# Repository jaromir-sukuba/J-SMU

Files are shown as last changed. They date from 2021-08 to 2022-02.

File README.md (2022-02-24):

## What is SMU?
In case you don't know what is SMU, take a look [here](https://en.wikipedia.org/wiki/Source_measure_unit)
Basically, it's glorified power supply, able to both source voltage (and measure current, with current limit) or source current (and measure voltage, with voltage limit), usually in wide range of voltages and currents. It usually works in four quadrants, meaning it's able to both sink and source power. When set to zero output voltage, SMU acts as ammeter and when set to zero current, acts as voltmeter.
It's very useful as general purpose PSU with precise setpoint adjustment, as a tool for measuring high resistances, for testing semiconductors in wide range of voltages or currents. You can do all this things using classic lab tools (PSU, ammeter, voltmeter, switches), SMU offers this all in single package and is designed to be interconnected with computer to automate the tasks.

## What is in this repository?
+ BOM - Bill Of Material. Contains list of components and materials used in this device. Separated by PCBs.
+ firmware - firmware for two microcontrollers running in JSMU
+ mechanical - mechanical parts I designed for this SMU
+ media - minimal amount of pictures
+ pcb
    + pcb_gerber - gerber data in zip files, ready to be manufactured
    + pcb_ibom - interactive BOM files, helping when populating the boards, also helpful to get familiar with the project
    + pcb_kicad - PCB source files, made in Kicad 5.1.10
    + schematics_pdf - all schematics in PDF format, for easy viewing or printing

## What is JSMU?
JSMU is open source implementation of SMU, inspired by Keithley 236 and Dave Erickson's [DIY SMU](http://www.djerickson.com/diy_smu/index.html)

## How to use it?
User and calibration guide is in the process and will be released soon(TM).

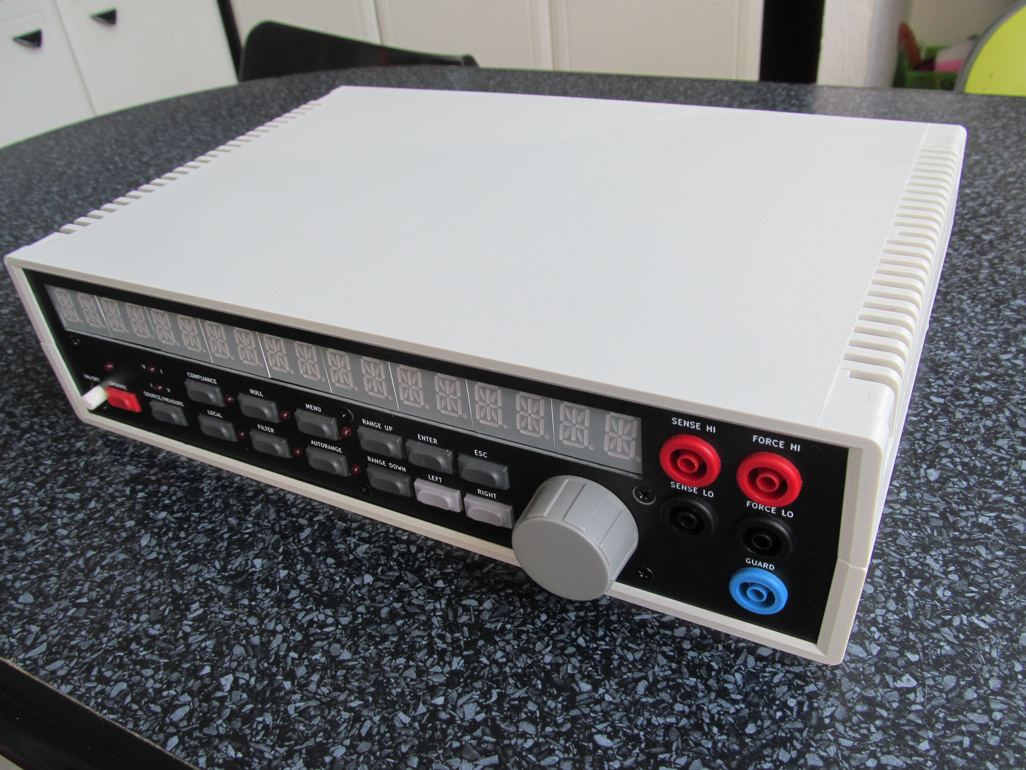
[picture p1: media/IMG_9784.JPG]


Parameters:
+ Voltage ranges 12V and 120V (bipolar)
+ Current ranges 1uA, 10uA, 100uA, 1mA, 10mA, 100mA (bipolar)
+ Minimal set voltage step - 1mV
+ Minimal set current step - 100pA
+ Voltage resolution - 100uV
+ Current resolution - 1pA

JSMU is designed to work as standalone device, but can be connected to computer via USB, and controlled via simple commands in SCPI form, similar to Keithley 2xxx series SMUs.

More pictures can be found in [imgur gallery](https://imgur.com/a/rR8cIFG)

## FAQ
Q: I noticed you used AT90S4434, made in 1999 as controller for your analog board.
- A: Yes, that is correct observation. Two reasons led me to this decision; first of all, I like to do weird design choices from a time to time. Let's call it design dissonances. Secondly, when this design was born (winter 2020/2021-summer 2021) component crisis was (and still is, in the time of writing this) quite strong and I was limited by what components were available. I tried to choose as much components as were available in my junkbox as possible. AT90S4434 can be replaced by AtMega8535 after minor source touchup and recompiling.

Q: dsPIC33FJ128GP306 is also weird choice here
- A: Yes, again, I was fishing in my junkbox. A lot of open-source project go with STM32, but at the time of designing, majority of component suppliers had more-less zero stock of more common STM32's. Once the situation changes, I can think of respinning the D1 board for STM32 and port the code. I already did porting from MC9S08BG60 to dsPIC; perhaps I'll manage another port too.

Q: What is the point of using 14-segment alphanumeric display in 2021, when many test instruments are using graphic LCDs with touchscreens?
- A: Apart from the fact I don't like touch screens on test instruments, I intentionally tried to keep the design in kind-of similar feel than Keithley 236. It's a thing of personal taste.

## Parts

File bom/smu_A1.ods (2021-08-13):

Item | Qty | Reference(s) | Value | Footprint | supplier | link | comment
1 | 16 | C1, C4, C24, C26, C27, C34, C35, C36, C38, C40, C43, C48, C50, C51, C52, C56 | 100n | Capacitor_SMD:C_0805_2012Metric_Pad1.18x1.45mm_HandSolder | GEN | Generic 0805 capacitor
2 | 10 | C2, C3, C5, C6, C9, C10, C11, C12, C13, C14 | 100n | Capacitor_SMD:C_0603_1608Metric_Pad1.08x0.95mm_HandSolder | GEN | Generic 0603 capacitor
3 | 3 | C7, C8, C15 | 22u | Capacitor_Tantalum_SMD:CP_EIA-6032-28_Kemet-C_Pad2.25x2.35mm_HandSolder | TME | https://www.tme.eu/sk/details/293d226x9025c2te3/tantalove-kondenzatory-smd/vishay/
4 | 2 | C16, C17 | 270p | Capacitor_SMD:C_1206_3216Metric_Pad1.33x1.80mm_HandSolder | MOUS | https://www.mouser.sk/ProductDetail/AVX/08055A271JAT2A/?qs=o2Ryk6%252BtLJtmWp8Z%252BRBEFA%3D%3D
5 | 3 | C18, C19, C20 | 15p | Capacitor_SMD:C_0805_2012Metric_Pad1.18x1.45mm_HandSolder | MOUS | https://www.mouser.sk/ProductDetail/TDK/CGA5C4C0G2J271J060AA/?qs=FxQuwy19cyCFaP39URlg4w%3D%3D
6 | 1 | C21 | 10n | Capacitor_SMD:C_0805_2012Metric_Pad1.18x1.45mm_HandSolder | GEN | Generic 0805 capacitor
7 | 2 | C22, C25 | 150p | Capacitor_SMD:C_0805_2012Metric_Pad1.18x1.45mm_HandSolder | MOUS | https://www.mouser.sk/ProductDetail/Yageo/CC0805JRNPOYBN151/?qs=WS5Jv%252B%252Bx1qViSs68xPRhng%3D%3D
8 | 1 | C23 | 22p | Capacitor_SMD:C_1206_3216Metric_Pad1.33x1.80mm_HandSolder | MOUS | https://www.mouser.sk/ProductDetail/TDK/C3216C0G2J221J060AA/?qs=NRhsANhppD%252B8bxP3OkeJTg%3D%3D
9 | 1 | C28 | 270p | Capacitor_SMD:C_0805_2012Metric_Pad1.18x1.45mm_HandSolder | GEN | Generic 0805 capacitor
10 | 3 | C29, C30, C31 | 680p | Capacitor_SMD:C_0805_2012Metric_Pad1.18x1.45mm_HandSolder | GEN | Generic 0805 capacitor
11 | 3 | C32, C33, C37 | 22p | Capacitor_SMD:C_0805_2012Metric_Pad1.18x1.45mm_HandSolder | GEN | Generic 0805 capacitor
12 | 3 | C39, C49, C57 | 1u | Capacitor_SMD:C_0805_2012Metric_Pad1.18x1.45mm_HandSolder | GEN | Generic 0805 capacitor
13 | 1 | C41 | 1u | Capacitor_THT:C_Rect_L7.0mm_W3.5mm_P5.00mm | TME | https://www.tme.eu/sk/details/mks2-1u_50/kondenzatory-tht-polyesterove/wima/mks2b041001c00kssd/
14 | 1 | C42 | 4u7 | Capacitor_Tantalum_SMD:CP_EIA-3216-18_Kemet-A_Pad1.58x1.35mm_HandSolder | TME | https://www.tme.eu/sk/details/t491a475k020at/tantalove-kondenzatory-smd/kemet/
15 | 7 | C44, C45, C46, C47, C53, C54, C55 | 1n | Capacitor_SMD:C_0805_2012Metric_Pad1.18x1.45mm_HandSolder | GEN | Generic 0805 capacitor
16 | 1 | D1 | BAV70 | Package_TO_SOT_SMD:SOT-23 | TME | https://www.tme.eu/sk/details/bav70lt1g/univerzalne-diody-smd/on-semiconductor/
17 | 2 | D2, D3 | BAV99 | Package_TO_SOT_SMD:SOT-23 | TME | https://www.tme.eu/sk/details/bav99lt1g/univerzalne-diody-smd/on-semiconductor/
18 | 4 | D4, D5, D6, D7 | BAV199 | Package_TO_SOT_SMD:SOT-23 | TME | https://www.tme.eu/sk/details/bav199.215/univerzalne-diody-smd/nexperia/
19 | 2 | D8, D9 | LED | LED_SMD:LED_0805_2012Metric_Pad1.15x1.40mm_HandSolder | GEN | Any color you like
20 | 4 | FB1, FB2, FB3, FB4 | Ferrite_Bead_Small | Inductor_SMD:L_0805_2012Metric_Pad1.15x1.40mm_HandSolder | TME | https://www.tme.eu/sk/details/blm31af700sn1l/koraliky-s-feritom/murata/
21 | 4 | H1, H2, H3, H4 | MountingHole | MountingHole:MountingHole_3.2mm_M3_ISO7380_Pad | DNP | DNP
22 | 1 | J1 | Conn_01x03_Male | Connector_Molex:Molex_KK-254_AE-6410-03A_1x03_P2.54mm_Vertical | TME | https://www.tme.eu/sk/details/ns25-w3p/signalove-konektory-raster-2-54mm/ninigi/
23 | 1 | J2 | Conn_01x03_Male | Connector_Molex:Molex_KK-396_A-41791-0003_1x03_P3.96mm_Vertical | TME | https://www.tme.eu/sk/details/a3960wv-03p/signalove-konektory-raster-3-96mm/joint-tech/
24 | 1 | J3 | Conn_01x05_Male | Connector_Molex:Molex_KK-254_AE-6410-05A_1x05_P2.54mm_Vertical | TME | https://www.tme.eu/sk/details/ns25-w5p/signalove-konektory-raster-2-54mm/ninigi/
25 | 1 | J4 | Conn_01x06_Male | Connector_Molex:Molex_KK-396_A-41791-0006_1x06_P3.96mm_Vertical | TME | https://www.tme.eu/sk/details/a3960wv-06p/signalove-konektory-raster-3-96mm/joint-tech/
26 | 1 | J5 | Conn_01x05_Male | Connector_Molex:Molex_KK-396_A-41791-0005_1x05_P3.96mm_Vertical | TME | https://www.tme.eu/sk/details/a3960wv-05p/signalove-konektory-raster-3-96mm/joint-tech/
27 | 1 | J6 | Conn_02x03_Odd_Even | Connector_IDC:IDC-Header_2x03_P2.54mm_Vertical | TME | https://www.tme.eu/sk/details/75869-331lf/konektory-idc/amphenol-icc/
28 | 1 | J7 | Conn_01x06_Male | Connector_PinHeader_2.00mm:PinHeader_1x06_P2.00mm_Vertical | DNP | DNP
29 | 2 | K1, K2 | EC2-5NU | Relay_THT:Relay_DPDT_Kemet_EC2 | MOUS | https://www.mouser.sk/ProductDetail/KEMET/EC2-12NU?qs=BenOyfdfArqRFl%252BOm5Bdvw==
30 | 2 | Q1, Q2 | BC847 | Package_TO_SOT_SMD:SOT-23 | TME | https://www.tme.eu/sk/details/bc847.215/tranzistory-npn-smd/nexperia/ | may use BC817 instead
31 | 9 | R1, R2, R3, R6, R20, R32, R36, R37, R79 | 2k2 | Resistor_SMD:R_0805_2012Metric_Pad1.20x1.40mm_HandSolder | GEN | Generic 0805 resistor
32 | 2 | R4, R5 | 33R | Resistor_SMD:R_0805_2012Metric_Pad1.20x1.40mm_HandSolder | GEN | Generic 0805 resistor
33 | 23 | R7, R8, R9, R10, R11, R12, R28, R31, R33, R34, R35, R63, R64, R66, R68, R70, R71, R73, R74, R75, R76, R77, R78 | 10k00 | Resistor_SMD:R_0805_2012Metric_Pad1.20x1.40mm_HandSolder | TME | https://www.tme.eu/sk/details/era6aeb103v/presne-rezistory-smd-0805/panasonic/
34 | 3 | R13, R14, R16 | 20k | Resistor_SMD:R_0805_2012Metric_Pad1.20x1.40mm_HandSolder | GEN | Generic 0805 resistor
35 | 2 | R15, R26 | 4k7 | Resistor_SMD:R_0805_2012Metric_Pad1.20x1.40mm_HandSolder | GEN | Generic 0805 resistor
36 | 7 | R17, R19, R21, R27, R51, R55, R60 | 10k1 | Resistor_SMD:R_0805_2012Metric_Pad1.20x1.40mm_HandSolder | GEN | Generic 0805 resistor
37 | 1 | R18 | 30k | Resistor_SMD:R_0805_2012Metric_Pad1.20x1.40mm_HandSolder | GEN | Generic 0805 resistor
38 | 1 | R22 | 200k | Resistor_SMD:R_1206_3216Metric_Pad1.30x1.75mm_HandSolder | MOUS | https://www.mouser.sk/ProductDetail/Bourns/CR1206-JW-204ELF/
39 | 3 | R23, R56, R58 | 1k | Resistor_SMD:R_0805_2012Metric_Pad1.20x1.40mm_HandSolder | GEN | Generic 0805 resistor
40 | 1 | R24 | 4k7 | Resistor_SMD:R_1206_3216Metric_Pad1.30x1.75mm_HandSolder | MOUS | https://www.mouser.sk/ProductDetail/Vishay-Dale/CRCW12064K70JNEAC/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
41 | 1 | R25 | 10k1 | Resistor_SMD:R_1206_3216Metric_Pad1.30x1.75mm_HandSolder | MOUS | https://www.mouser.sk/ProductDetail/Vishay-Dale/CRCW120610K0FKEAC/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
42 | 1 | R29 | 300k00 | Resistor_SMD:R_1206_3216Metric_Pad1.30x1.75mm_HandSolder | TME | https://www.tme.eu/sk/details/ar1206-300k-0.1%25/presne-rezistory-smd-1206/viking/ar06btcv3003/
43 | 1 | R30 | 22k10 | Resistor_SMD:R_0805_2012Metric_Pad1.20x1.40mm_HandSolder | TME | https://www.tme.eu/sk/details/arg0805-22k-0.5%25/presne-rezistory-smd-0805/viking/arg05dtc2202/
44 | 1 | R38 | 2M00 | Resistor_SMD:R_1206_3216Metric_Pad1.30x1.75mm_HandSolder | MOUS | https://www.mouser.sk/ProductDetail/TE-Connectivity-Holsworthy/CPF0805B2M0E?qs=CXI0wBT1M2hICTuUd%2FIMfQ%3D%3D
45 | 1 | R39 | 200k00 | Resistor_SMD:R_0805_2012Metric_Pad1.20x1.40mm_HandSolder | MOUS | https://www.mouser.sk/ProductDetail/TE-Connectivity-Holsworthy/RQ73C2A200KBTDF
46 | 1 | R40 | 20k5 | Resistor_SMD:R_0805_2012Metric_Pad1.20x1.40mm_HandSolder | MOUS | https://www.mouser.sk/ProductDetail/Yageo/RT0805BRD0720K5L/?qs=Q0GlgB%252BOca%252BxfnVdr3eu0w%3D%3D
47 | 2 | R41, R83 | 2k00 | Resistor_SMD:R_0805_2012Metric_Pad1.20x1.40mm_HandSolder | TME | https://www.tme.eu/sk/details/ar0805-2k-0.1%25/presne-rezistory-smd-0805/viking/ar05btcw2001/
48 | 1 | R42 | 200R00 | Resistor_SMD:R_MiniMELF_MMA-0204 | MOUS | https://www.mouser.sk/ProductDetail/Vishay-Beyschlag/MMA02040E2000BB300?qs=YmMt7wOBEV7xAuhhDxeBhQ==
49 | 4 | R43, R44, R45, R46 | 78R | Resistor_SMD:R_1206_3216Metric_Pad1.30x1.75mm_HandSolder | MOUS | https://www.mouser.sk/ProductDetail/TE-Connectivity-Holsworthy/RP73D2B78R7BTG
50 | 4 | R47, R48, R49, R50 | 4R70 | Resistor_SMD:R_2512_6332Metric | DNP | DNP
51 | 2 | R52, R54 | 100k00 | Resistor_SMD:R_0805_2012Metric_Pad1.20x1.40mm_HandSolder | MOUS | https://www.mouser.sk/ProductDetail/TE-Connectivity-Holsworthy/RQ73C2A100KBTD?qs=gZXFycFWdAMRVPmJtg9N9A%3D%3D
52 | 2 | R53, R57 | 250k00 | Resistor_SMD:R_0805_2012Metric_Pad1.20x1.40mm_HandSolder | MOUS | https://www.mouser.sk/ProductDetail/TE-Connectivity-Holsworthy/RQ73C2A249KBTDF
53 | 1 | R59 | 1k | Resistor_THT:R_Axial_DIN0309_L9.0mm_D3.2mm_P12.70mm_Horizontal | TME | https://www.tme.eu/sk/details/pr01-1k/metalizovane-rezistory-tht-1w/vishay/pr01000101001ja100/
54 | 2 | R61, R62 | 680R | Resistor_SMD:R_0805_2012Metric_Pad1.20x1.40mm_HandSolder | GEN | Generic 0805 resistor
55 | 1 | R65 | 2R2 | Resistor_SMD:R_0805_2012Metric_Pad1.20x1.40mm_HandSolder | GEN | Generic 0805 resistor
56 | 4 | R67, R69, R81, R82 | 21k50 | Resistor_SMD:R_0805_2012Metric_Pad1.20x1.40mm_HandSolder | MOUS | https://www.mouser.sk/ProductDetail/Yageo/RT0805BRD0721K5L/?qs=4CyHz7GXqSgMQiImMmG4dg%3D%3D
57 | 1 | R72 | 1M6 | Resistor_SMD:R_0805_2012Metric_Pad1.20x1.40mm_HandSolder | DNP | DNP
58 | 1 | R80 | 20k50 | Resistor_SMD:R_0805_2012Metric_Pad1.20x1.40mm_HandSolder | MOUS | https://www.mouser.sk/ProductDetail/Yageo/RT0805BRD0720K5L/?qs=Q0GlgB%252BOca%252BxfnVdr3eu0w%3D%3D
59 | 1 | U1 | uA7805 | Package_TO_SOT_SMD:TO-263-3_TabPin2 | TME | https://www.tme.eu/sk/details/l7805abd2t/stabilizatory-napatia-neregulovane/stmicroelectronics/l7805abd2t-tr/
60 | 1 | U2 | DG411xY | Package_SO:SOIC-16_3.9x9.9mm_P1.27mm | TME | https://www.tme.eu/sk/details/dg444dy/multiplexory-a-analogove-prepinace/vishay/
61 | 2 | U3, U28 | OPA202 | Package_SO:SOIC-8_3.9x4.9mm_P1.27mm | MOUS | https://www.mouser.sk/ProductDetail/Texas-Instruments/OPA202IDR
62 | 11 | U4, U5, U6, U8, U9, U10, U11, U13, U14, U19, U20 | OPA140 | Package_SO:SOIC-8_3.9x4.9mm_P1.27mm | MOUS | https://www.mouser.sk/ProductDetail/Texas-Instruments/OPA140AIDR/?qs=nHis3Socmoq8P2a2dEtOew%3D%3D
63 | 1 | U7 | LM393 | Package_SO:SOIC-8_3.9x4.9mm_P1.27mm | TME | https://www.tme.eu/sk/details/lm393dt/komparatory-smd/stmicroelectronics/
64 | 1 | U12 | TLP170D | Package_SO:SO-4_4.4x3.9mm_P2.54mm | MOUS | https://www.mouser.sk/ProductDetail/Toshiba/TLP170DF/?qs=sRdS99IVWC82vTD8bl8sFg%3D%3D
65 | 2 | U15, U16 | DG444 | Package_SO:SOIC-16_3.9x9.9mm_P1.27mm | TME | https://www.tme.eu/sk/details/dg444dy/multiplexory-a-analogove-prepinace/vishay/
66 | 1 | U17 | AQY221R | Package_SO:SO-4_4.4x3.9mm_P2.54mm | MOUS | https://www.mouser.sk/ProductDetail/Panasonic-Industrial-Devices/AQY221R2SX/?qs=Wn4D5qJAqBI5HElhh1lUZQ%3D%3D
67 | 1 | U18 | DNP | Package_SO:SO-4_4.4x3.9mm_P2.54mm | DNP | DNP
68 | 1 | U21 | TL071 | Package_SO:SOIC-8_3.9x4.9mm_P1.27mm | TME | https://www.tme.eu/sk/details/tl071acd/operacne-zosilnovace-smd/texas-instruments/
69 | 1 | U22 | ISO7341C | Package_SO:SOIC-16W_7.5x10.3mm_P1.27mm | MOUS | https://www.mouser.sk/ProductDetail/Texas-Instruments/ISO7341CDW?qs=asCBFxFfL1QXhBq0uR%2FJmA%3D%3D
70 | 1 | U23 | ATmega8535-16JU | Package_LCC:PLCC-44 | MOUS | https://www.mouser.sk/ProductDetail/Microchip-Technology-Atmel/ATMEGA8535L-8JUR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
71 | 1 | U24 | MAX6225 | Package_DIP:DIP-8_W7.62mm_Socket | MOUS | https://www.mouser.sk/ProductDetail/Maxim-Integrated/MAX6225ACPA%2b?qs=GxOUx7aO6nyrNG4h06TzmA%3D%3D | Other alernatives are possible, I used this because I had it in my junkbox
72 | 1 | U25 | OPA2333 | Package_SO:SOIC-8_3.9x4.9mm_P1.27mm | MOUS | https://www.mouser.sk/ProductDetail/Texas-Instruments/OPA2333AID?qs=7nS3%252BbEUL6s6Q5%2FuexU7%252Bg%3D%3D
73 | 1 | U26 | LTC2057 | Package_SO:SOIC-8_3.9x4.9mm_P1.27mm | MOUS | https://www.mouser.sk/ProductDetail/Analog-Devices/LTC2057IS8PBF?qs=hVkxg5c3xu96mZ%252BCpnMNfA%3D%3D
74 | 1 | U27 | AD5686 | Package_SO:TSSOP-16_4.4x5mm_P0.65mm | MOUS | https://www.mouser.sk/ProductDetail/Analog-Devices/AD5686ARUZ?qs=NmRFExCfTkE223vD8YE3tA%3D%3D
75 | 2 | U29, U30 | OP07 | Package_SO:SOIC-8_3.9x4.9mm_P1.27mm | TME | https://www.tme.eu/sk/details/op07cdr/operacne-zosilnovace-smd/texas-instruments/
76 | 1 | U31 | CPC1018N | Package_SO:SO-4_4.4x3.9mm_P2.54mm | MOUS | https://www.mouser.sk/ProductDetail/IXYS-Integrated-Circuits/CPC1018N/?qs=mzRxyRlhVdtKZF03PS27Mg%3D%3D
77 | 1 | U32 | ad7177 | Package_SO:TSSOP-24_4.4x7.8mm_P0.65mm | MOUS | https://www.mouser.sk/ProductDetail/Analog-Devices/AD7177-2BRUZ?qs=251aVPftrjH6MVeTWiYQww%3D%3D
78 | 1 | Y1 | Crystal | Crystal:Crystal_HC49-4H_Vertical | TME | https://www.tme.eu/sk/details/7.3728m-49s-sr/krystalove-rezonatory-tht/sr-passives/

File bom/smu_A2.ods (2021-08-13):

Item | Qty | Reference(s) | Value | Footprint | supplier | link | comment
1 | 4 | C1, C2, C5, C6 | 1n | Capacitor_SMD:C_1206_3216Metric_Pad1.33x1.80mm_HandSolder | TME | https://www.tme.eu/sk/details/c1206c102jcgactu/kondenzatory-mlcc-smd-1206/kemet/
2 | 2 | C3, C4 | 2n2 | Capacitor_SMD:C_1206_3216Metric_Pad1.33x1.80mm_HandSolder | TME | https://www.tme.eu/sk/details/c1206c222jbgactu/kondenzatory-mlcc-smd-1206/kemet/
3 | 1 | C7 | 2n2 | Capacitor_THT:C_Axial_L19.0mm_D7.5mm_P25.00mm_Horizontal | TBD
4 | 2 | D1, D2 | BAV99 | Package_TO_SOT_SMD:SOT-23 | TME | https://www.tme.eu/sk/details/bav99lt1g/univerzalne-diody-smd/on-semiconductor/
5 | 4 | D3, D4, D5, D6 | BAV199 | Package_TO_SOT_SMD:SOT-23 | TME | https://www.tme.eu/sk/details/bav199.215/univerzalne-diody-smd/nexperia/
6 | 2 | D7, D8 | 1N4007 | Diode_THT:D_DO-41_SOD81_P10.16mm_Horizontal | TME | https://www.tme.eu/sk/details/1n4007/univerzalne-diody-tht/
7 | 4 | H1, H2, H3, H4 | MountingHole | MountingHole:MountingHole_3.2mm_M3_ISO14580_Pad | DNP | DNP
8 | 1 | J1 | Conn_01x06_Male | Connector_Molex:Molex_KK-396_A-41791-0006_1x06_P3.96mm_Vertical | TME | https://www.tme.eu/sk/details/a3960wv-06p/signalove-konektory-raster-3-96mm/joint-tech/
9 | 1 | J2 | Conn_01x03_Male | Connector_Molex:Molex_KK-396_A-41791-0003_1x03_P3.96mm_Vertical | TME | https://www.tme.eu/sk/details/a3960wv-03p/signalove-konektory-raster-3-96mm/joint-tech/
10 | 4 | Q1, Q2, Q9, Q10 | 2N7002 | Package_TO_SOT_SMD:SOT-23 | TME | https://www.tme.eu/sk/details/2n7002/tranzistory-s-kanalom-n-smd/on-semiconductor/
11 | 3 | Q3, Q4, Q8 | BC807 | Package_TO_SOT_SMD:SOT-23 | TME | https://www.tme.eu/sk/details/bc807-16-7-f/tranzistory-pnp-smd/diodes-incorporated/bc807-16/
12 | 1 | Q5 | BC160 | Package_TO_SOT_THT:TO-39-3 | TME | https://www.tme.eu/sk/details/bc160-10-cdi/tranzistory-pnp-tht/cdil/bc160-10/
13 | 1 | Q6 | BC140 | Package_TO_SOT_THT:TO-39-3 | TME | https://www.tme.eu/sk/details/bc140-10-cdi/tranzistory-npn-tht/cdil/bc140-10/
14 | 1 | Q7 | BC817 | Package_TO_SOT_SMD:SOT-23 | TME | https://www.tme.eu/sk/details/bc817-16-7-f/tranzistory-npn-smd/diodes-incorporated/bc817-16/
15 | 2 | Q11, Q12 | IRF620 | Package_TO_SOT_THT:TO-220-3_Vertical | TME | https://www.tme.eu/sk/details/irf620pbf/tranzistory-s-kanalom-n-tht/vishay/
16 | 2 | Q13, Q14 | IRF9620 | Package_TO_SOT_THT:TO-220-3_Vertical | TME | https://www.tme.eu/sk/details/irf9620pbf/tranzistory-s-kanalom-p-tht/vishay/
17 | 1 | Q15 | TIP41 | Package_TO_SOT_THT:TO-220-3_Vertical | MOUS | https://www.mouser.sk/ProductDetail/STMicroelectronics/TIP41C/?qs=ljbEvF4DwOPALsfJVTZHww%3D%3D
18 | 1 | Q16 | TIP42 | Package_TO_SOT_THT:TO-220-3_Vertical | MOUS | https://www.mouser.sk/ProductDetail/STMicroelectronics/TIP42C/?qs=ljbEvF4DwONRQQLu%2Fjht%252Bw%3D%3D
19 | 2 | Q17, Q18 | IRF7403 | Package_SO:SOIC-8_3.9x4.9mm_P1.27mm | MOUS | https://www.tme.eu/sk/details/irf7403trpbf/tranzistory-s-kanalom-n-smd/infineon-technologies/
20 | 4 | R1, R2, R29, R30 | 1k | Capacitor_SMD:C_0805_2012Metric_Pad1.18x1.45mm_HandSolder | GEN | Generic 0805 resistor
21 | 6 | R3, R4, R5, R6, R7, R8 | 47k | Capacitor_SMD:C_0805_2012Metric_Pad1.18x1.45mm_HandSolder | GEN | Generic 0805 resistor
22 | 2 | R9, R10 | 22k | Capacitor_SMD:C_0805_2012Metric_Pad1.18x1.45mm_HandSolder | GEN | Generic 0805 resistor
23 | 1 | R11 | 1k | Resistor_SMD:R_0805_2012Metric_Pad1.20x1.40mm_HandSolder | GEN | Generic 0805 resistor
24 | 4 | R12, R13, R31, R32 | 2k2 | Resistor_THT:R_Axial_DIN0309_L9.0mm_D3.2mm_P15.24mm_Horizontal | TME | https://www.tme.eu/sk/details/pr02-2k2/metalizovane-rezistory-tht-2w/vishay/pr02000202201ja100/
25 | 1 | R14 | 220R | Resistor_SMD:R_0805_2012Metric_Pad1.20x1.40mm_HandSolder | GEN | Generic 0805 resistor
26 | 2 | R15, R16 | DNP | Capacitor_SMD:C_0805_2012Metric_Pad1.18x1.45mm_HandSolder | DNP | DNP
27 | 4 | R17, R18, R21, R22 | 2M2 | Resistor_SMD:R_1206_3216Metric_Pad1.30x1.75mm_HandSolder | MOUS | https://www.mouser.sk/ProductDetail/Vishay-Dale/CRCW12062M20FKEA/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
28 | 2 | R19, R20 | 1M | Resistor_SMD:R_1206_3216Metric_Pad1.30x1.75mm_HandSolder | MOUS | https://www.mouser.sk/ProductDetail/Vishay-Dale/CRCW12061M00FKEA/
29 | 4 | R23, R24, R25, R26 | 47R | Capacitor_SMD:C_0805_2012Metric_Pad1.18x1.45mm_HandSolder | GEN | Generic 0805 resistor
30 | 2 | R27, R28 | 220R | Capacitor_SMD:C_0805_2012Metric_Pad1.18x1.45mm_HandSolder | GEN | Generic 0805 resistor
31 | 2 | R33, R34 | 22R | Resistor_THT:R_Axial_DIN0309_L9.0mm_D3.2mm_P15.24mm_Horizontal | TME | https://www.tme.eu/sk/details/pr02-22r/metalizovane-rezistory-tht-2w/vishay/pr02000202209ja100/

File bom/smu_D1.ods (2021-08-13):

Item | Qty | Reference(s) | Value | Footprint | supplier | link | comment
1 | 2 | C1, C11 | 10u | Capacitor_SMD:C_0805_2012Metric_Pad1.18x1.45mm_HandSolder | GEN | Generic 0805 capacitor
2 | 1 | C2 | CP | Capacitor_THT:C_Radial_D8.0mm_H11.5mm_P3.50mm | TBD |  | 1mF/35V
3 | 6 | C3, C4, C5, C10, C14, C15 | 100n | Capacitor_SMD:C_0805_2012Metric_Pad1.18x1.45mm_HandSolder | GEN | Generic 0805 capacitor
4 | 2 | C6, C8 | 47u | Capacitor_Tantalum_SMD:CP_EIA-6032-28_Kemet-C_Pad2.25x2.35mm_HandSolder | TME | https://www.tme.eu/sk/details/293d226x9020c2te3/tantalove-kondenzatory-smd/vishay/ | Used 22uF
5 | 2 | C7, C9 | 10n | Capacitor_SMD:C_0805_2012Metric_Pad1.18x1.45mm_HandSolder | GEN | Generic 0805 capacitor
6 | 2 | C12, C13 | 22p | Capacitor_SMD:C_0805_2012Metric_Pad1.18x1.45mm_HandSolder | GEN | Generic 0805 capacitor
7 | 5 | D1, D2, D3, D4, D6 | SM4007 | Diode_SMD:D_MELF | TME | https://www.tme.eu/sk/details/sm4007/univerzalne-diody-smd/dc-components/
8 | 2 | D5, D8 | D_Zener | Diode_SMD:D_MiniMELF | TME | https://www.tme.eu/sk/details/tzmb4v3-gs08/zenerove-diody-smd/vishay/
9 | 1 | D7 | B340 | Diode_SMD:D_SMB_Handsoldering | MOUS | https://www.mouser.sk/ProductDetail/Vishay-General-Semiconductor/B340LB-E3-52T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
10 | 3 | D9, D10, D11 | LED | LED_SMD:LED_0805_2012Metric_Pad1.15x1.40mm_HandSolder | GEN | Any color you like
11 | 4 | H1, H2, H3, H4 | MountingHole | MountingHole:MountingHole_3.2mm_M3_Pad | DNP | DNP
12 | 2 | J1, J5 | Conn_01x05_Male | Connector_Molex:Molex_KK-254_AE-6410-05A_1x05_P2.54mm_Vertical | GEN | 01x05 horizontal pinheader
13 | 1 | J2 | Conn_01x04_Male | Connector_PinHeader_2.54mm:PinHeader_1x04_P2.54mm_Vertical | GEN | vertical pinheader
14 | 1 | J3 | Conn_01x02_Male | Connector_Molex:Molex_KK-396_A-41791-0002_1x02_P3.96mm_Vertical | TME | https://www.tme.eu/sk/details/a3960wr-02p/signalove-konektory-raster-3-96mm/joint-tech/
15 | 1 | J4 | Conn_02x08_Odd_Even | Connector_PinHeader_2.54mm:PinHeader_2x08_P2.54mm_Vertical | GEN | vertical pinheader
16 | 2 | J6, J7 | Conn_01x02_Male | Connector_PinHeader_2.54mm:PinHeader_1x02_P2.54mm_Horizontal | GEN | 01x02 horizontal pinheader
17 | 1 | J8 | Conn_01x05_Male | Connector_PinHeader_2.54mm:PinHeader_1x05_P2.54mm_Horizontal | GEN | 01x05 horizontal pinheader
18 | 1 | L1 | L | Inductor_SMD:L_Bourns_SRP7028A_7.3x6.6mm | MOUS | https://www.mouser.sk/ProductDetail/Bourns/SRP7028A-330M/
19 | 2 | Q1, Q2 | BC817 | Package_TO_SOT_SMD:SOT-23 | TME | https://www.tme.eu/sk/details/bc817-16-7-f/tranzistory-npn-smd/diodes-incorporated/bc817-16/
20 | 4 | R1, R2, R5, R6 | 2k2 | Resistor_SMD:R_0805_2012Metric_Pad1.20x1.40mm_HandSolder | GEN | Generic 0805 resistor
21 | 3 | R3, R7, R10 | 10k | Resistor_SMD:R_0805_2012Metric_Pad1.20x1.40mm_HandSolder | GEN | Generic 0805 resistor
22 | 1 | R4 | 5k6 | Resistor_SMD:R_0805_2012Metric_Pad1.20x1.40mm_HandSolder | GEN | Generic 0805 resistor
23 | 1 | R8 | 1M | Resistor_SMD:R_0805_2012Metric_Pad1.20x1.40mm_HandSolder | GEN | Generic 0805 resistor
24 | 1 | R9 | 1k | Resistor_SMD:R_0805_2012Metric_Pad1.20x1.40mm_HandSolder | GEN | Generic 0805 resistor
25 | 3 | R11, R12, R13 | 510R | Resistor_SMD:R_0805_2012Metric_Pad1.20x1.40mm_HandSolder | GEN | Generic 0805 resistor
26 | 1 | U1 | L7808 | Package_TO_SOT_SMD:TO-263-3_TabPin2 | TME | https://www.tme.eu/sk/details/l7808abd2t/stabilizatory-napatia-neregulovane/stmicroelectronics/l7808abd2t-tr/
27 | 1 | U2 | TPS5420D | Package_SO:SOIC-8_3.9x4.9mm_P1.27mm | MOUS | https://www.mouser.sk/ProductDetail/Texas-Instruments/TPS5420DR/?qs=quKhnJqH4Fh76xi%252BV1pdZQ%3D%3D
28 | 1 | U3 | PIC24FJxxGA006 | Package_QFP:LQFP-64_10x10mm_P0.5mm | MOUS | https://www.mouser.sk/ProductDetail/Microchip-Technology/dsPIC33FJ128GP306A-I-PT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
29 | 1 | U4 | 25LCxxx | Package_SO:SOIC-8_3.9x4.9mm_P1.27mm | MOUS | https://www.mouser.sk/ProductDetail/Microchip-Technology/25AA256-E-SN?qs=WOIyg0mTyodJJGdwUA%2Fodg%3D%3D
30 | 1 | U5 | MC9S08GB60A | Package_QFP:LQFP-64_10x10mm_P0.5mm | DNP | DNP
31 | 1 | Y1 | Crystal | Crystal:Crystal_HC49-4H_Vertical | TME | https://www.tme.eu/sk/details/5m-49s-sr/krystalove-rezonatory-tht/sr-passives/

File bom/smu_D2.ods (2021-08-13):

Item | Qty | Reference(s) | Value | Footprint | supplier | link | comment
1 | 1 | C1 | 10u | Capacitor_SMD:C_0805_2012Metric_Pad1.18x1.45mm_HandSolder | GEN |  | Generic 0805 capacitor
2 | 2 | C2, C3 | 1n | Capacitor_SMD:C_0805_2012Metric_Pad1.18x1.45mm_HandSolder | GEN |  | Generic 0805 capacitor
3 | 1 | C4 | 10n | Capacitor_SMD:C_0805_2012Metric_Pad1.18x1.45mm_HandSolder | GEN |  | Generic 0805 capacitor
4 | 1 | C5 | 47u | Capacitor_Tantalum_SMD:CP_EIA-6032-28_Kemet-C_Pad2.25x2.35mm_HandSolder | TME | https://www.tme.eu/sk/details/293d226x9020c2te3/tantalove-kondenzatory-smd/vishay/ | Used 22uF
5 | 4 | C6, C7, C8, C11 | 100n | Capacitor_SMD:C_0805_2012Metric_Pad1.18x1.45mm_HandSolder | GEN |  | Generic 0805 capacitor
6 | 2 | C9, C10 | 100n | Capacitor_SMD:C_0805_2012Metric_Pad1.18x1.45mm_HandSolder | GEN |  | Generic 0805 capacitor
7 | 2 | C12, C13 | 470u | Capacitor_THT:CP_Radial_D6.3mm_P2.50mm | TME | https://www.tme.eu/sk/details/uvz1a471med/elektrolyticke-kondenzatory-tht-105degc/nichicon/
8 | 1 | D1 | B340 | Diode_SMD:D_SMB_Handsoldering | MOUS | https://www.mouser.sk/ProductDetail/Vishay-General-Semiconductor/B340LB-E3-52T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
9 | 9 | D2, D3, D4, D5, D6, D7, D8, D9, D10 | LED | LED_THT:LED_D3.0mm | GEN |  | Any color you like
10 | 3 | D11, D12, D13 | LL4148 | Diode_SMD:D_MiniMELF | GEN |  | Any color you like
11 | 6 | H1, H2, H3, H4, H5, H6 | MountingHole | MountingHole:MountingHole_3.2mm_M3_Pad | DNP | DNP
12 | 1 | J2 | Conn_02x08_Odd_Even | Connector_PinHeader_2.54mm:PinHeader_2x08_P2.54mm_Vertical | GEN |  | receptacle
13 | 1 | J3 | Conn_01x04_Male | Connector_PinHeader_2.54mm:PinHeader_1x04_P2.54mm_Vertical | GEN |  | receptacle
14 | 1 | L1 | L | Inductor_SMD:L_Bourns_SRP7028A_7.3x6.6mm | MOUS | https://www.mouser.sk/ProductDetail/Bourns/SRP7028A-330M/
15 | 9 | LED1, LED2, LED3, LED4, LED5, LED6, LED7, LED8, LED9 | DISP_LTP3786 | j_lib:DISP_LED_18 | TME | https://www.tme.eu/sk/details/ltp-3786e/dvojmiestne-led-displeje/liteon/
16 | 6 | Q1, Q2, Q3, Q4, Q5, Q6 | IRLML6402 | Package_TO_SOT_SMD:SOT-23 | TME | https://www.tme.eu/sk/details/irlml5203trpbf/tranzistory-s-kanalom-p-smd/infineon-technologies/
17 | 5 | R1, R2, R3, R4, R5 | 10k | Resistor_SMD:R_0805_2012Metric_Pad1.20x1.40mm_HandSolder | GEN |  | Generic 0805 resistor
18 | 1 | R6 | 6K8 | Resistor_SMD:R_0805_2012Metric_Pad1.20x1.40mm_HandSolder | GEN |  | Generic 0805 resistor
19 | 9 | R7, R8, R9, R10, R11, R12, R13, R14, R15 | 510 | Resistor_SMD:R_0805_2012Metric_Pad1.20x1.40mm_HandSolder | GEN |  | Generic 0805 resistor
20 | 3 | R16, R17, R18 | 1k5 | Resistor_SMD:R_0805_2012Metric_Pad1.20x1.40mm_HandSolder | GEN |  | Generic 0805 resistor
21 | 1 | SW1 | Rotary_Encoder | Rotary_Encoder:RotaryEncoder_Alps_EC12E_Vertical_H20mm_CircularMountingHoles | MOUS | https://www.mouser.sk/ProductDetail/Bourns/PEC12R-4220F-N0024/?qs=Zq5ylnUbLm5A%252BWQs5Q2ZbQ%3D%3D
22 | 14 | SW2, SW3, SW4, SW5, SW6, SW7, SW8, SW9, SW10, SW11, SW12, SW13, SW14, SW15 | SW_Push | j_lib:MQ_6450 | MOUS | https://www.mouser.sk/Search/Refine?Keyword=marquardt+6450
23 | 1 | U3 | TPS5420D | Package_SO:SOIC-8_3.9x4.9mm_P1.27mm | MOUS | https://www.mouser.sk/ProductDetail/Texas-Instruments/TPS5420DR/?qs=quKhnJqH4Fh76xi%252BV1pdZQ%3D%3D
24 | 1 | U4 | 74HC14 | Package_SO:SOIC-14_3.9x8.7mm_P1.27mm | TME | https://www.tme.eu/sk/details/mc74hc14adg/cleny-invertory/on-semiconductor/
25 | 1 | U5 | MCP23S17_SO | Package_SO:SOIC-28W_7.5x17.9mm_P1.27mm | TME | https://www.tme.eu/sk/details/mcp23s17-e_so/multiplexory-a-analogove-prepinace/microchip-technology/
26 | 3 | U6, U7, U8 | STP16CP05 | Package_SO:SSOP-24_3.9x8.7mm_P0.635mm | MOUS | https://www.mouser.sk/ProductDetail/STMicroelectronics/STP16CP05TTR?qs=%252BFmDY%2FmH7IYvcBEvWgB%2FVQ%3D%3D | Alternative – https://www.tme.eu/sk/details/sct2024cssg/drivery-led/starchips-technology/
27 | 1 | U9 | 74LS138 | Package_SO:SO-16_3.9x9.9mm_P1.27mm | TME | https://www.tme.eu/sk/details/74hc138d.652/dekodery-multiplexory-spinace/nexperia/

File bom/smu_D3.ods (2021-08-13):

Item | Qty | Reference(s) | Value | Footprint | supplier | link | comment
1 | 3 | C1, C4, C6 | 100n | Capacitor_SMD:C_0805_2012Metric_Pad1.18x1.45mm_HandSolder | GEN |  | Generic 0805 capacitor
2 | 2 | C2, C3 | 47p | Capacitor_SMD:C_0805_2012Metric_Pad1.18x1.45mm_HandSolder | GEN |  | Generic 0805 capacitor
3 | 1 | C5 | 1u | Capacitor_SMD:C_0805_2012Metric_Pad1.18x1.45mm_HandSolder | GEN |  | Generic 0805 capacitor
4 | 1 | FB1 | Ferrite_Bead_Small | Inductor_SMD:L_0805_2012Metric_Pad1.05x1.20mm_HandSolder | TME | https://www.tme.eu/sk/details/blm31af700sn1l/koraliky-s-feritom/murata/
5 | 2 | H1, H2 | MountingHole | MountingHole:MountingHole_3.2mm_M3_ISO7380_Pad | DNP | DNP
6 | 1 | J1 | USB_B | Connector_USB:USB_B_TE_5787834_Vertical | MOUS | https://eu.mouser.com/ProductDetail/Wurth-Elektronik/61400413321?qs=rS3zZhy2AQPX0EcryzeSDw%3D%3D
7 | 2 | J2, J3 | Conn_01x05_Male | Connector_Molex:Molex_KK-254_AE-6410-05A_1x05_P2.54mm_Vertical | MOUS | https://www.tme.eu/sk/details/ns25-w5p/signalove-konektory-raster-2-54mm/ninigi/
8 | 2 | R1, R2 | 27R | Resistor_SMD:R_0805_2012Metric_Pad1.20x1.40mm_HandSolder | GEN |  | Generic 0805 resistor
9 | 2 | R3, R6 | 100R | Resistor_SMD:R_0805_2012Metric_Pad1.20x1.40mm_HandSolder | GEN |  | Generic 0805 resistor
10 | 1 | R4 | 10k | Resistor_SMD:R_0805_2012Metric_Pad1.20x1.40mm_HandSolder | GEN |  | Generic 0805 resistor
11 | 2 | R5, R7 | 22k | Resistor_SMD:R_0805_2012Metric_Pad1.20x1.40mm_HandSolder | GEN |  | Generic 0805 resistor
12 | 1 | U1 | FT230XS | Package_SO:SSOP-16_3.9x4.9mm_P0.635mm | MOUS | https://www.tme.eu/sk/details/ft230xs-r/integrovane-obvody-interface-usb/ftdi/

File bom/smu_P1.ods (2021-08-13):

Item | Qty | Reference(s) | Value | Footprint | supplier | link | comment
1 | 2 | C1, C2 | 1u | Capacitor_THT:C_Rect_L16.5mm_W7.0mm_P15.00mm_MKT | TME | https://www.tme.eu/sk/details/mpem-1ur20_250/kondenzatory-tht-polyesterove/sr-passives/
2 | 2 | C3, C4 | 390u | Capacitor_THT:CP_Radial_D18.0mm_P7.50mm | TME | https://www.tme.eu/sk/details/ucy2d391mhd/elektrolyticke-kondenzatory-tht-105degc/nichicon/
3 | 4 | C5, C6, C7, C8 | 470u | Capacitor_THT:CP_Radial_D13.0mm_P5.00mm | TME | https://www.tme.eu/sk/details/uvy1v102mhd/elektrolyticke-kondenzatory-tht-105degc/nichicon/
4 | 2 | C9, C10 | 22u | Capacitor_THT:CP_Radial_D6.3mm_P2.50mm | TME | https://www.tme.eu/sk/details/uld1j220med1td/elektrolyticke-kondenzatory-tht-105degc/nichicon/
5 | 12 | D1, D2, D3, D4, D5, D6, D7, D8, D9, D10, D11, D12 | 1N4007 | Diode_THT:D_DO-41_SOD81_P10.16mm_Horizontal | TME | https://www.tme.eu/sk/details/1n4007/univerzalne-diody-tht/
6 | 2 | D13, D14 | 15V | Diode_THT:D_DO-41_SOD81_P10.16mm_Horizontal | TME | https://www.tme.eu/sk/details/zpy15-tap/zenerove-diody-tht/vishay/
7 | 4 | H1, H2, H3, H4 | MountingHole | MountingHole:MountingHole_3.2mm_M3_ISO7380_Pad | DNP | DNP
8 | 1 | J1 | Conn_01x05_Male | Connector_Molex:Molex_KK-396_A-41791-0005_1x05_P3.96mm_Vertical | TME | https://www.tme.eu/sk/details/a3960wv-05p/signalove-konektory-raster-3-96mm/joint-tech/
9 | 3 | J2, J3, J5 | Conn_01x03_Male | Connector_Molex:Molex_KK-396_A-41791-0003_1x03_P3.96mm_Vertical | TME | https://www.tme.eu/sk/details/a3960wv-03p/signalove-konektory-raster-3-96mm/joint-tech/
10 | 1 | J4 | Conn_01x03_Male | Connector_Molex:Molex_KK-254_AE-6410-03A_1x03_P2.54mm_Vertical | TME | https://www.tme.eu/sk/details/ns25-w3p/signalove-konektory-raster-2-54mm/ninigi/
11 | 1 | K1 | Fujitsu_FTR-F1C | Relay_THT:Relay_DPDT_Fujitsu_FTR-F1C | TME | https://www.tme.eu/sk/details/ftr-f1ca024v/elektromagneticke-rele-miniaturne/fujitsu/
12 | 2 | R1, R2 | 33R | Resistor_THT:R_Axial_DIN0309_L9.0mm_D3.2mm_P15.24mm_Horizontal | TME | https://www.tme.eu/sk/details/1w-33r/metalizovane-rezistory-tht-1w/royal-ohm/mor01sj0330a10/
13 | 2 | R3, R5 | 22k | Resistor_THT:R_Axial_DIN0411_L9.9mm_D3.6mm_P15.24mm_Horizontal | TME | https://www.tme.eu/sk/details/pr02-22k/metalizovane-rezistory-tht-2w/vishay/pr02000202202ja100/
14 | 2 | R4, R6 | 10k | Resistor_THT:R_Axial_DIN0309_L9.0mm_D3.2mm_P15.24mm_Horizontal | TME | https://www.tme.eu/sk/details/1w-10k/metalizovane-rezistory-tht-1w/royal-ohm/mor01sj0103a10/
15 | 1 | U1 | L7815 | Package_TO_SOT_THT:TO-220-3_Vertical | TME | https://www.tme.eu/sk/details/l7815acv/stabilizatory-napatia-neregulovane/stmicroelectronics/
16 | 1 | U2 | L7915 | Package_TO_SOT_THT:TO-220-3_Vertical | TME | https://www.tme.eu/sk/details/l7915acv/stabilizatory-napatia-neregulovane/stmicroelectronics/

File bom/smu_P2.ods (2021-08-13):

Item | Qty | Reference(s) | Value | Footprint | supplier | link | comment
1 | 1 | F1 | Fuse | Fuse:Fuseholder_Cylinder-5x20mm_Schurter_0031_8201_Horizontal_Open | TME | https://www.tme.eu/sk/details/0031.8201/poistkove-puzdra-pcb/schurter/ | add two more components marked *
2 | 4 | H1, H2, H3, H4 | MountingHole | MountingHole:MountingHole_3.2mm_M3_ISO7380_Pad | DNP | DNP
3 | 2 | J1, J2 | Conn_01x05_Male | Connector_Molex:Molex_KK-396_A-41791-0005_1x05_P3.96mm_Vertical | TME | https://www.tme.eu/sk/details/a3960wv-05p/signalove-konektory-raster-3-96mm/joint-tech/
4 | 1 | SW1 | SW_DPST | j_lib:NE18-2P | TME | https://www.tme.eu/sk/details/ne182aeesnp6amp/standardne-prepinace/c-k/104-0101-007/
 |  | * |  |  | TME | https://www.tme.eu/sk/details/0853.0551/poistkove-puzdra-pcb/schurter/
 |  | * |  |  | TME | https://www.tme.eu/sk/details/0215.250hxp/poistky-5x20mm-pomale/littelfuse/

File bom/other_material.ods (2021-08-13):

Qty | Type | supplier | link | comment
1 | enclosure | FARNELL | https://uk.farnell.com/multicomp/g756v/case-abs-grey-300x200x75mm/dp/1526697
1 | fan | TME | https://www.tme.eu/en/details/ee50101s1-999-a/dc12v-fans/sunon/ee50101s1-1000u-999/
1 | IEC 60320 socket | TME | https://www.tme.eu/en/details/fw415-0/iec-60320-connectors/
1 | KTY81-210 | TME | https://www.tme.eu/en/details/kty81-210/temperature-transducers/nxp/kty81-210-112/
1 | fan grill | TME | https://www.tme.eu/en/details/fg-05a-bk/guards/tqsolution/
5 | 4mm banana sockets | TME | https://www.tme.eu/en/katalog/?search=seb2610&s_field=1000011&s_order=desc
1 | grounding socket | TME | https://www.tme.eu/en/details/bc-115/4mm-banana-sockets/sci/
3 | KK3960 receptacle | TME | https://www.tme.eu/en/details/a3960h-02p-1/raster-signal-connectors-3-96mm/joint-tech/
4 | KK3960 receptacle | TME | https://www.tme.eu/en/details/a3960h-03p-1/raster-signal-connectors-3-96mm/joint-tech/
3 | KK3960 receptacle | TME | https://www.tme.eu/en/details/a3960h-05p-1/raster-signal-connectors-3-96mm/joint-tech/
2 | KK3960 receptacle | TME | https://www.tme.eu/en/details/a3960h-06p-1/raster-signal-connectors-3-96mm/joint-tech/
1 | transformer | DIY |  | see file transformer
1 | push rod | DIY |  | see folder /mechanical
X | nuts, bolts, etc |  |  | TODO
X | wires |  |  | TODO

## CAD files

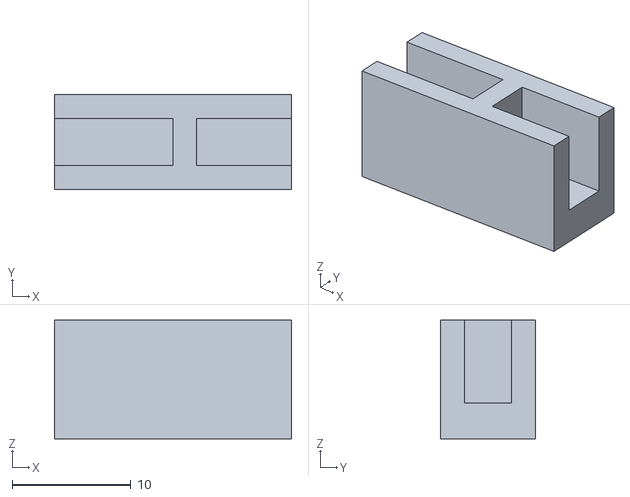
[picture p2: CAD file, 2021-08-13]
mechanical/push_rod_2.stl
20.0 x 8.00 x 10.0

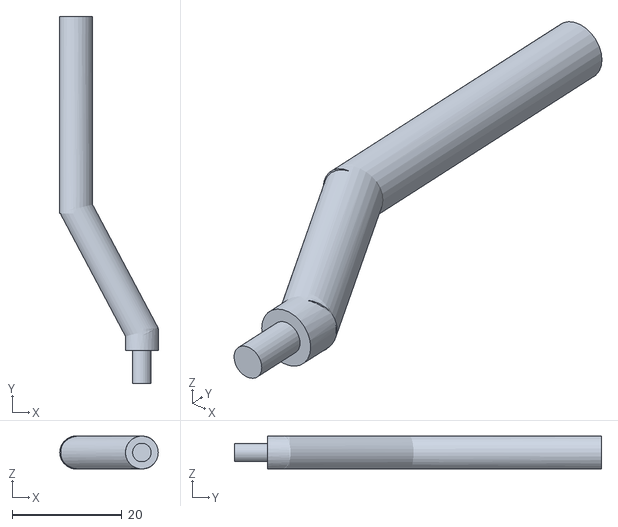
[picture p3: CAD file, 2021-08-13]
mechanical/push_rod_1.stl
18.0 x 67.0 x 6.00

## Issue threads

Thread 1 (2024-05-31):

FIMV and  external voltage source

64-32-16, 2024-05-31:
Hello Jaromir,

there is a problem with the crossover in the current circuit. In FIMV mode and an external voltage source, the current goes to max.

I've already tried to find a solution. Unfortunately, my solutions do not have good control properties.

Can you take a look at this problem?

Thank you very much

RikVervenne, 2024-05-31:
As I understatement your explanation thuis is probably noten issue. In FIMV the voltage compliabce limits the allowable output voltage of the SMU. When an external voltage is applied in this mode smu compensates this by outputting the voltage necessary to compensate this such Thatcher the FI is reached. However, if the needed compensatie exeeds the compliance, regulation is impossible.

64-32-16, 2024-06-01:
Yes I agree with you. I'll put it differently.
Is there perhaps a protective circuit if Limit < Uex, otherwise the measuring resistors will be grilled.
Possible solutions:
* Increase limit automatically?
* current protection for each range?
* automatic cut off?

Thank you for your feedback

RikVervenne, 2024-06-01:
Autoranging is not -yet- implemented by Jaromir. current protection may be practically impossible I guess. Cutoff might be possible.
I wonder how this works on a Keithley or something...
I suppose Jaromir has more important things on his mind for the moment....

jaromir-sukuba, 2024-06-01:
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

Hello,
I may need more details about it.
Did you find the problem in simulation or real hardware?
Post your simulation file or write down the procedure to reproduce your findings, please.

64-32-16, 2024-06-02:
Currently I only use a simulation.
 problem description:
With an external voltage source in FIMV mode and Limit < Uex, the current increases to max. I understand this problem, but a protective circuit makes sense here.
 * Raise limit automatically.
 *  * automatic switch off.
  I don't own a Keithley. How is this problem solved with the Keithley?
Thanks for your support.
 Andreas Wichmann

64-32-16, 2024-06-02:
Hello jaromir, I would be happy to send you my simulation. Unfortunately I can't post the file in the github comment. I'm not at home at the moment. Here is my email anwichmann@outlook.com, if you need my simulation, write me a quick email. Thank you very much

jaromir-sukuba, 2024-06-02:
I'll request the file my the e-mail and see.

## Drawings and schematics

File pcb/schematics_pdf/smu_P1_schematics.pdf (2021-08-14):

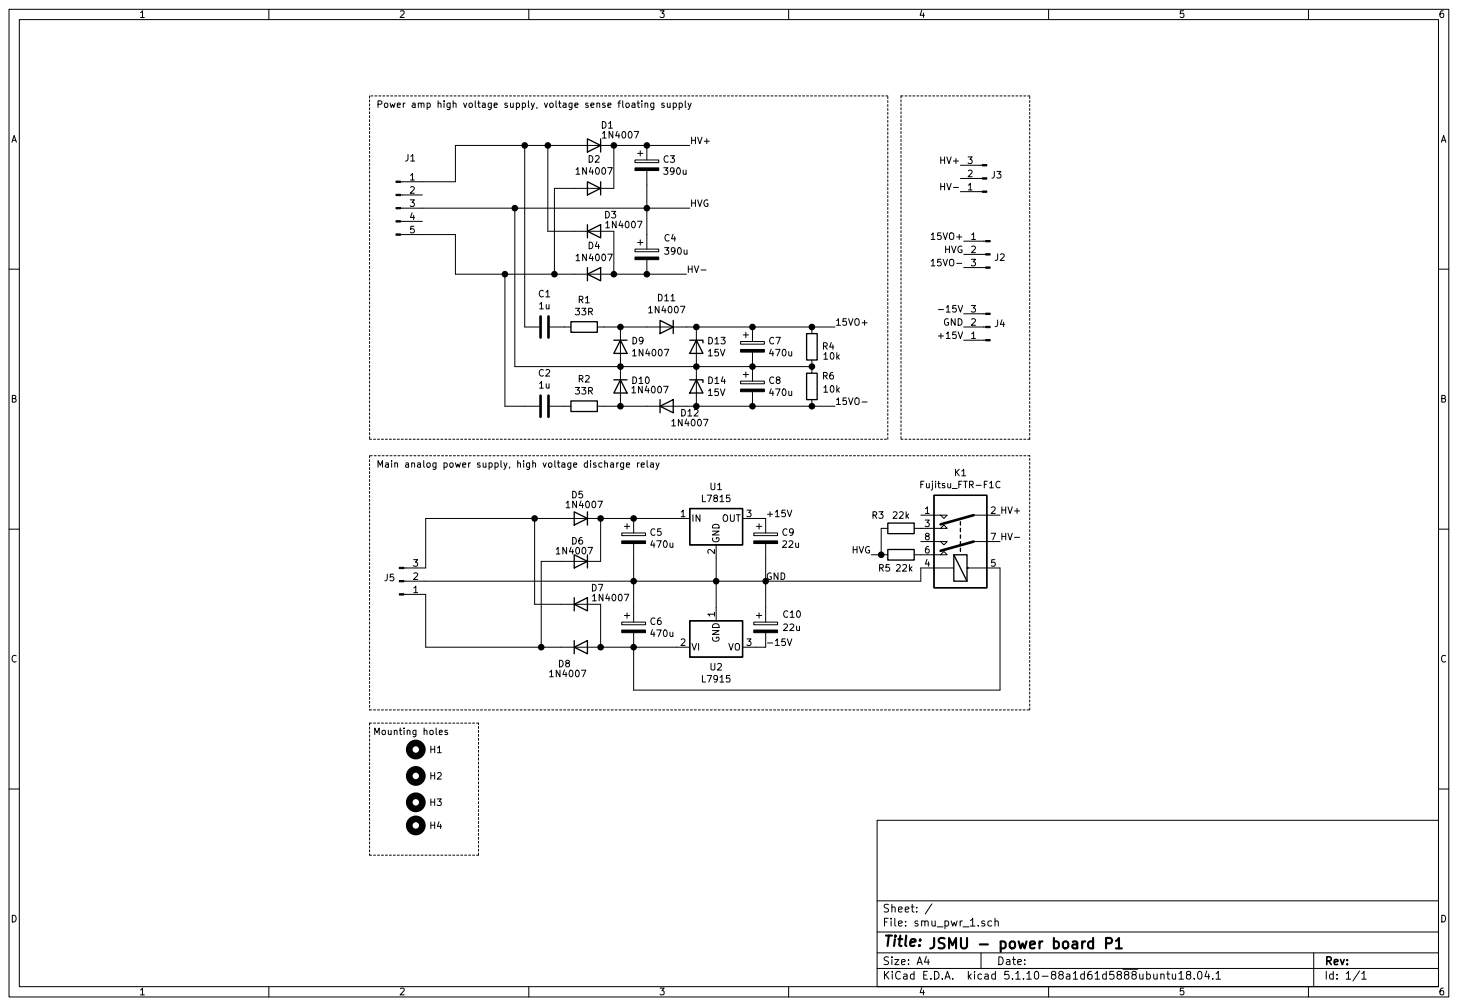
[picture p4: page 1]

Power amp high voltage supply, voltage sense floating supply

Main analog power supply, high voltage discharge relay

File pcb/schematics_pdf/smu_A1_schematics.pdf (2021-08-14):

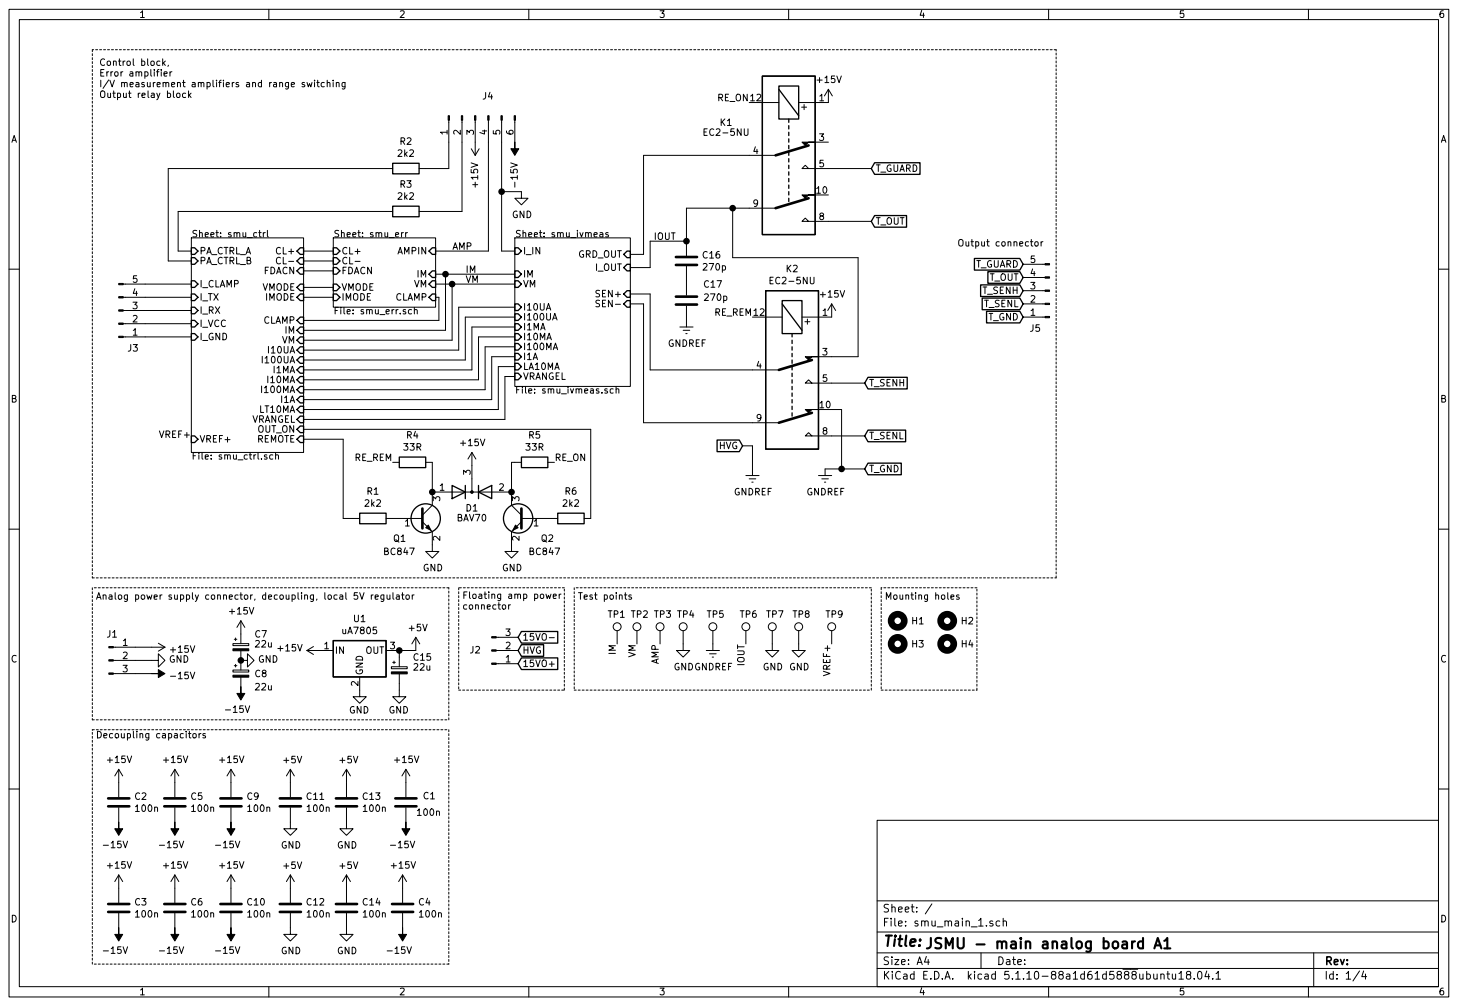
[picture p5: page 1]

Control block, Error amplifier

I/V measurement amplifiers and range switching
Output relay block

SEN+ SEN- VRANGEL Sheet: smu_ctrl File: smu_ctrl.sch
LT10MA CL+ CL- FDACN

Sheet: smu_err File: smu_err.sch CL+ CL- FDACN

Analog power supply connector, decoupling, local 5V regulator

File: smu_main_1.sch Sheet: /
Id: 1/4 Title:
JSMU - main analog board A1

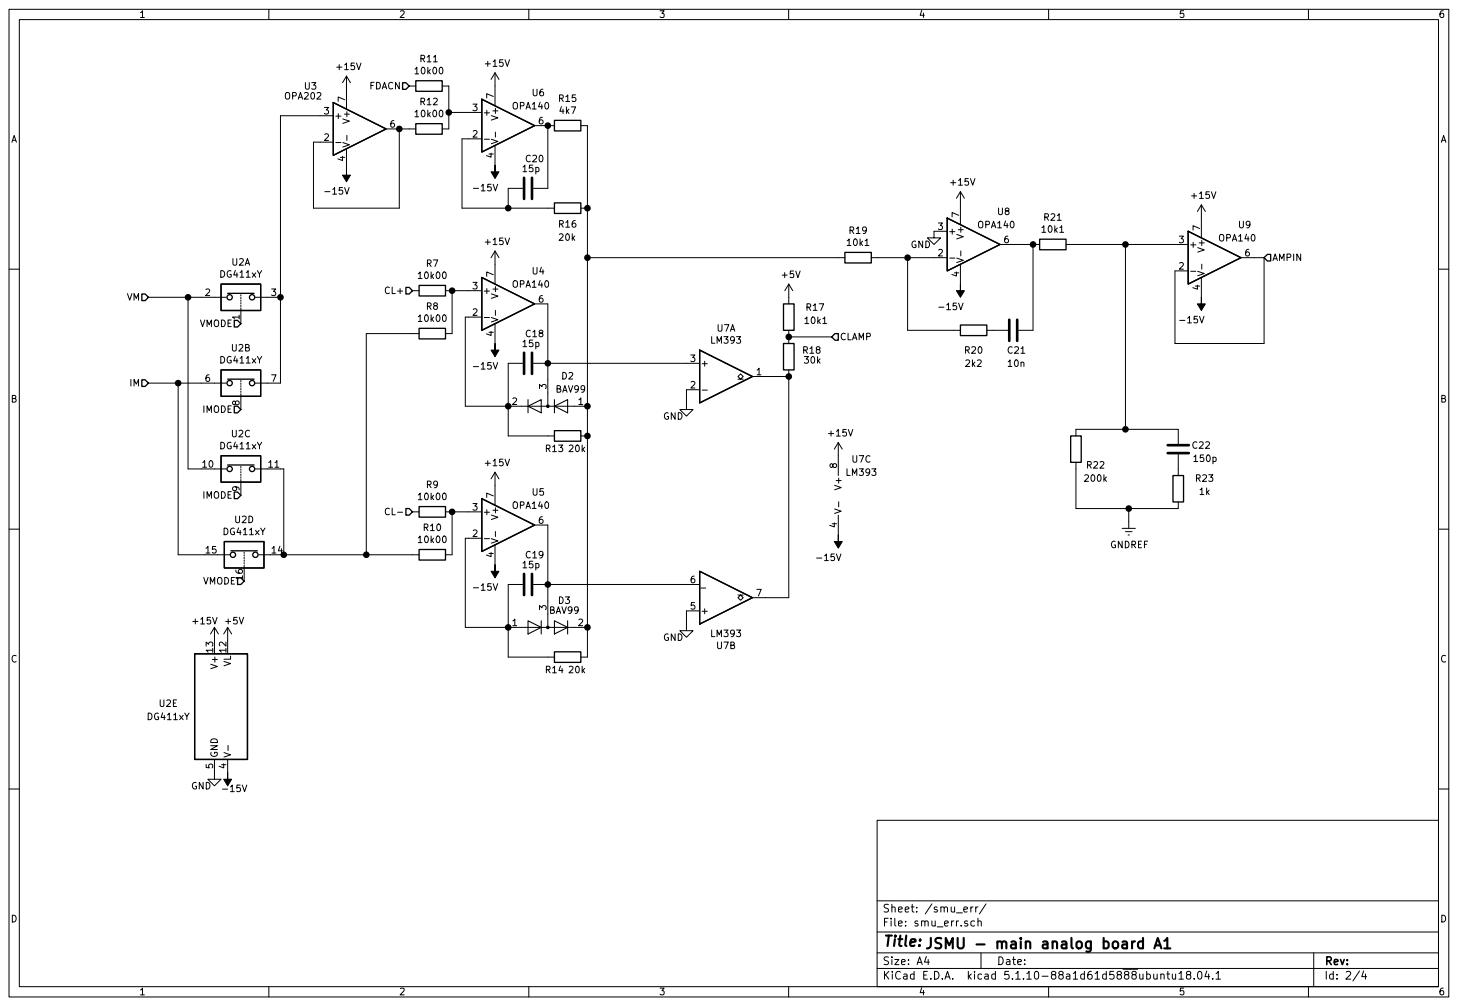
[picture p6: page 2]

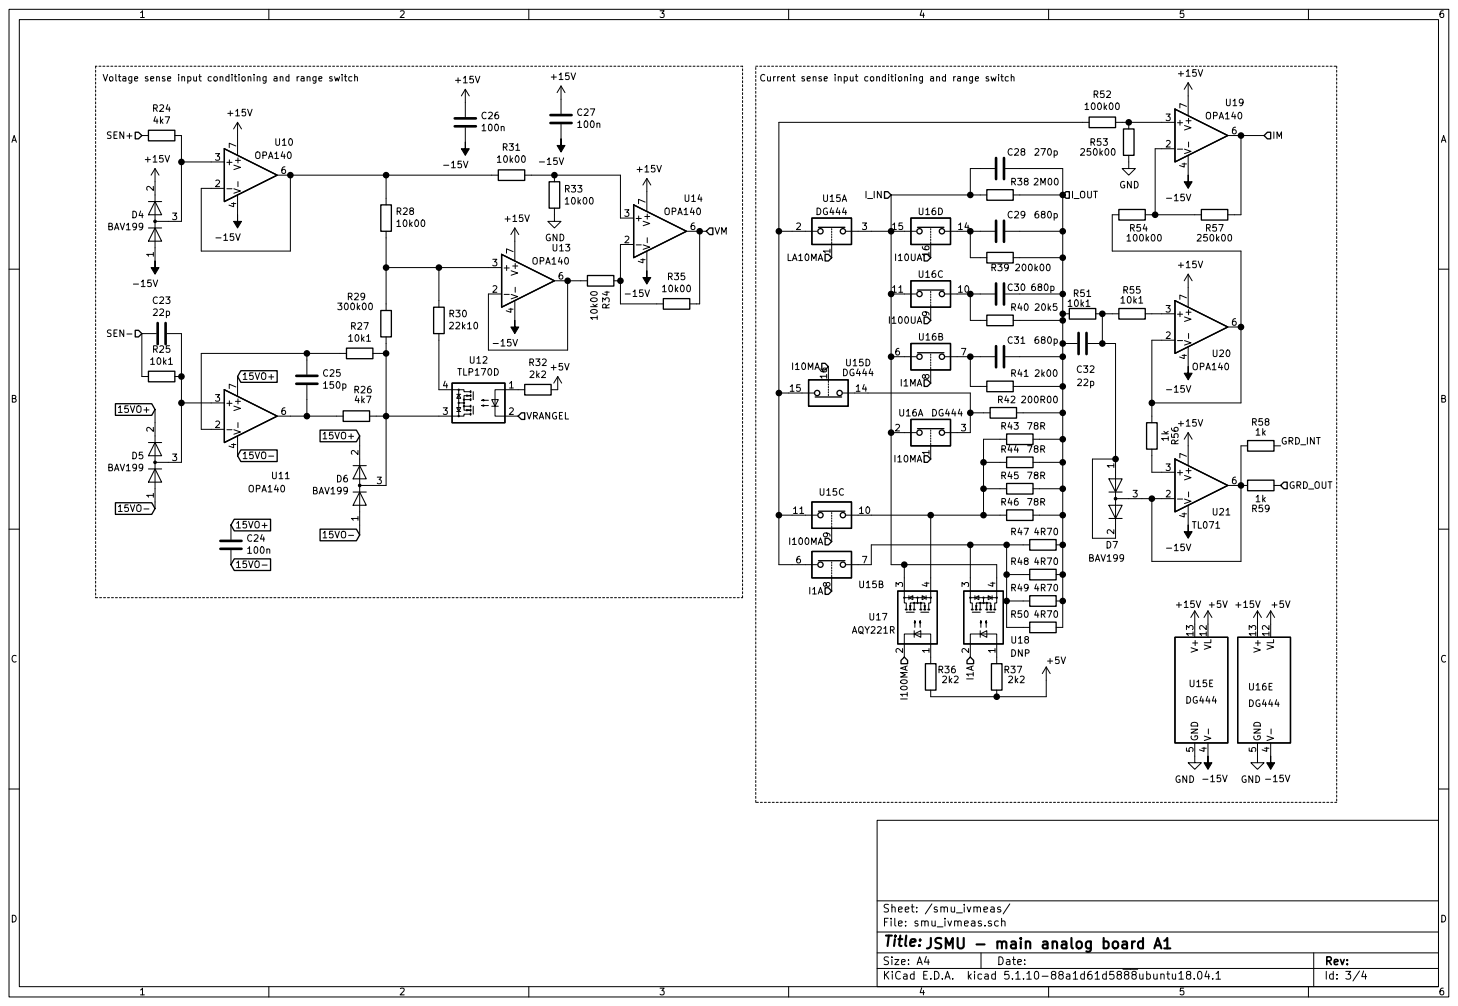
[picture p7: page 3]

Sheet: /smu_ivmeas/
File: smu_ivmeas.sch
Id: 3/4 Title:
JSMU - main analog board A1

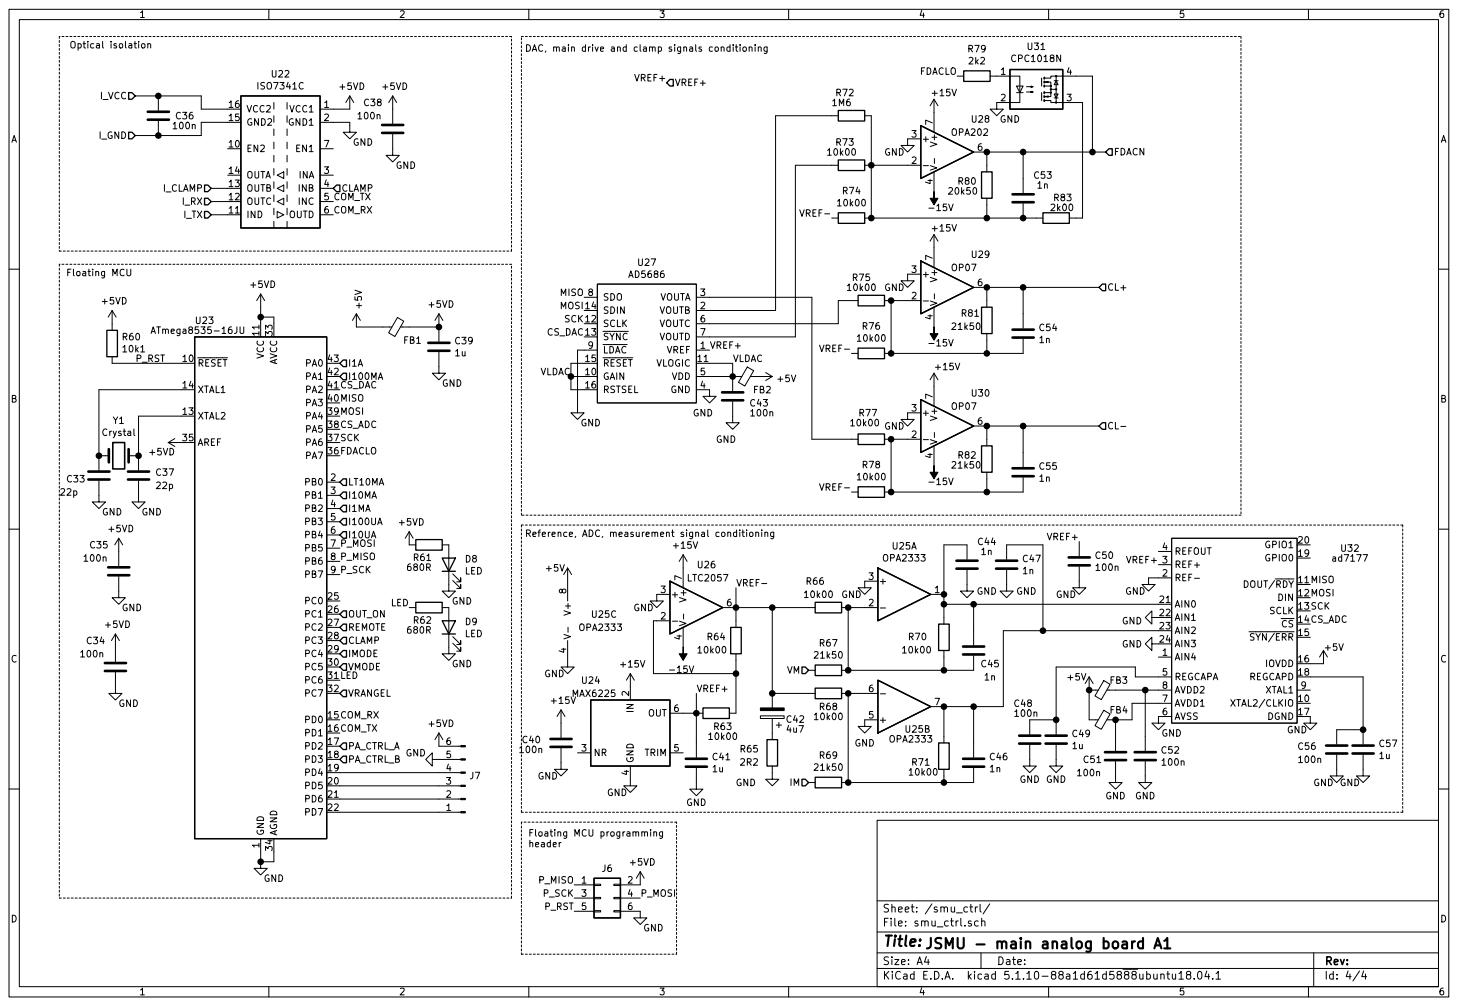
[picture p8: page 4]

DAC, main drive and clamp signals conditioning

1 RESET 10 VCC 11 XTAL2 13 XTAL1 14 PD0 15 PD1 16 PD2 17 PD3 18 PD4 19 PB0 2 PD5 20 PD6 21 PD7 22 PC0 25 PC1 26 PC2 27 PC3 28 PC4 29 PB1 3 PC5 30 PC6 31 PC7 32 AVCC 33 AGND 34 AREF 35 PA7 36 PA6 37 PA5 38 PA4 39 PB2 4 PA3 40 PA2 41 PA1 42 PA0 43 PB3 5 PB4 6 PB5 7 PB6 8 PB7 9 U23 ATmega8535-16JU GND

Reference, ADC, measurement signal conditioning

4 TRIM 5 OUT 6 U24 MAX6225 AIN4 1 XTAL2/CLKIO 10 DOUT/RDY 11 DIN 12 SCLK 13 CS 14 SYN/ERR 15

Floating MCU programming header

File: smu_ctrl.sch
Id: 4/4 Title:
JSMU - main analog board A1

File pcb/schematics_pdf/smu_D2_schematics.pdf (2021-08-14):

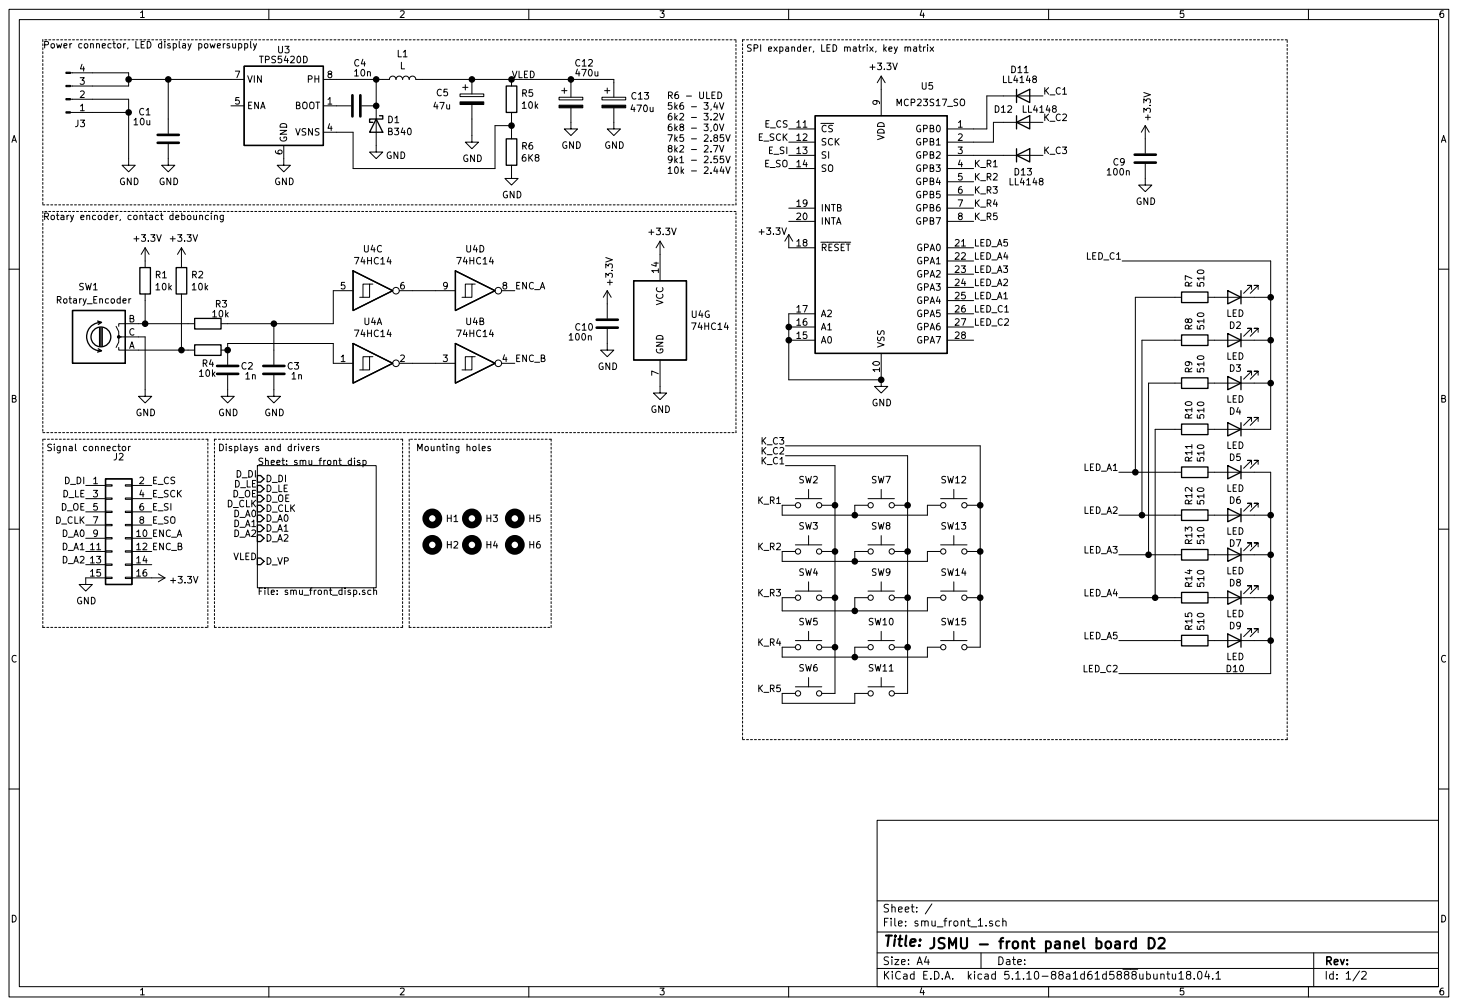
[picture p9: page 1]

SPI expander, LED matrix, key matrix

Rotary encoder, contact debouncing

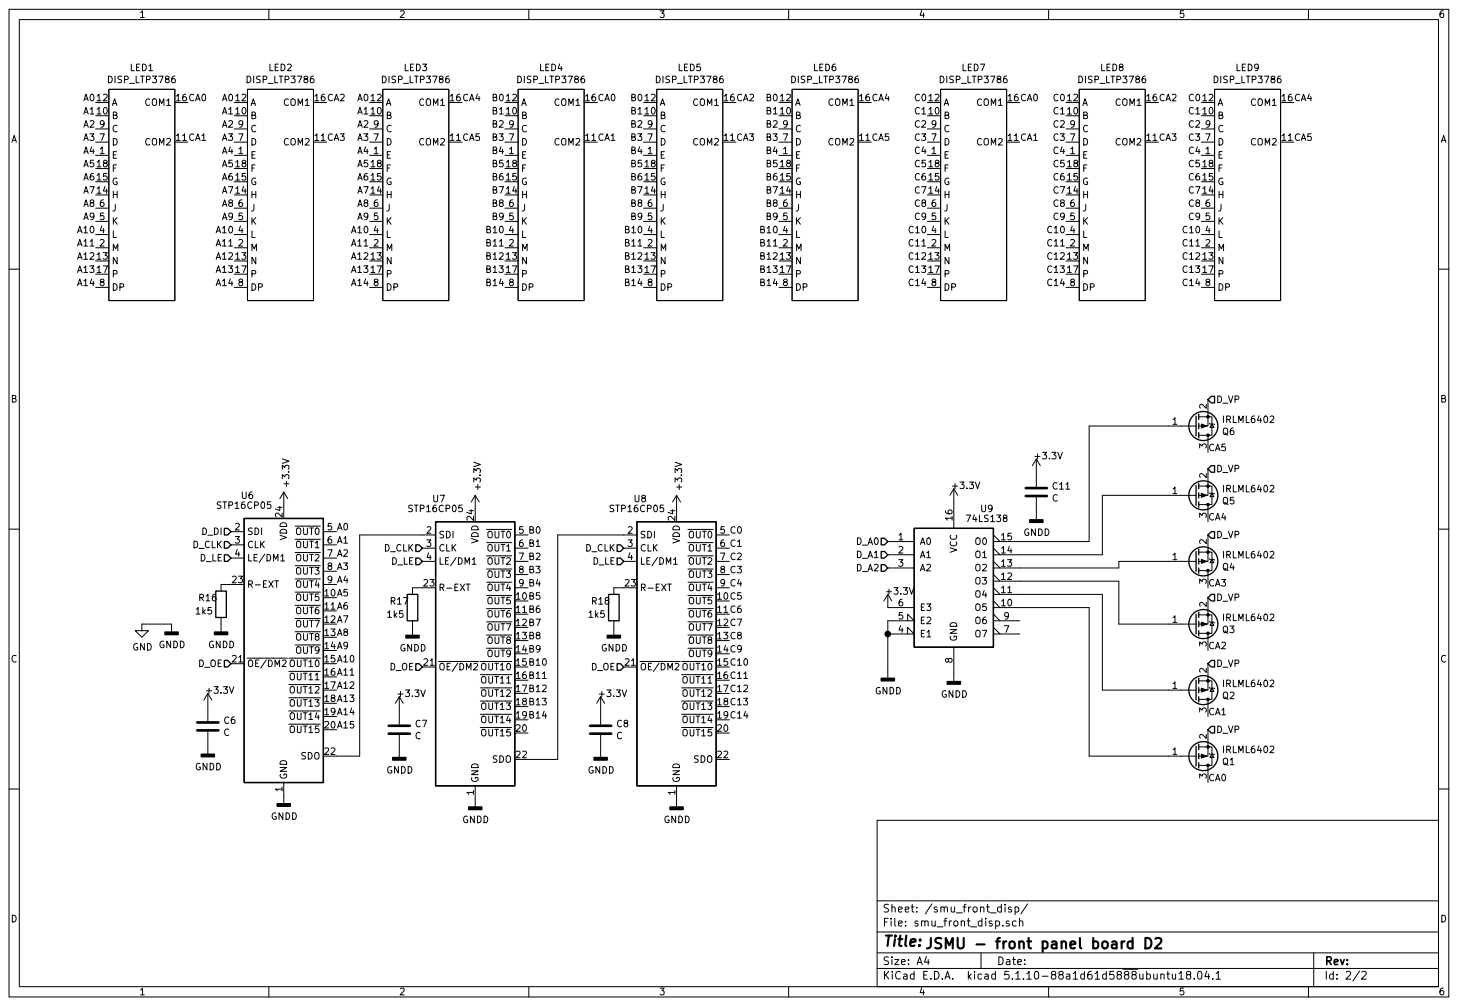
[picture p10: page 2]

1 OUT5 10 OUT6 11 OUT7 12 OUT8 13 OUT9 14 OUT10 15 OUT11 16 OUT12 17 OUT13 18 OUT14 19 SDI 2 OUT15 20 OE/DM2 21 SDO 22 R-EXT 23 VDD 24 CLK 3

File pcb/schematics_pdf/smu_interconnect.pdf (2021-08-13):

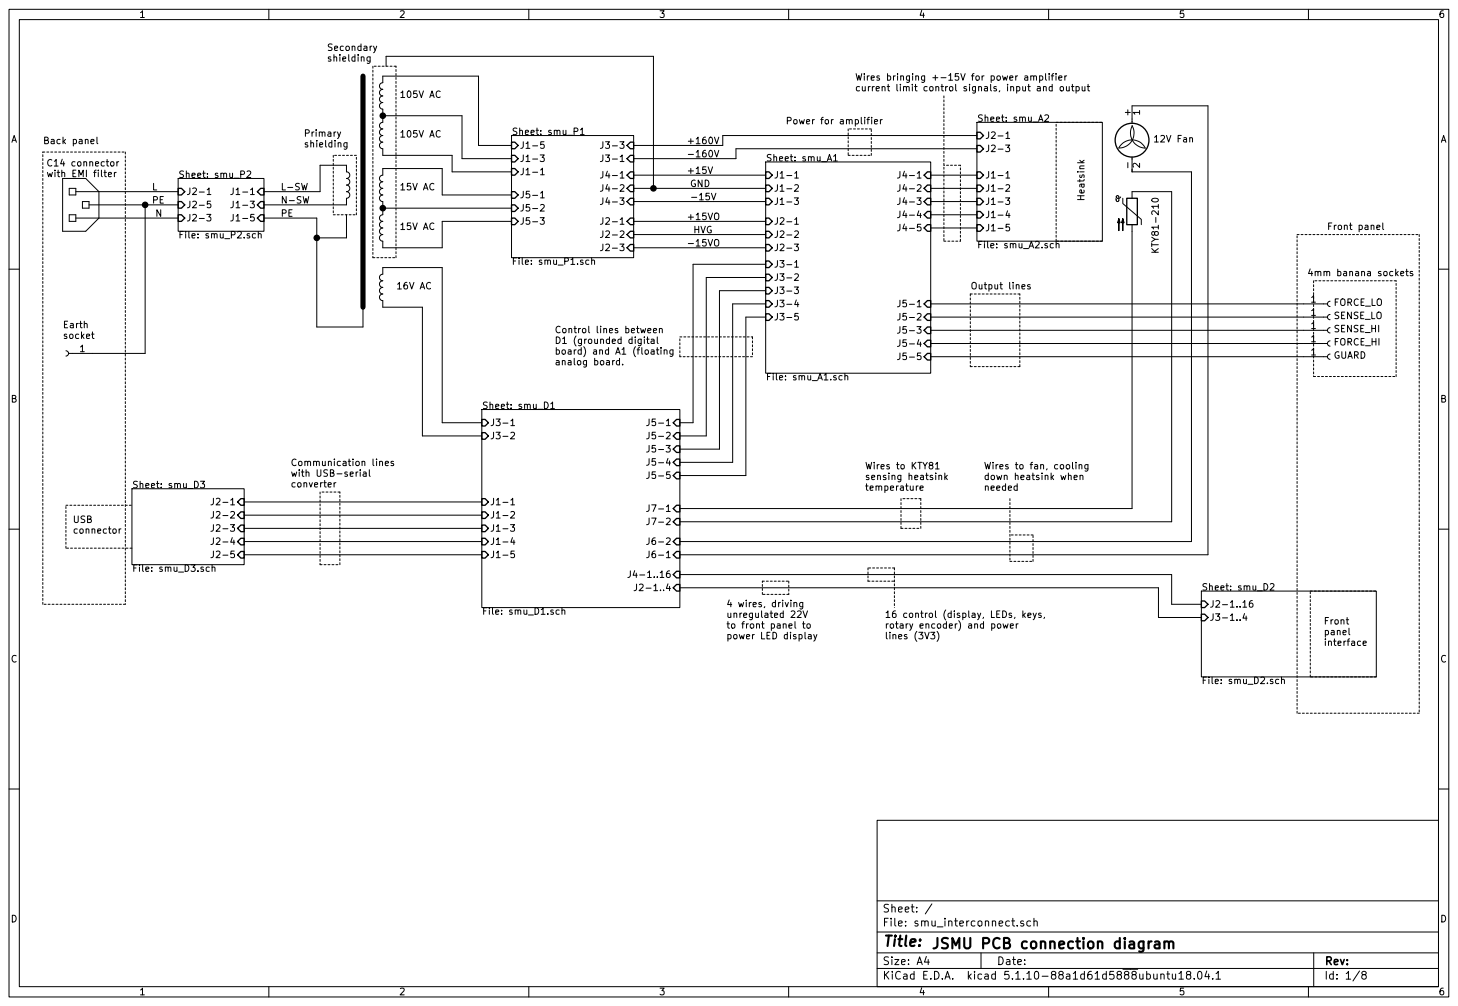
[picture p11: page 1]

current limit control signals, input and output

4mm banana sockets Front panel

Power for amplifier Communication lines with USB-serial converter
Primary
shielding

Wires to fan, cooling
down heatsink when needed

4 wires, driving
unregulated 22V
to front panel to
power LED display

16 control (display, LEDs, keys,
rotary encoder) and power

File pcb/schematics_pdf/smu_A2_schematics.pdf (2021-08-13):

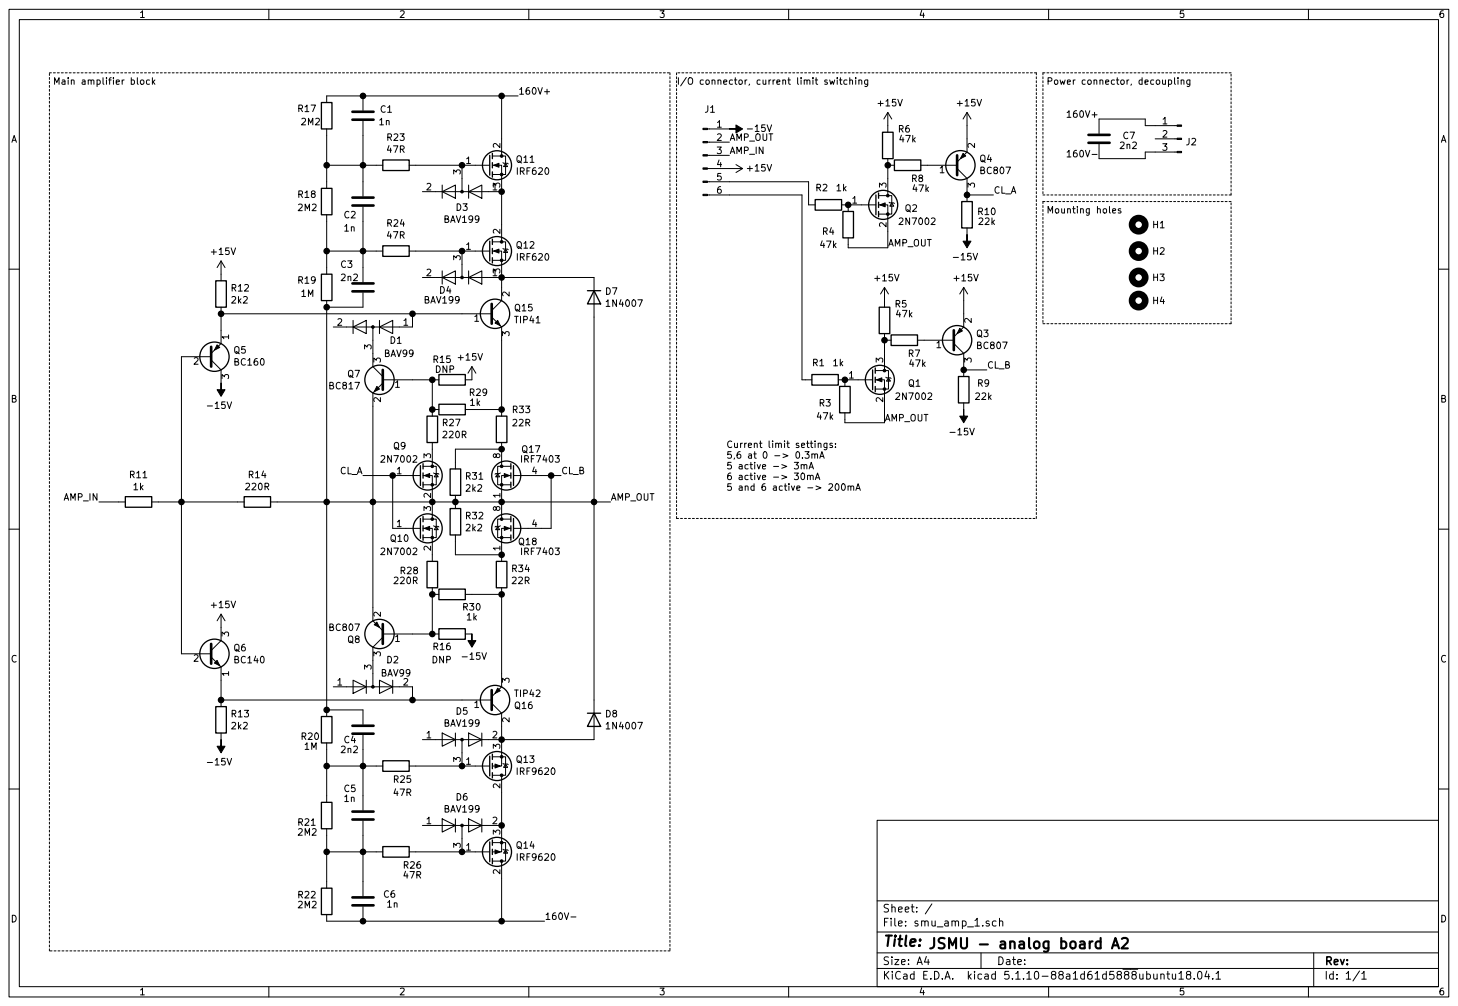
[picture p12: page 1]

Current limit settings: 5,6 at 0 -> 0.3mA

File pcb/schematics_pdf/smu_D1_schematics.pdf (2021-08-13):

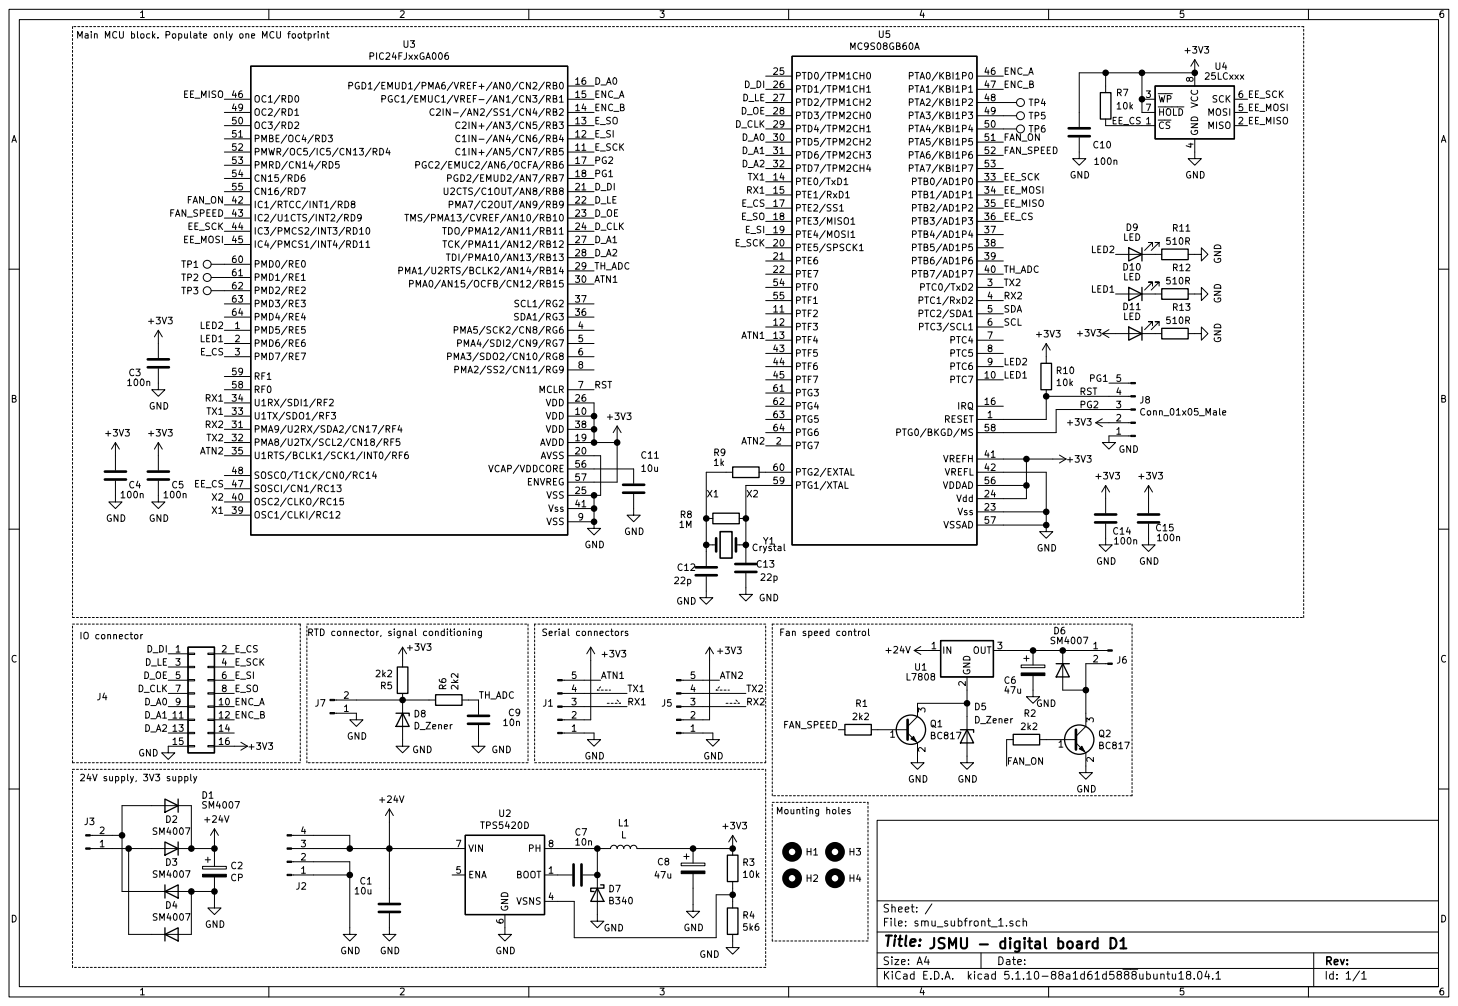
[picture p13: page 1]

Main MCU block. Populate only one MCU footprint

4 MOSI 5 SCK 6 HOLD 7 VCC

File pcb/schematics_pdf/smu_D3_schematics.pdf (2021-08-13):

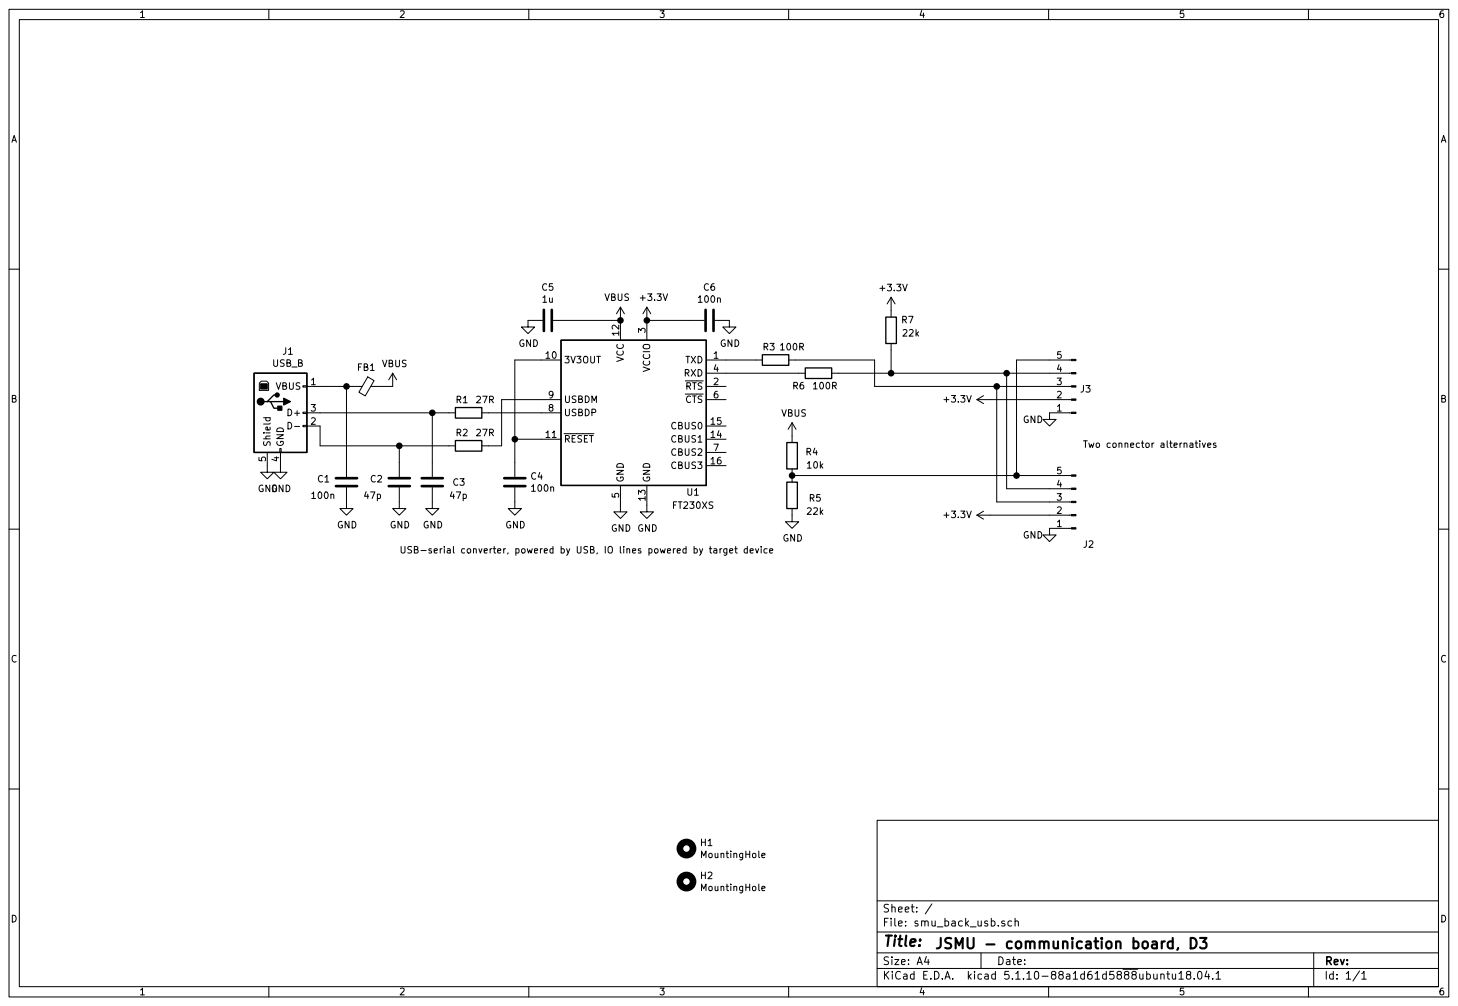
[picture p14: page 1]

File: smu_back_usb.sch Sheet: / GND GND

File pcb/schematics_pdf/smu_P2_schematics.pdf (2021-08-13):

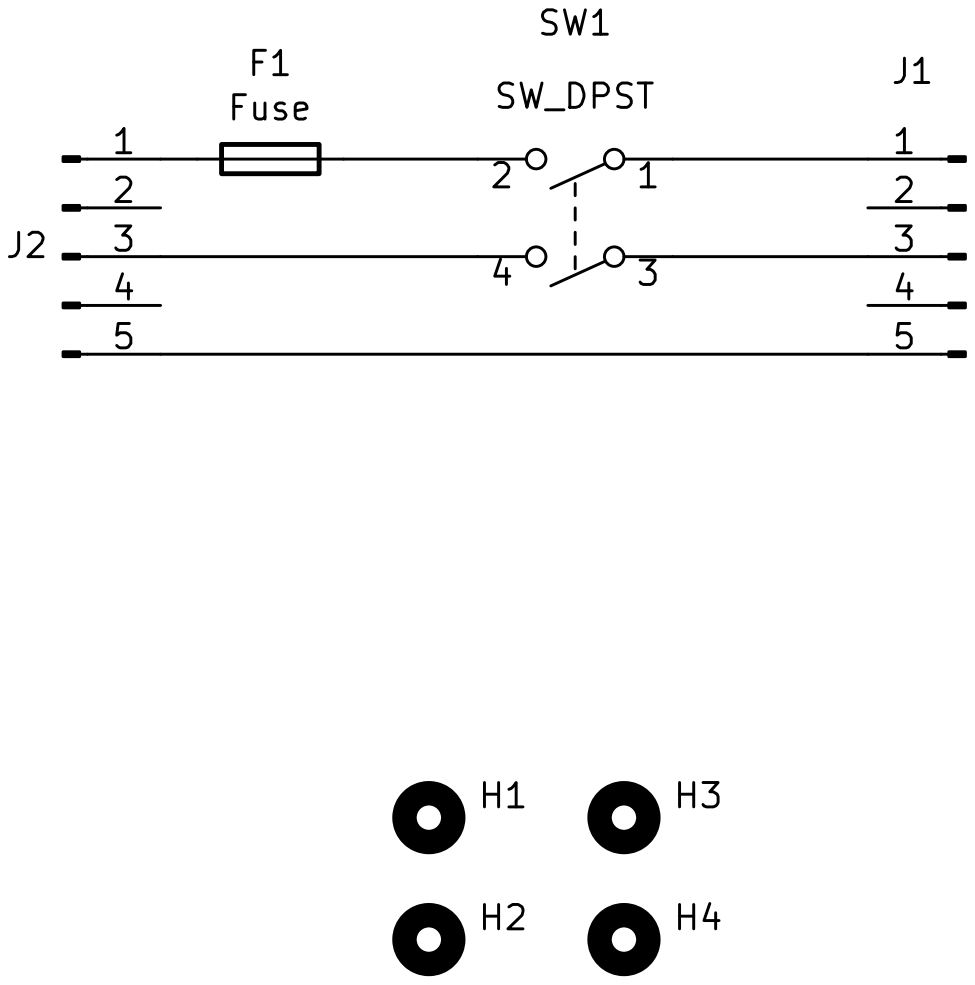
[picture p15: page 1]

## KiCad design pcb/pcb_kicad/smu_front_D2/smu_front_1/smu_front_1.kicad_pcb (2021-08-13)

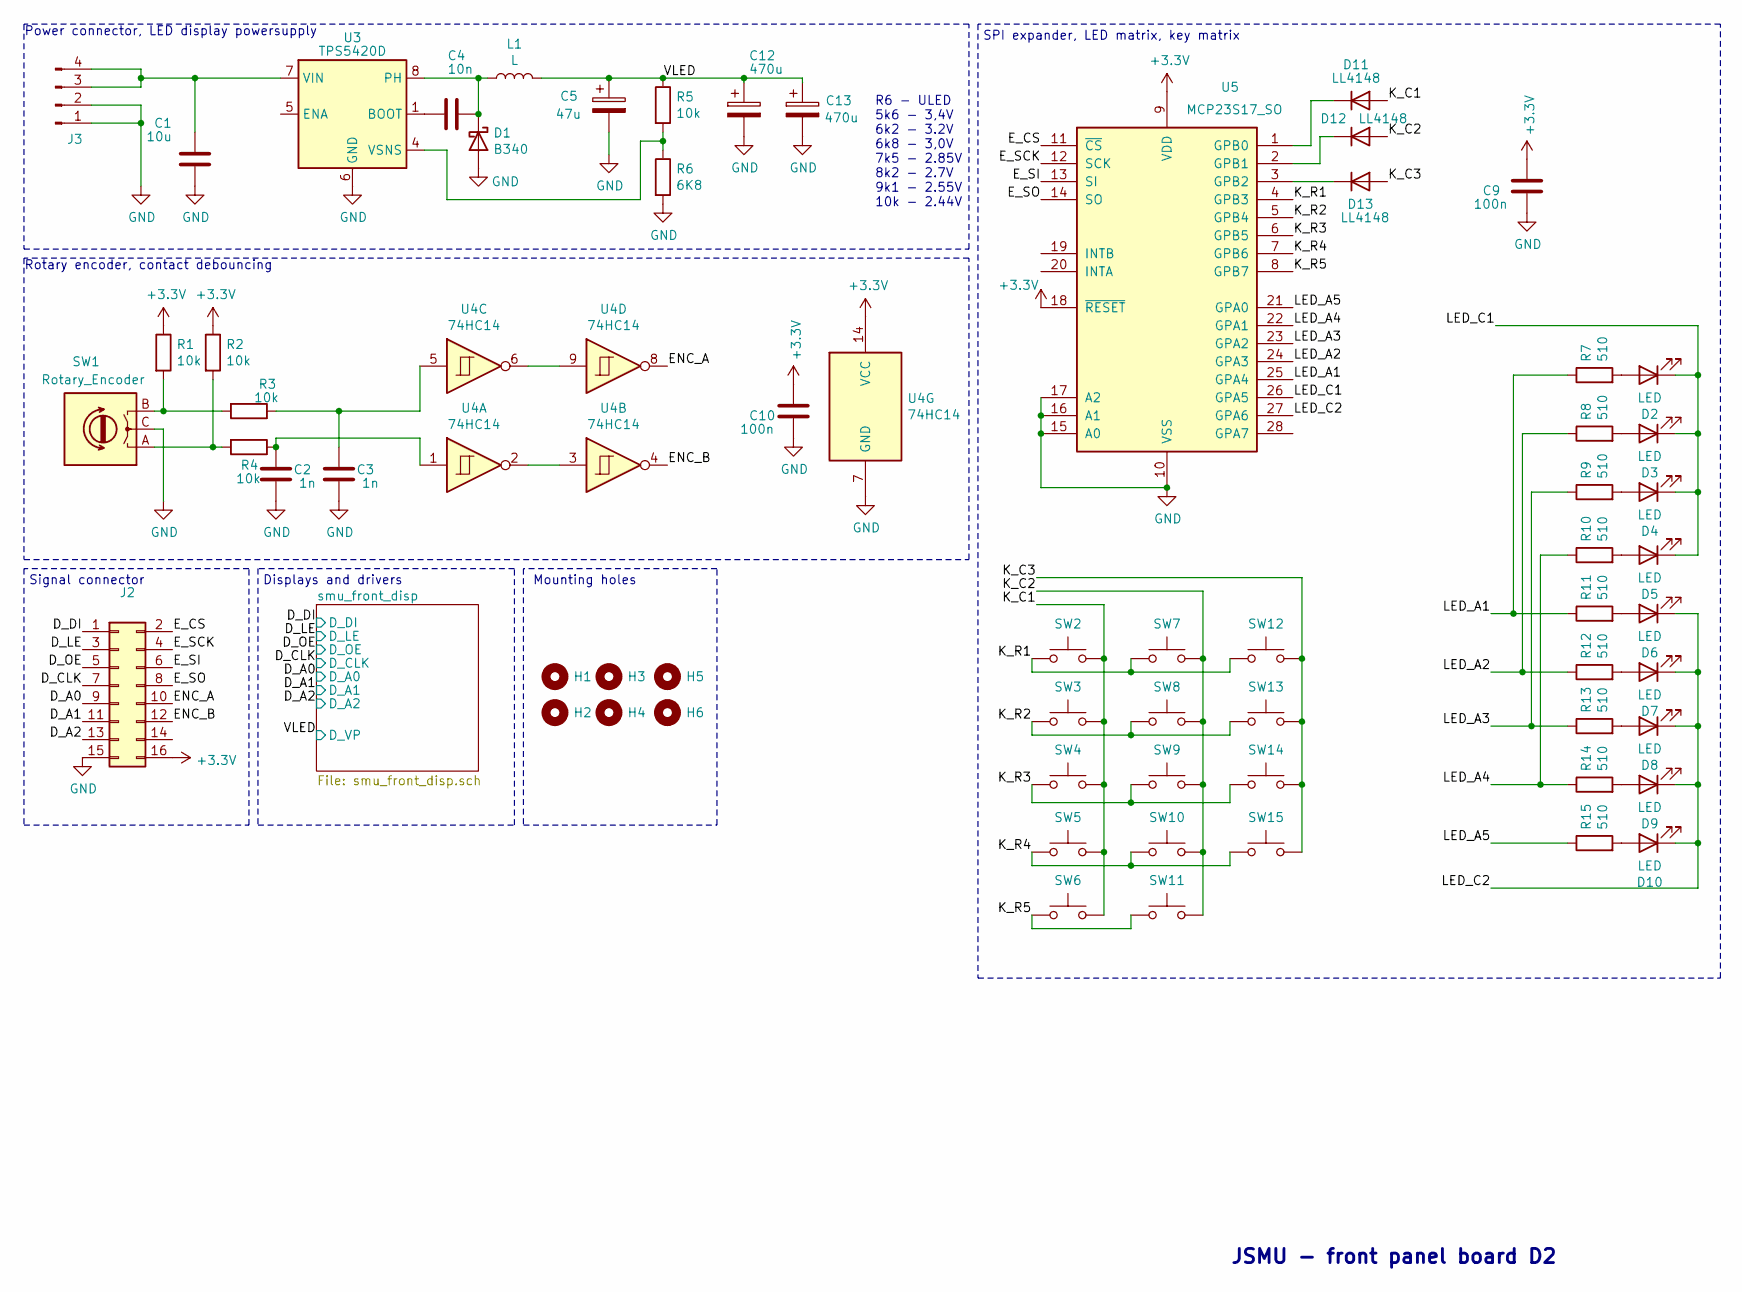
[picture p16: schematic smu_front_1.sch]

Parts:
C1: 10u; C_0805_2012Metric_Pad1.18x1.45mm_HandSolder
C2, C3: 1n; C_0805_2012Metric_Pad1.18x1.45mm_HandSolder
C4: 10n; C_0805_2012Metric_Pad1.18x1.45mm_HandSolder
C5: 47u; CP_EIA-6032-28_Kemet-C_Pad2.25x2.35mm_HandSolder
C9, C10: 100n; C_0805_2012Metric_Pad1.18x1.45mm_HandSolder
C12, C13: 470u; CP_Radial_D6.3mm_P2.50mm
D1: B340; D_SMB_Handsoldering
D2, D3, D4, D5, D6, D7, D8, D9, D10: LED; LED_D3.0mm
D11, D12, D13: LL4148; D_MiniMELF
H1, H2, H3, H4, H5, H6: MountingHole; MountingHole_3.2mm_M3_Pad
J2: Conn_02x08_Odd_Even; PinHeader_2x08_P2.54mm_Vertical
J3: Conn_01x04_Male; PinHeader_1x04_P2.54mm_Vertical
L1: L; L_Bourns_SRP7028A_7.3x6.6mm
R1, R2, R3, R4, R5: 10k; R_0805_2012Metric_Pad1.20x1.40mm_HandSolder
R6: 6K8; R_0805_2012Metric_Pad1.20x1.40mm_HandSolder
R7, R8, R9, R10, R11, R12, R13, R14, R15: 510; R_0805_2012Metric_Pad1.20x1.40mm_HandSolder
SW1: Rotary_Encoder; RotaryEncoder_Alps_EC12E_Vertical_H20mm_CircularMountingHol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
SW2, SW3, SW4, SW5, SW6, SW7, SW8, SW9, SW10, SW11, SW12, SW13, SW14, SW15: SW_Push; MQ_6450
U3: TPS5420D; SOIC-8_3.9x4.9mm_P1.27mm
U4: 74HC14; SOIC-14_3.9x8.7mm_P1.27mm
U5: MCP23S17_SO; SOIC-28W_7.5x17.9mm_P1.27mm

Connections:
+3V3: C9.1, C10.1, J2.16, R1.1, R2.1, U4.14 (VCC), U5.9 (VDD), U5.18 (~RESET~); also elsewhere on the board
/D_A0: J2.9; also elsewhere on the board
/D_A1: J2.11; also elsewhere on the board
/D_A2: J2.13; also elsewhere on the board
/D_CLK: J2.7; also elsewhere on the board
/D_DI: J2.1; also elsewhere on the board
/D_LE: J2.3; also elsewhere on the board
/D_OE: J2.5; also elsewhere on the board
/ENC_A: J2.10, U4.8
/ENC_B: J2.12, U4.4
/E_CS: J2.2, U5.11 (~CS~)
/E_SCK: J2.4, U5.12 (SCK)
/E_SI: J2.6, U5.13 (SI)
/E_SO: J2.8, U5.14 (SO)
/K_C1: D11.2 (A), SW2.2, SW3.2, SW4.2, SW5.2, SW6.2
/K_C2: D12.2 (A), SW7.2, SW8.2, SW9.2, SW10.2, SW11.2
/K_C3: D13.2 (A), SW12.2, SW13.2, SW14.2, SW15.2
/K_R1: SW2.1, SW7.1, SW12.1, U5.4 (GPB3)
/K_R2: SW3.1, SW8.1, SW13.1, U5.5 (GPB4)
/K_R3: SW4.1, SW9.1, SW14.1, U5.6 (GPB5)
/K_R4: SW5.1, SW10.1, SW15.1, U5.7 (GPB6)
/K_R5: SW6.1, SW11.1, U5.8 (GPB7)
/LED_A1: R7.1, R11.1, U5.25 (GPA4)
/LED_A2: R8.1, R12.1, U5.24 (GPA3)
/LED_A3: R9.1, R13.1, U5.23 (GPA2)
/LED_A4: R10.1, R14.1, U5.22 (GPA1)
/LED_A5: R15.1, U5.21 (GPA0)
/LED_C1: D2.1 (K), D3.1 (K), D4.1 (K), D5.1 (K), U5.26 (GPA5)
/LED_C2: D6.1 (K), D7.1 (K), D8.1 (K), D9.1 (K), D10.1 (K), U5.27 (GPA6)
/VLED: C5.1, C12.1, C13.1, L1.2, R5.1; also elsewhere on the board
GND: C1.1, C2.1, C3.1, C5.2, C9.2, C10.2, C12.2, C13.2, D1.2 (A), J2.15, J3.1, J3.2, R6.2, SW1.C, U3.6 (GND), U4.7 (GND), U5.10 (VSS), U5.15 (A0), U5.16 (A1), U5.17 (A2); also elsewhere on the board
unnamed: C1.2, J3.3, J3.4, U3.7 (VIN)
unnamed: C2.2, R4.1, U4.1
unnamed: C3.2, R3.1, U4.5
unnamed: C4.1, D1.1 (K), L1.1, U3.8 (PH)
unnamed: C4.2, U3.1 (BOOT)
unnamed: D2.2 (A), R7.2
unnamed: D3.2 (A), R8.2
unnamed: D4.2 (A), R9.2
unnamed: D5.2 (A), R10.2
unnamed: D6.2 (A), R11.2
unnamed: D7.2 (A), R12.2
unnamed: D8.2 (A), R13.2
unnamed: D9.2 (A), R14.2
unnamed: D10.2 (A), R15.2
unnamed: D11.1 (K), U5.1 (GPB0)
unnamed: D12.1 (K), U5.2 (GPB1)
unnamed: D13.1 (K), U5.3 (GPB2)
unnamed: R1.2, R3.2, SW1.B
unnamed: R2.2, R4.2, SW1.A
unnamed: R5.2, R6.1, U3.4 (VSNS)
unnamed: U4.2, U4.3
unnamed: U4.6, U4.9

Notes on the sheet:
R6 - ULED 5k6 - 3,4V 6k2 - 3.2V 6k8 - 3,0V 7k5 - 2.85V 8k2 - 2.7V 9k1 - 2.55V 10k - 2.44V
Power connector, LED display powersupply
Rotary encoder, contact debouncing
Signal connector
Displays and drivers
Mounting holes
SPI expander, LED matrix, key matrix
JSMU - front panel board D2

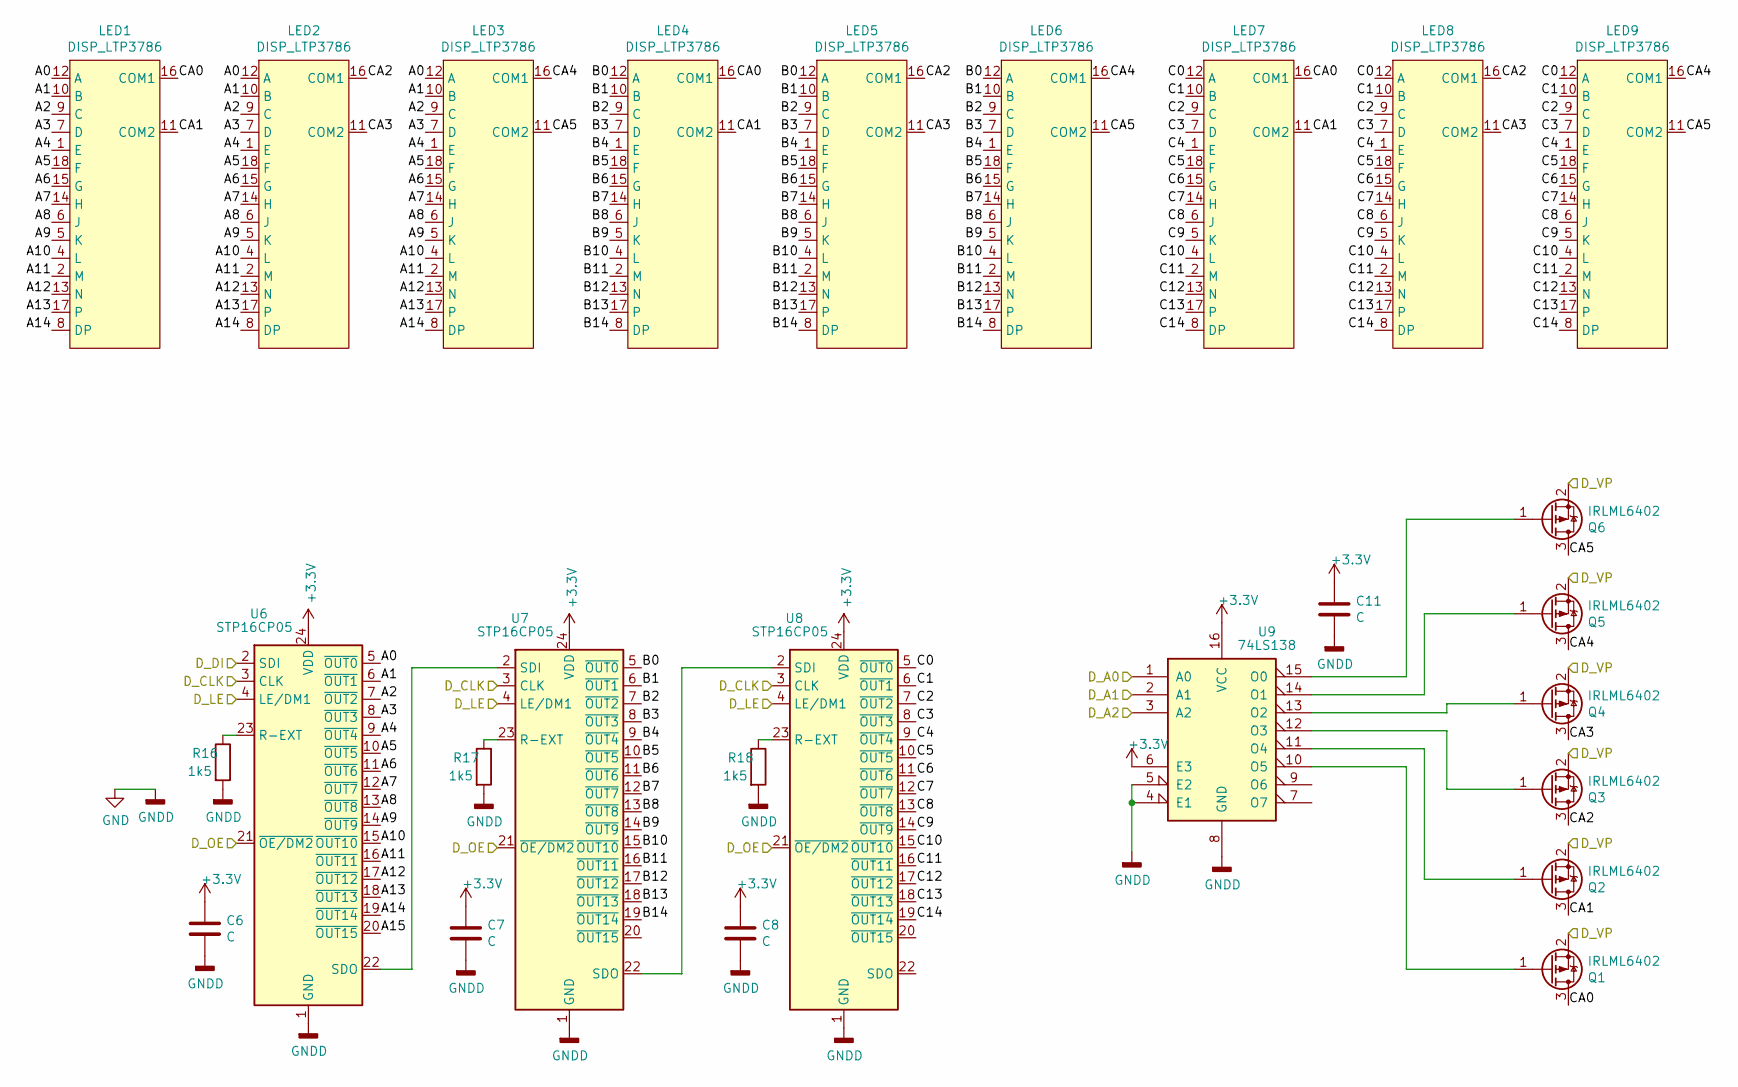
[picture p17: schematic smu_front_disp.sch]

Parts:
C6, C7, C8, C11: C; C_0805_2012Metric_Pad1.18x1.45mm_HandSolder
LED1, LED2, LED3, LED4, LED5, LED6, LED7, LED8, LED9: DISP_LTP3786; DISP_LED_18
Q1, Q2, Q3, Q4, Q5, Q6: IRLML6402; SOT-23
R16, R17, R18: 1k5; R_0805_2012Metric_Pad1.20x1.40mm_HandSolder
U6, U7, U8: STP16CP05; SSOP-24_3.9x8.7mm_P0.635mm
U9: 74LS138; SO-16_3.9x9.9mm_P1.27mm

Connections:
+3V3: C6.1, C7.1, C8.1, C11.1, U6.24 (VDD), U7.24 (VDD), U8.24 (VDD), U9.6 (E3), U9.16 (VCC); also elsewhere on the board
/D_A0: U9.1 (A0); also elsewhere on the board
/D_A1: U9.2 (A1); also elsewhere on the board
/D_A2: U9.3 (A2); also elsewhere on the board
/D_CLK: U6.3 (CLK), U7.3 (CLK), U8.3 (CLK); also elsewhere on the board
/D_DI: U6.2 (SDI); also elsewhere on the board
/D_LE: U6.4 (LE/DM1), U7.4 (LE/DM1), U8.4 (LE/DM1); also elsewhere on the board
/D_OE: U6.21 (~OE/DM2), U7.21 (~OE/DM2), U8.21 (~OE/DM2); also elsewhere on the board
/VLED: Q1.2 (S), Q2.2 (S), Q3.2 (S), Q4.2 (S), Q5.2 (S), Q6.2 (S); also elsewhere on the board
/smu_front_disp/A0: LED1.12 (A), LED2.12 (A), LED3.12 (A), U6.5 (~OUT0)
/smu_front_disp/A1: LED1.10 (B), LED2.10 (B), LED3.10 (B), U6.6 (~OUT1)
/smu_front_disp/A2: LED1.9 (C), LED2.9 (C), LED3.9 (C), U6.7 (~OUT2)
/smu_front_disp/A3: LED1.7 (D), LED2.7 (D), LED3.7 (D), U6.8 (~OUT3)
/smu_front_disp/A4: LED1.1 (E), LED2.1 (E), LED3.1 (E), U6.9 (~OUT4)
/smu_front_disp/A5: LED1.18 (F), LED2.18 (F), LED3.18 (F), U6.10 (~OUT5)
/smu_front_disp/A6: LED1.15 (G), LED2.15 (G), LED3.15 (G), U6.11 (~OUT6)
/smu_front_disp/A7: LED1.14 (H), LED2.14 (H), LED3.14 (H), U6.12 (~OUT7)
/smu_front_disp/A8: LED1.6 (J), LED2.6 (J), LED3.6 (J), U6.13 (~OUT8)
/smu_front_disp/A9: LED1.5 (K), LED2.5 (K), LED3.5 (K), U6.14 (~OUT9)
/smu_front_disp/A10: LED1.4 (L), LED2.4 (L), LED3.4 (L), U6.15 (~OUT10)
/smu_front_disp/A11: LED1.2 (M), LED2.2 (M), LED3.2 (M), U6.16 (~OUT11)
/smu_front_disp/A12: LED1.13 (N), LED2.13 (N), LED3.13 (N), U6.17 (~OUT12)
/smu_front_disp/A13: LED1.17, LED2.17, LED3.17, U6.18 (~OUT13)
/smu_front_disp/A14: LED1.8 (DP), LED2.8 (DP), LED3.8 (DP), U6.19 (~OUT14)
/smu_front_disp/A15: U6.20 (~OUT15)
/smu_front_disp/B0: LED4.12 (A), LED5.12 (A), LED6.12 (A), U7.5 (~OUT0)
/smu_front_disp/B1: LED4.10 (B), LED5.10 (B), LED6.10 (B), U7.6 (~OUT1)
/smu_front_disp/B2: LED4.9 (C), LED5.9 (C), LED6.9 (C), U7.7 (~OUT2)
/smu_front_disp/B3: LED4.7 (D), LED5.7 (D), LED6.7 (D), U7.8 (~OUT3)
/smu_front_disp/B4: LED4.1 (E), LED5.1 (E), LED6.1 (E), U7.9 (~OUT4)
/smu_front_disp/B5: LED4.18 (F), LED5.18 (F), LED6.18 (F), U7.10 (~OUT5)
/smu_front_disp/B6: LED4.15 (G), LED5.15 (G), LED6.15 (G), U7.11 (~OUT6)
/smu_front_disp/B7: LED4.14 (H), LED5.14 (H), LED6.14 (H), U7.12 (~OUT7)
/smu_front_disp/B8: LED4.6 (J), LED5.6 (J), LED6.6 (J), U7.13 (~OUT8)
/smu_front_disp/B9: LED4.5 (K), LED5.5 (K), LED6.5 (K), U7.14 (~OUT9)
/smu_front_disp/B10: LED4.4 (L), LED5.4 (L), LED6.4 (L), U7.15 (~OUT10)
/smu_front_disp/B11: LED4.2 (M), LED5.2 (M), LED6.2 (M), U7.16 (~OUT11)
/smu_front_disp/B12: LED4.13 (N), LED5.13 (N), LED6.13 (N), U7.17 (~OUT12)
/smu_front_disp/B13: LED4.17, LED5.17, LED6.17, U7.18 (~OUT13)
/smu_front_disp/B14: LED4.8 (DP), LED5.8 (DP), LED6.8 (DP), U7.19 (~OUT14)
/smu_front_disp/C0: LED7.12 (A), LED8.12 (A), LED9.12 (A), U8.5 (~OUT0)
/smu_front_disp/C1: LED7.10 (B), LED8.10 (B), LED9.10 (B), U8.6 (~OUT1)
/smu_front_disp/C2: LED7.9 (C), LED8.9 (C), LED9.9 (C), U8.7 (~OUT2)
/smu_front_disp/C3: LED7.7 (D), LED8.7 (D), LED9.7 (D), U8.8 (~OUT3)
/smu_front_disp/C4: LED7.1 (E), LED8.1 (E), LED9.1 (E), U8.9 (~OUT4)
/smu_front_disp/C5: LED7.18 (F), LED8.18 (F), LED9.18 (F), U8.10 (~OUT5)
/smu_front_disp/C6: LED7.15 (G), LED8.15 (G), LED9.15 (G), U8.11 (~OUT6)
/smu_front_disp/C7: LED7.14 (H), LED8.14 (H), LED9.14 (H), U8.12 (~OUT7)
/smu_front_disp/C8: LED7.6 (J), LED8.6 (J), LED9.6 (J), U8.13 (~OUT8)
/smu_front_disp/C9: LED7.5 (K), LED8.5 (K), LED9.5 (K), U8.14 (~OUT9)
/smu_front_disp/C10: LED7.4 (L), LED8.4 (L), LED9.4 (L), U8.15 (~OUT10)
/smu_front_disp/C11: LED7.2 (M), LED8.2 (M), LED9.2 (M), U8.16 (~OUT11)
/smu_front_disp/C12: LED7.13 (N), LED8.13 (N), LED9.13 (N), U8.17 (~OUT12)
/smu_front_disp/C13: LED7.17, LED8.17, LED9.17, U8.18 (~OUT13)
/smu_front_disp/C14: LED7.8 (DP), LED8.8 (DP), LED9.8 (DP), U8.19 (~OUT14)
/smu_front_disp/CA0: LED1.16 (COM1), LED4.16 (COM1), LED7.16 (COM1), Q1.3 (D)
/smu_front_disp/CA1: LED1.11 (COM2), LED4.11 (COM2), LED7.11 (COM2), Q2.3 (D)
/smu_front_disp/CA2: LED2.16 (COM1), LED5.16 (COM1), LED8.16 (COM1), Q3.3 (D)
/smu_front_disp/CA3: LED2.11 (COM2), LED5.11 (COM2), LED8.11 (COM2), Q4.3 (D)
/smu_front_disp/CA4: LED3.16 (COM1), LED6.16 (COM1), LED9.16 (COM1), Q5.3 (D)
/smu_front_disp/CA5: LED3.11 (COM2), LED6.11 (COM2), LED9.11 (COM2), Q6.3 (D)
GND: C6.2, C7.2, C8.2, C11.2, R16.2, R17.2, R18.2, U6.1 (GND), U7.1 (GND), U8.1 (GND), U9.4 (E1), U9.5 (E2), U9.8 (GND); also elsewhere on the board
unnamed: Q1.1 (G), U9.10 (O5)
unnamed: Q2.1 (G), U9.11 (O4)
unnamed: Q3.1 (G), U9.12 (O3)
unnamed: Q4.1 (G), U9.13 (O2)
unnamed: Q5.1 (G), U9.14 (O1)
unnamed: Q6.1 (G), U9.15 (O0)
unnamed: R16.1, U6.23 (R-EXT)
unnamed: R17.1, U7.23 (R-EXT)
unnamed: R18.1, U8.23 (R-EXT)
unnamed: U6.22 (SDO), U7.2 (SDI)
unnamed: U7.22 (SDO), U8.2 (SDI)

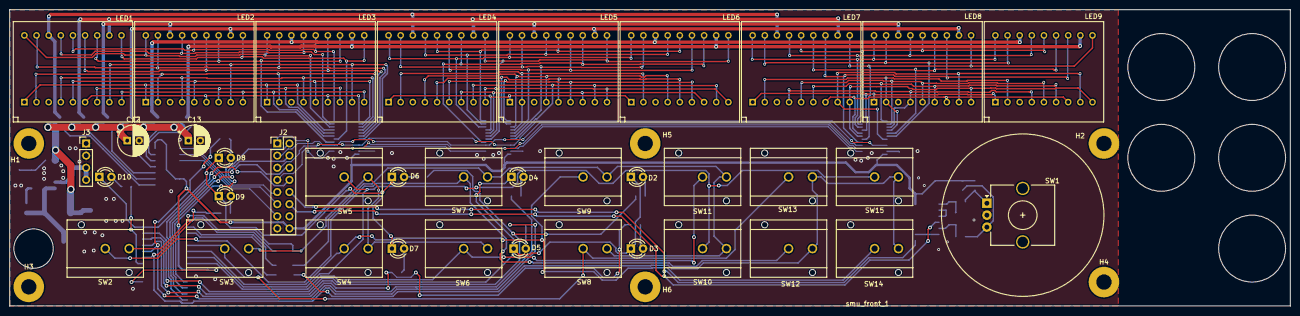
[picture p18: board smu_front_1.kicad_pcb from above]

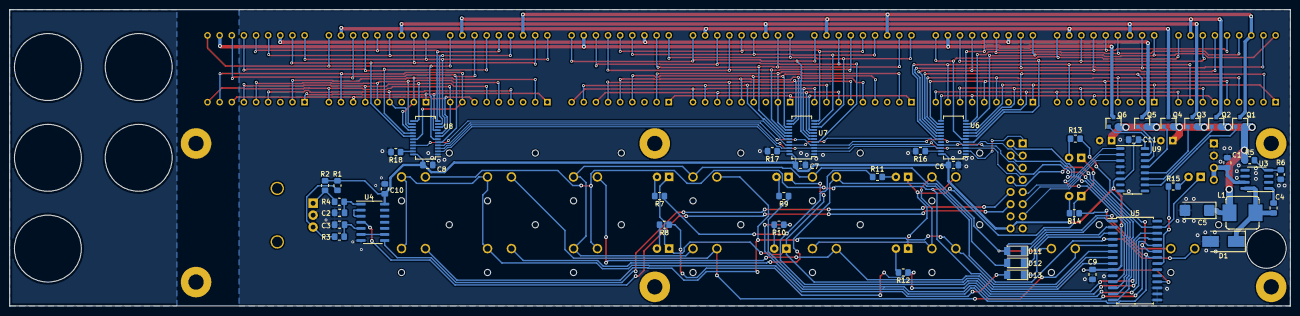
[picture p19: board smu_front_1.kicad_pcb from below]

Board: 2 copper layers, 268.0 x 62.0 mm, 90 parts (47 on the bottom side), 115 nets.

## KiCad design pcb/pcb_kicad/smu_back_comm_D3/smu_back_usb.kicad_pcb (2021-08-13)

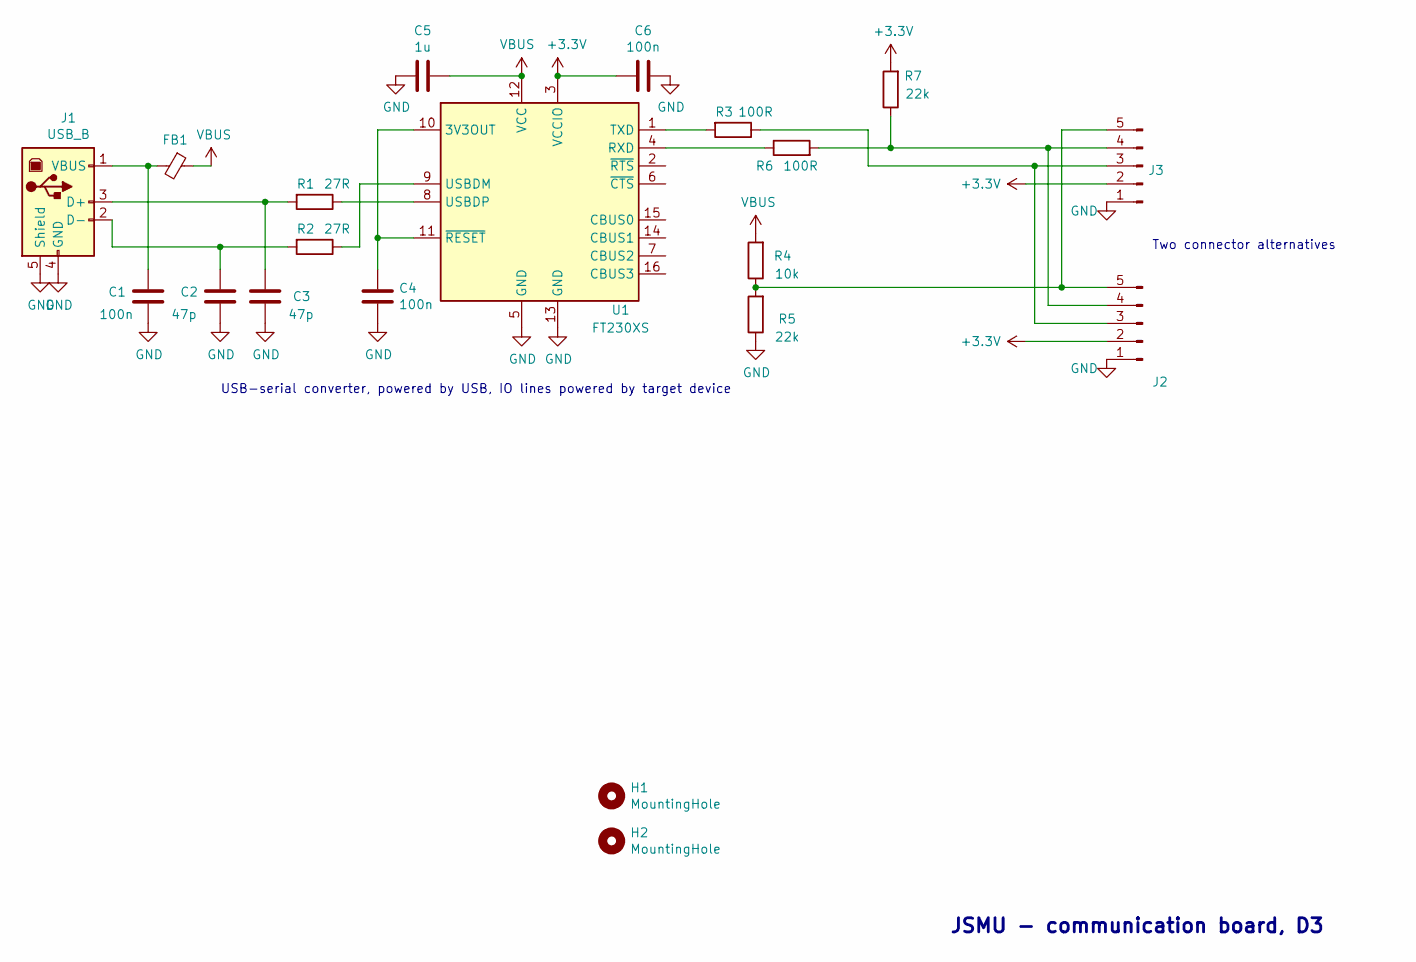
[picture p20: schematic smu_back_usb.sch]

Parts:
C1, C4, C6: 100n; C_0805_2012Metric_Pad1.18x1.45mm_HandSolder
C2, C3: 47p; C_0805_2012Metric_Pad1.18x1.45mm_HandSolder
C5: 1u; C_0805_2012Metric_Pad1.18x1.45mm_HandSolder
FB1: Ferrite_Bead_Small; L_0805_2012Metric_Pad1.05x1.20mm_HandSolder
H1, H2: MountingHole; MountingHole_3.2mm_M3_ISO7380_Pad
J1: USB_B; USB_B_TE_5787834_Vertical
J2, J3: Conn_01x05_Male; Molex_KK-254_AE-6410-05A_1x05_P2.54mm_Vertical
R1, R2: 27R; R_0805_2012Metric_Pad1.20x1.40mm_HandSolder
R3, R6: 100R; R_0805_2012Metric_Pad1.20x1.40mm_HandSolder
R4: 10k; R_0805_2012Metric_Pad1.20x1.40mm_HandSolder
R5, R7: 22k; R_0805_2012Metric_Pad1.20x1.40mm_HandSolder
U1: FT230XS; SSOP-16_3.9x4.9mm_P0.635mm

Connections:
+3V3: C6.2, J2.2, J3.2, R7.2, U1.3 (VCCIO)
GND: C1.2, C2.2, C3.2, C4.2, C5.2, C6.1, J1.4 (GND), J1.5 (Shield), J2.1, J3.1, R5.1, U1.5 (GND), U1.13 (GND)
unnamed: C1.1, FB1.2, J1.1 (VBUS)
unnamed: C2.1, J1.2 (D-), R2.2
unnamed: C3.1, J1.3 (D+), R1.2
unnamed: C4.1, U1.10 (3V3OUT), U1.11 (~RESET)
unnamed: J2.3, J3.3, R3.1
unnamed: J2.4, J3.4, R6.2, R7.1
unnamed: J2.5, J3.5, R4.1, R5.2
unnamed: R1.1, U1.8 (USBDP)
unnamed: R2.1, U1.9 (USBDM)
unnamed: R3.2, U1.1 (TXD)
unnamed: R6.1, U1.4 (RXD)
VBUS: C5.1, FB1.1, R4.2, U1.12 (VCC)

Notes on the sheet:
Two connector alternatives
USB-serial converter, powered by USB, IO lines powered by target device
JSMU - communication board, D3

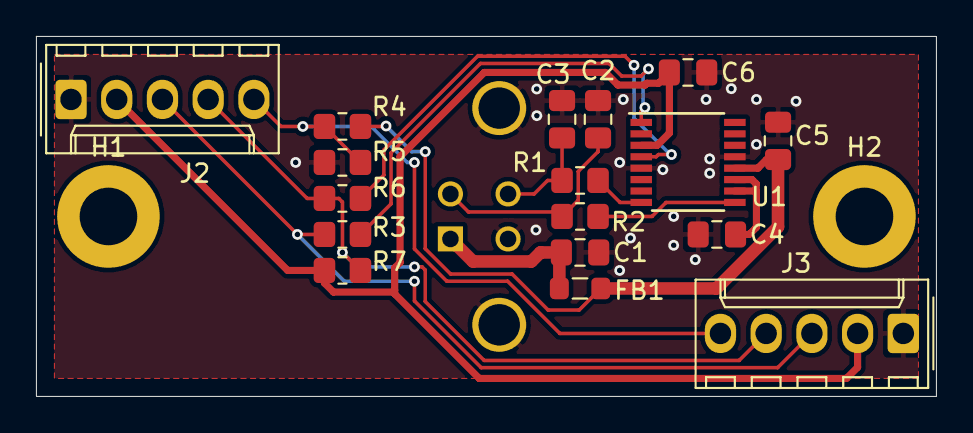
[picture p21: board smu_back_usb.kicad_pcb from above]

Board: 2 copper layers, 50.0 x 20.0 mm, 20 parts (1 on the bottom side), 14 nets.

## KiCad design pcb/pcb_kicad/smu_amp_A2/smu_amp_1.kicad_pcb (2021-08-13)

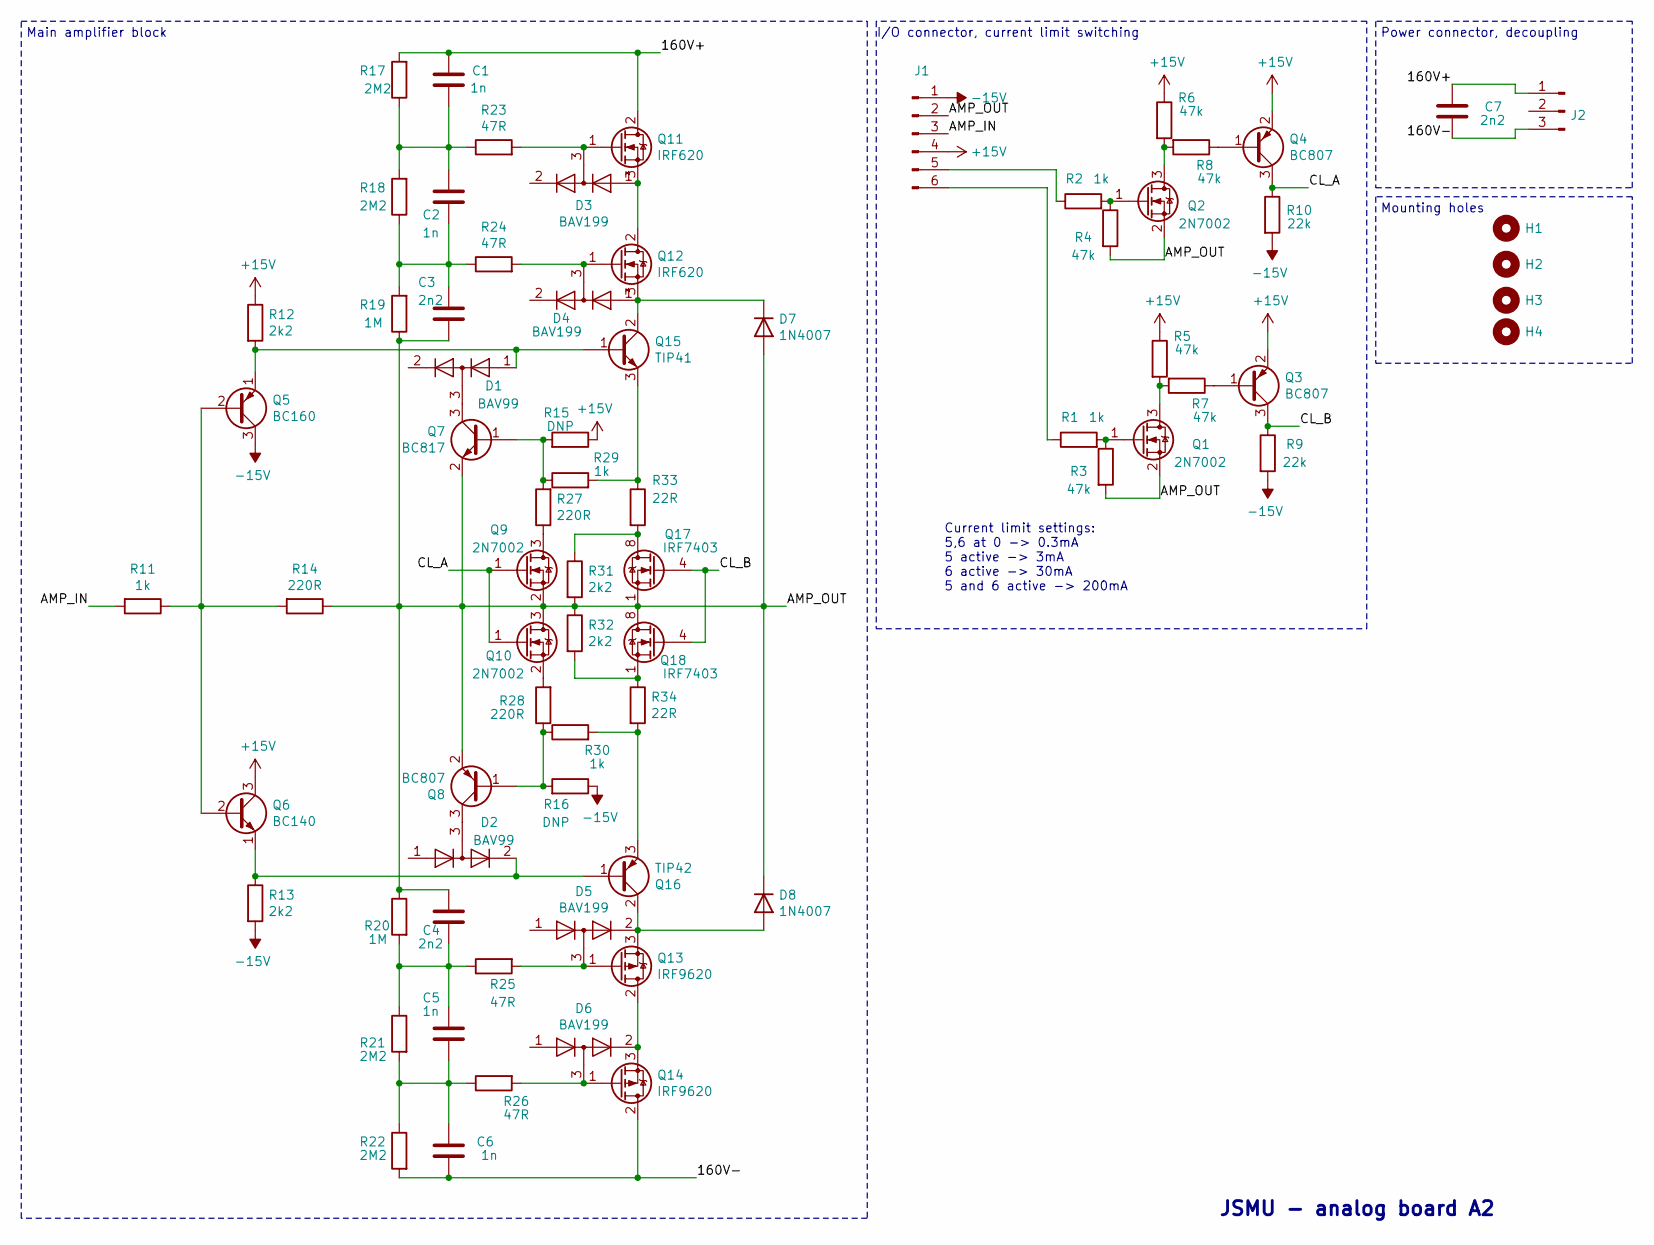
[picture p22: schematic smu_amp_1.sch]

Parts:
C1, C2, C5, C6: 1n; C_1206_3216Metric_Pad1.33x1.80mm_HandSolder
C3, C4: 2n2; C_1206_3216Metric_Pad1.33x1.80mm_HandSolder
C7: 2n2; C_Axial_L19.0mm_D7.5mm_P25.00mm_Horizontal
D1, D2: BAV99; SOT-23
D3, D4, D5, D6: BAV199; SOT-23
D7, D8: 1N4007; D_DO-41_SOD81_P10.16mm_Horizontal
H1, H2, H3, H4: MountingHole; MountingHole_3.2mm_M3_ISO14580_Pad
J1: Conn_01x06_Male; Molex_KK-396_A-41791-0006_1x06_P3.96mm_Vertical
J2: Conn_01x03_Male; Molex_KK-396_A-41791-0003_1x03_P3.96mm_Vertical
Q1, Q2, Q9, Q10: 2N7002; SOT-23
Q3, Q4, Q8: BC807; SOT-23
Q5: BC160; TO-39-3
Q6: BC140; TO-39-3
Q7: BC817; SOT-23
Q11, Q12: IRF620; TO-220-3_Vertical
Q13, Q14: IRF9620; TO-220-3_Vertical
Q15: TIP41; TO-220-3_Vertical
Q16: TIP42; TO-220-3_Vertical
Q17, Q18: IRF7403; SOIC-8_3.9x4.9mm_P1.27mm
R1, R2, R29, R30: 1k; C_0805_2012Metric_Pad1.18x1.45mm_HandSolder
R3, R4, R5, R6, R7, R8: 47k; C_0805_2012Metric_Pad1.18x1.45mm_HandSolder
R9, R10: 22k; C_0805_2012Metric_Pad1.18x1.45mm_HandSolder
R11: 1k; R_0805_2012Metric_Pad1.20x1.40mm_HandSolder
R12, R13, R31, R32: 2k2; R_Axial_DIN0309_L9.0mm_D3.2mm_P15.24mm_Horizontal
R14: 220R; R_0805_2012Metric_Pad1.20x1.40mm_HandSolder
R15, R16: DNP; C_0805_2012Metric_Pad1.18x1.45mm_HandSolder
R17, R18, R21, R22: 2M2; R_1206_3216Metric_Pad1.30x1.75mm_HandSolder
R19, R20: 1M; R_1206_3216Metric_Pad1.30x1.75mm_HandSolder
R23, R24, R25, R26: 47R; C_0805_2012Metric_Pad1.18x1.45mm_HandSolder
R27, R28: 220R; C_0805_2012Metric_Pad1.18x1.45mm_HandSolder
R33, R34: 22R; R_Axial_DIN0309_L9.0mm_D3.2mm_P15.24mm_Horizontal

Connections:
+15V: J1.4, Q3.2 (E), Q4.2 (E), Q6.3 (C), R5.1, R6.1, R12.1, R15.1
-15V: J1.1, Q5.3 (C), R9.2, R10.2, R13.2, R16.1
/160V+: C1.1, C7.1, J2.1, Q11.2 (D), R17.2
/160V-: C6.1, C7.2, J2.3, Q14.2 (D), R22.2
/AMP_IN: J1.3, R11.2
/AMP_OUT: C3.2, C4.1, D7.2 (A), D8.1 (K), J1.2, Q1.2 (S), Q2.2 (S), Q7.2 (E), Q8.2 (E), Q9.2 (S), Q10.3 (D), Q17.1 (S), Q17.2 (S), Q17.3 (S), Q18.5 (D), Q18.6 (D), Q18.7 (D), Q18.8 (D), R3.2, R4.2, R14.1, R19.1, R20.1, R31.2, R32.1
/CL_A: Q4.3 (C), Q9.1 (G), Q10.1 (G), R10.1
/CL_B: Q3.3 (C), Q17.4 (G), Q18.4 (G), R9.1
unnamed: C1.2, C2.1, R17.1, R18.2, R23.1
unnamed: C2.2, C3.1, R18.1, R19.2, R24.1
unnamed: C4.2, C5.2, R20.2, R21.1, R25.1
unnamed: C5.1, C6.2, R21.2, R22.1, R26.1
unnamed: D1.1 (K), Q5.1 (E), Q15.1 (B), R12.2
unnamed: D1.3 (K), Q7.3 (C)
unnamed: D2.2 (A), Q6.1 (E), Q16.1 (B), R13.1
unnamed: D2.3 (K), Q8.3 (C)
unnamed: D3.1 (K), Q11.3 (S), Q12.2 (D)
unnamed: D3.3 (K), Q11.1 (G), R23.2
unnamed: D4.1 (K), D7.1 (K), Q12.3 (S), Q15.2 (C)
unnamed: D4.3 (K), Q12.1 (G), R24.2
unnamed: D5.2 (A), D8.2 (A), Q13.3 (S), Q16.2 (C)
unnamed: D5.3 (K), Q13.1 (G), R25.2
unnamed: D6.2 (A), Q13.2 (D), Q14.3 (S)
unnamed: D6.3 (K), Q14.1 (G), R26.2
unnamed: J1.5, R2.1
unnamed: J1.6, R1.1
unnamed: Q1.1 (G), R1.2, R3.1
unnamed: Q1.3 (D), R5.2, R7.2
unnamed: Q2.1 (G), R2.2, R4.1
unnamed: Q2.3 (D), R6.2, R8.2
unnamed: Q3.1 (B), R7.1
unnamed: Q4.1 (B), R8.1
unnamed: Q5.2 (B), Q6.2 (B), R11.1, R14.2
unnamed: Q7.1 (B), R15.2, R27.2, R29.1
unnamed: Q8.1 (B), R16.2, R28.1, R30.1
unnamed: Q9.3 (D), R27.1
unnamed: Q10.2 (S), R28.2
unnamed: Q15.3 (E), R29.2, R33.1
unnamed: Q16.3 (E), R30.2, R34.2
unnamed: Q17.5 (D), Q17.6 (D), Q17.7 (D), Q17.8 (D), R31.1, R33.2
unnamed: Q18.1 (S), Q18.2 (S), Q18.3 (S), R32.2, R34.1

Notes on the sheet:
Current limit settings: 5,6 at 0 -> 0.3mA 5 active -> 3mA 6 active -> 30mA 5 and 6 active -> 200mA
Mounting holes
Power connector, decoupling
I/O connector, current limit switching
Main amplifier block
JSMU - analog board A2

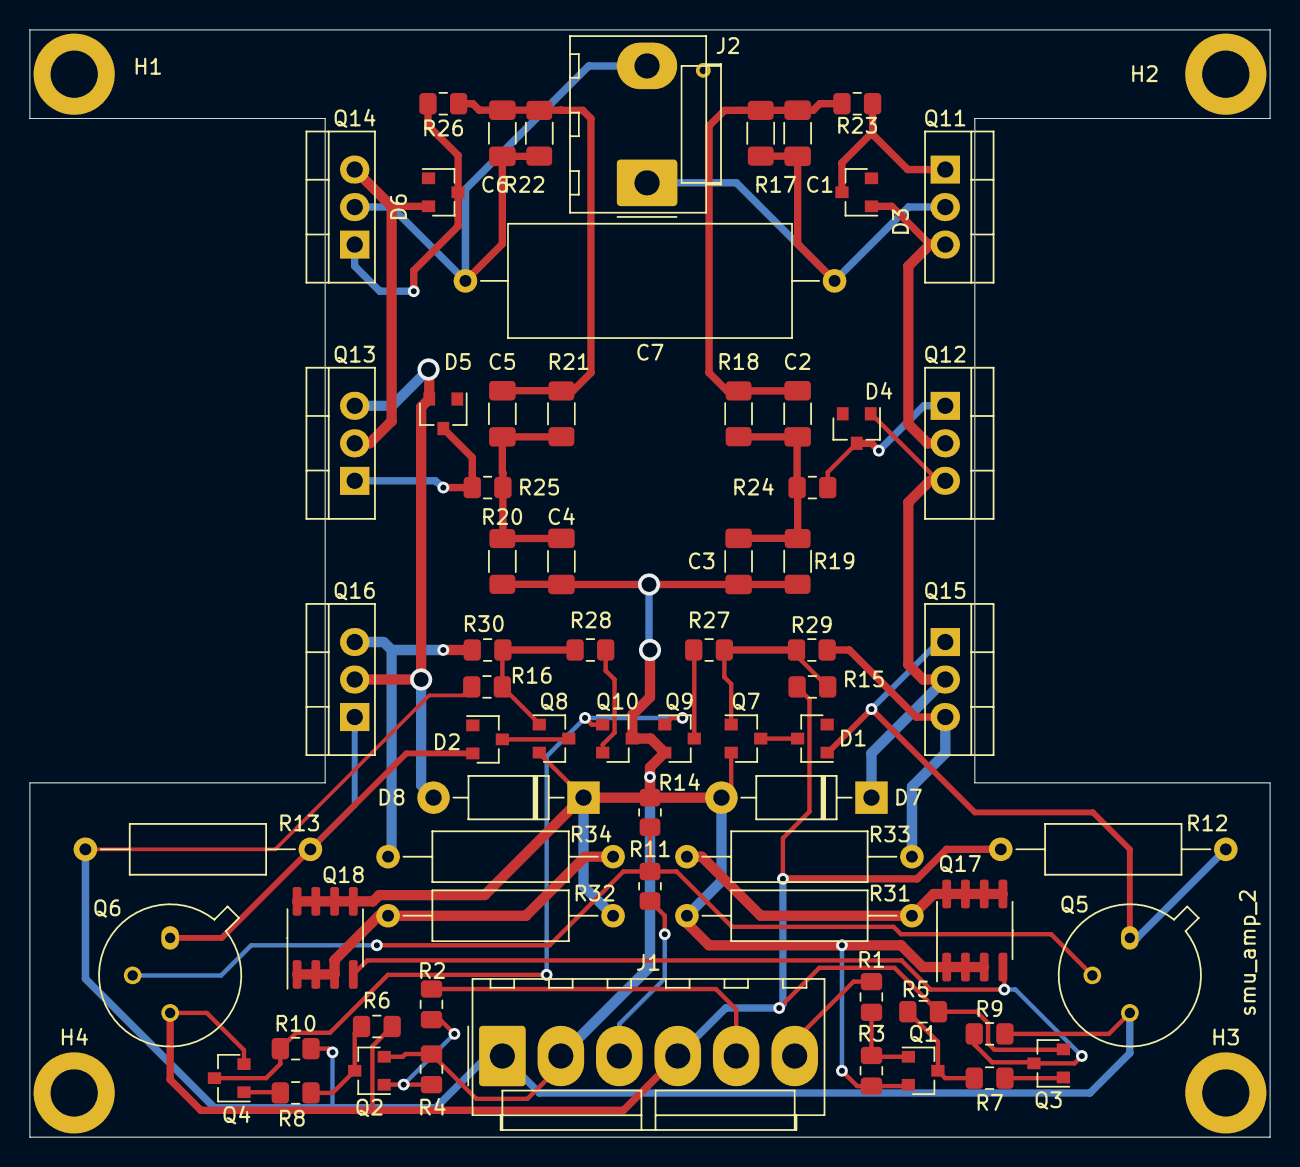
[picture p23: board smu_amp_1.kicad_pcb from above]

Board: 2 copper layers, 84.0 x 75.0 mm, 73 parts (0 on the bottom side), 41 nets.

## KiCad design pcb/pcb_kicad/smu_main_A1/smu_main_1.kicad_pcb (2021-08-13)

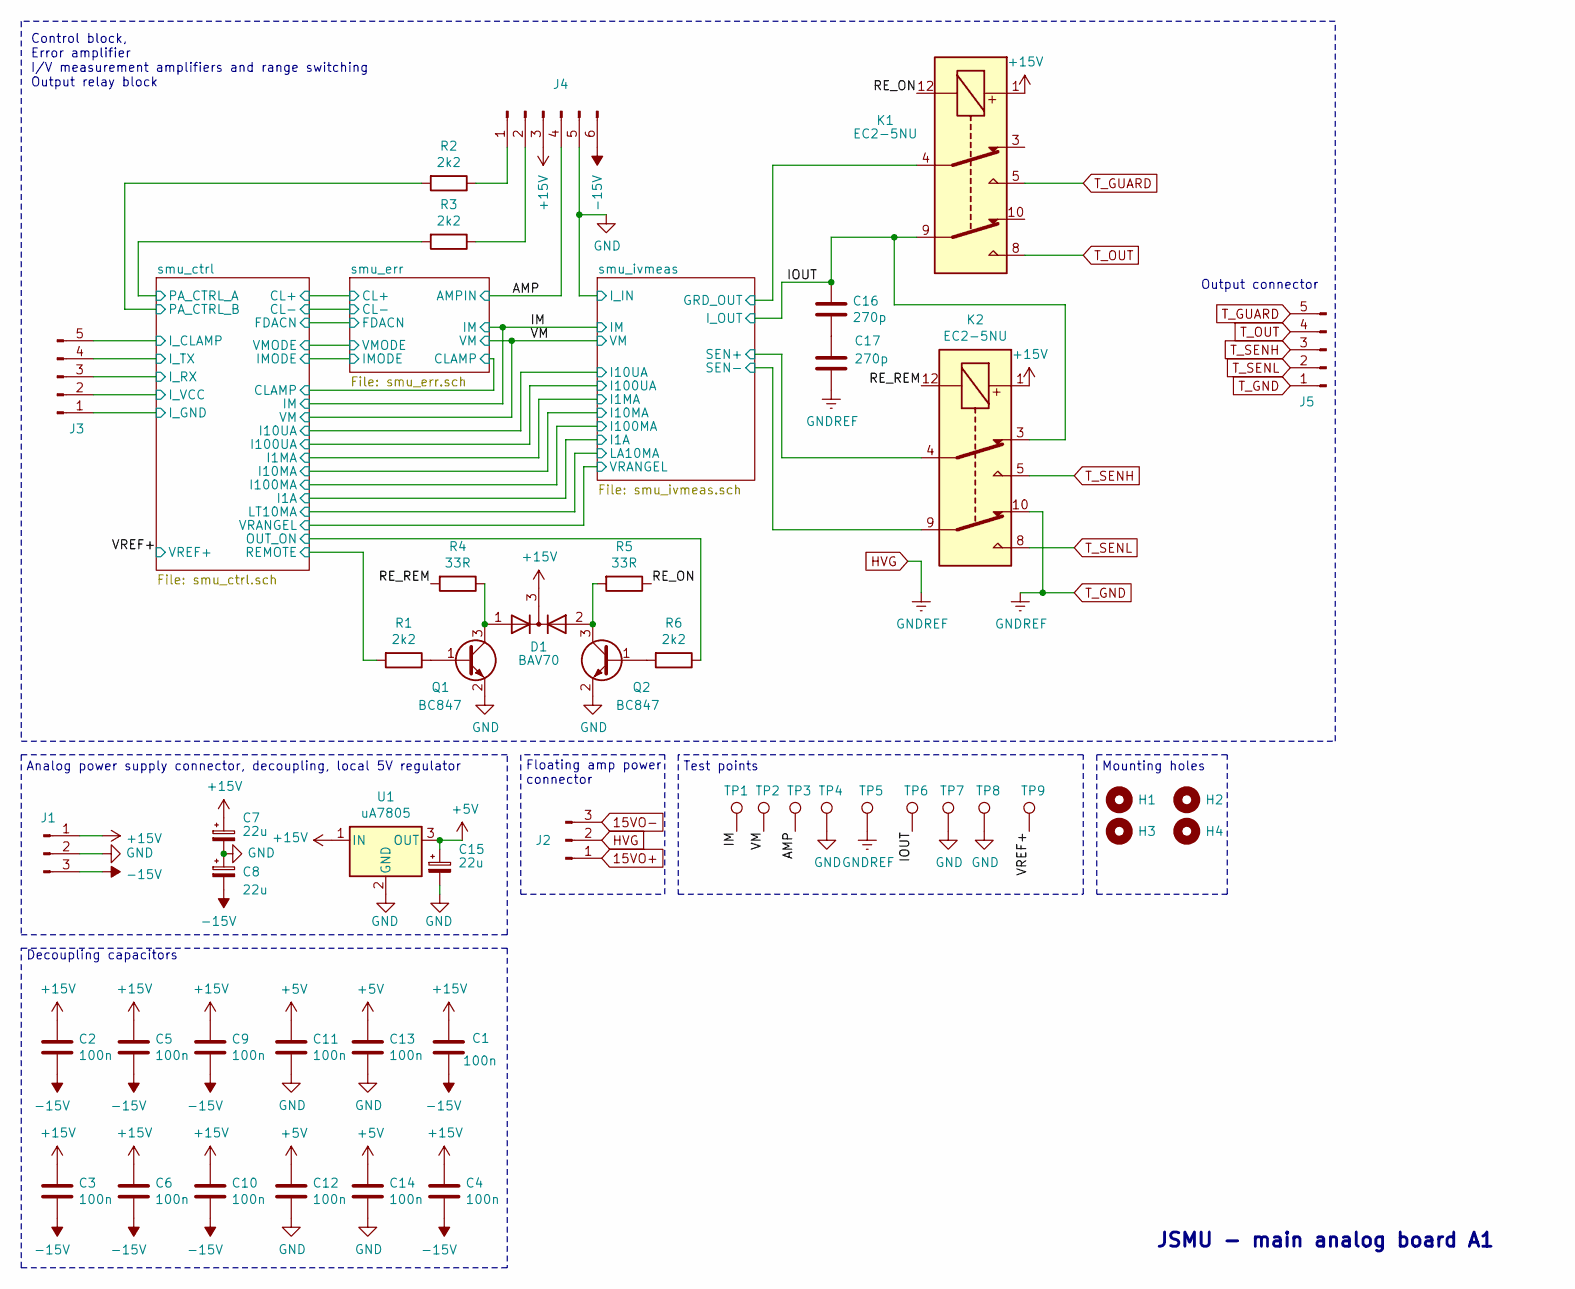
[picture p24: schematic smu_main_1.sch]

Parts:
C1, C4: 100n; C_0805_2012Metric_Pad1.18x1.45mm_HandSolder
C2, C3, C5, C6, C9, C10, C11, C12, C13, C14: 100n; C_0603_1608Metric_Pad1.08x0.95mm_HandSolder
C7, C8, C15: 22u; CP_EIA-6032-28_Kemet-C_Pad2.25x2.35mm_HandSolder
C16, C17: 270p; C_1206_3216Metric_Pad1.33x1.80mm_HandSolder
D1: BAV70; SOT-23
H1, H2, H3, H4: MountingHole; MountingHole_3.2mm_M3_ISO7380_Pad
J1: Conn_01x03_Male; Molex_KK-254_AE-6410-03A_1x03_P2.54mm_Vertical
J2: Conn_01x03_Male; Molex_KK-396_A-41791-0003_1x03_P3.96mm_Vertical
J3: Conn_01x05_Male; Molex_KK-254_AE-6410-05A_1x05_P2.54mm_Vertical
J4: Conn_01x06_Male; Molex_KK-396_A-41791-0006_1x06_P3.96mm_Vertical
J5: Conn_01x05_Male; Molex_KK-396_A-41791-0005_1x05_P3.96mm_Vertical
K1, K2: EC2-5NU; Relay_DPDT_Kemet_EC2
Q1, Q2: BC847; SOT-23
R1, R2, R3, R6: 2k2; R_0805_2012Metric_Pad1.20x1.40mm_HandSolder
R4, R5: 33R; R_0805_2012Metric_Pad1.20x1.40mm_HandSolder
TP1, TP2, TP3, TP4, TP5, TP6, TP7, TP8, TP9: TestPoint; TestPoint_Loop_D1.80mm_Drill1.0mm_Beaded
U1: uA7805; TO-263-3_TabPin2

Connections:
15VO+: J2.1; also elsewhere on the board
15VO-: J2.3; also elsewhere on the board
+5V: C11.1, C12.1, C13.1, C14.1, C15.1, U1.3 (OUT); also elsewhere on the board
+15V: C1.1, C2.1, C3.1, C4.1, C5.1, C6.1, C7.1, C9.1, C10.1, D1.3 (K), J1.1, J4.3, K1.1, K2.1, U1.1 (IN); also elsewhere on the board
-15V: C1.2, C2.2, C3.2, C4.2, C5.2, C6.2, C8.2, C9.2, C10.2, J1.3, J4.6; also elsewhere on the board
/AMP: J4.4, TP3.1; also elsewhere on the board
/IM: TP1.1; also elsewhere on the board
/IOUT: C16.1, K1.9, K2.3, TP6.1; also elsewhere on the board
/RE_ON: K1.12, R5.1
/RE_REM: K2.12, R4.2
/VM: TP2.1; also elsewhere on the board
/VREF+: TP9.1; also elsewhere on the board
/smu_ctrl/I_CLAMP: J3.5; also elsewhere on the board
/smu_ctrl/I_GND: J3.1; also elsewhere on the board
/smu_ctrl/I_RX: J3.3; also elsewhere on the board
/smu_ctrl/I_TX: J3.4; also elsewhere on the board
/smu_ctrl/I_VCC: J3.2; also elsewhere on the board
/smu_ctrl/OUT_ON: R6.1; also elsewhere on the board
/smu_ctrl/PA_CTRL_A: R3.2; also elsewhere on the board
/smu_ctrl/PA_CTRL_B: R2.2; also elsewhere on the board
/smu_ctrl/REMOTE: R1.2; also elsewhere on the board
/smu_ivmeas/GRD_OUT: K1.4; also elsewhere on the board
/smu_ivmeas/SEN+: K2.4; also elsewhere on the board
/smu_ivmeas/SEN-: K2.9; also elsewhere on the board
GND: C7.2, C8.1, C11.2, C12.2, C13.2, C14.2, C15.2, J1.2, J4.5, Q1.2 (E), Q2.2 (E), TP4.1, TP7.1, TP8.1, U1.2 (GND); also elsewhere on the board
HVG: C17.2, J2.2, J5.1, K2.10, TP5.1; also elsewhere on the board
unnamed: C16.2, C17.1
unnamed: D1.1 (A), Q1.3 (C), R4.1
unnamed: D1.2 (A), Q2.3 (C), R5.2
unnamed: J4.1, R2.1
unnamed: J4.2, R3.1
unnamed: Q1.1 (B), R1.1
unnamed: Q2.1 (B), R6.2
T_GUARD: J5.5, K1.5
T_OUT: J5.4, K1.8
T_SENH: J5.3, K2.5
T_SENL: J5.2, K2.8

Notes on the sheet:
Control block, Error amplifier I/V measurement amplifiers and range switching Output relay block
Analog power supply connector, decoupling, local 5V regulator
Decoupling capacitors
Floating amp power connector
Test points
Mounting holes
Output connector
JSMU - main analog board A1

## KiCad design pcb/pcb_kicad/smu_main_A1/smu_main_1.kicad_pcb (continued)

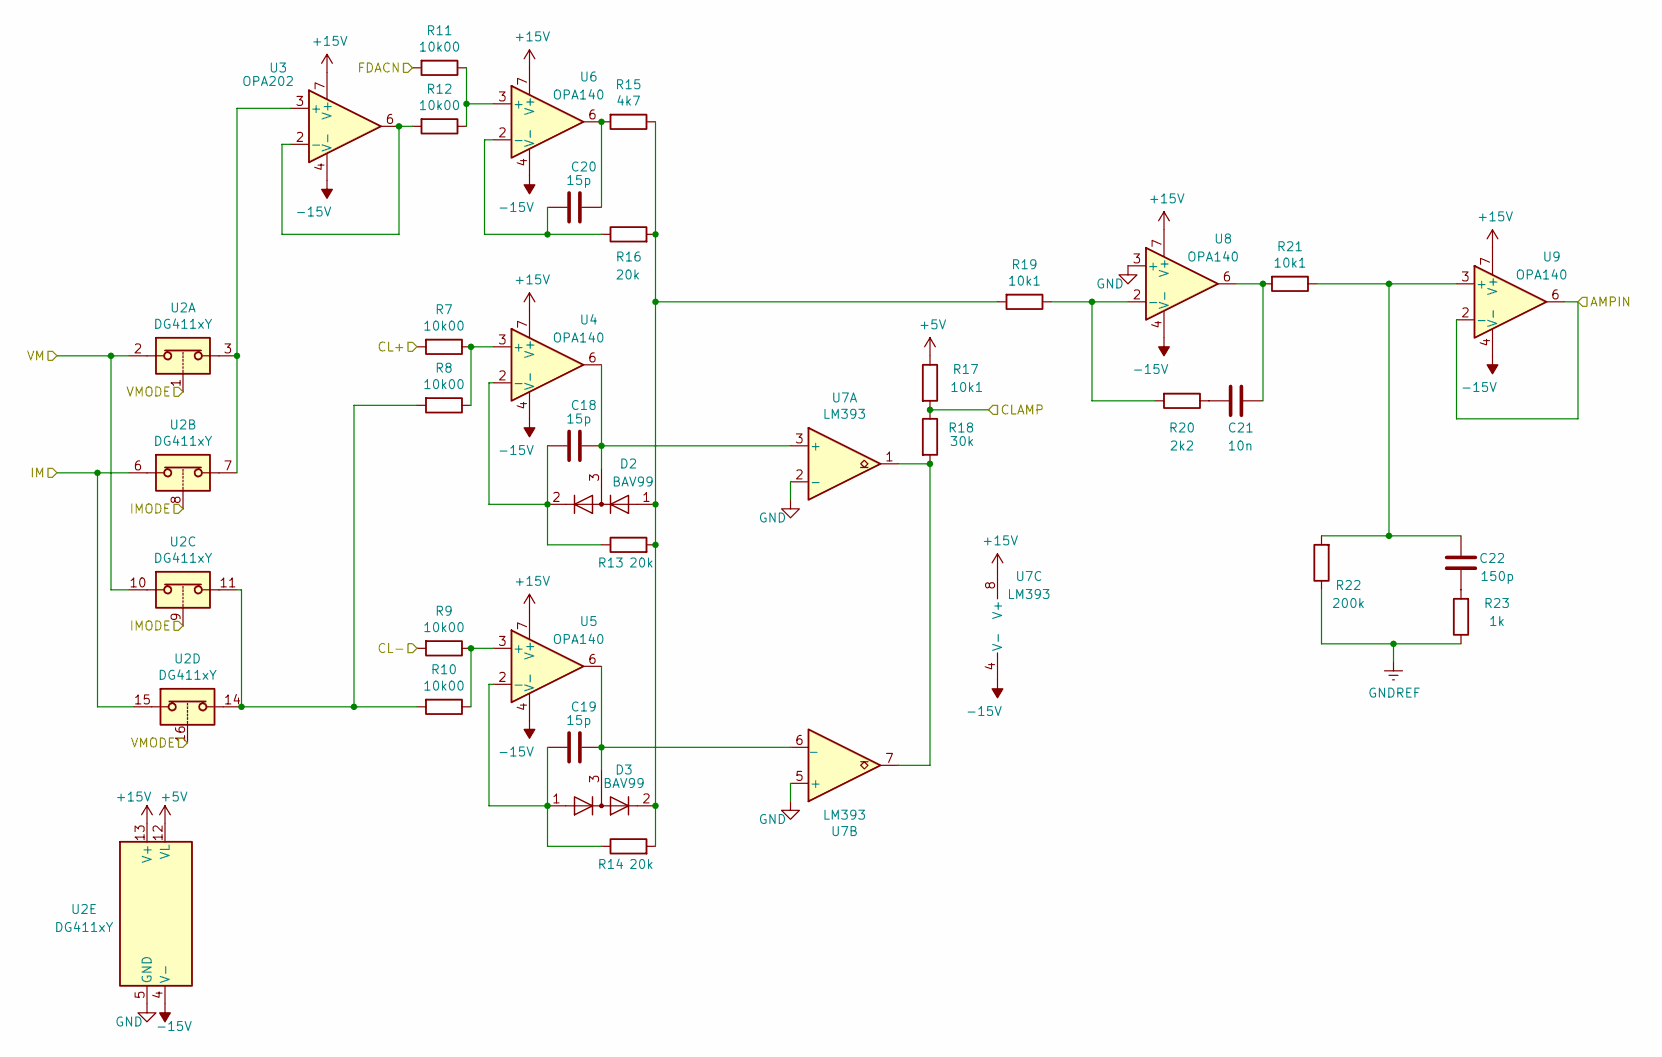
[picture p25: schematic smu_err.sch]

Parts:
C18, C19, C20: 15p; C_0805_2012Metric_Pad1.18x1.45mm_HandSolder
C21: 10n; C_0805_2012Metric_Pad1.18x1.45mm_HandSolder
C22: 150p; C_0805_2012Metric_Pad1.18x1.45mm_HandSolder
D2, D3: BAV99; SOT-23
R7, R8, R9, R10, R11, R12: 10k00; R_0805_2012Metric_Pad1.20x1.40mm_HandSolder
R13, R14, R16: 20k; R_0805_2012Metric_Pad1.20x1.40mm_HandSolder
R15: 4k7; R_0805_2012Metric_Pad1.20x1.40mm_HandSolder
R17, R19, R21: 10k1; R_0805_2012Metric_Pad1.20x1.40mm_HandSolder
R18: 30k; R_0805_2012Metric_Pad1.20x1.40mm_HandSolder
R20: 2k2; R_0805_2012Metric_Pad1.20x1.40mm_HandSolder
R22: 200k; R_1206_3216Metric_Pad1.30x1.75mm_HandSolder
R23: 1k; R_0805_2012Metric_Pad1.20x1.40mm_HandSolder
U2: DG411xY; SOIC-16_3.9x9.9mm_P1.27mm
U3: OPA202; SOIC-8_3.9x4.9mm_P1.27mm
U4, U5, U6, U8, U9: OPA140; SOIC-8_3.9x4.9mm_P1.27mm
U7: LM393; SOIC-8_3.9x4.9mm_P1.27mm

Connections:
+5V: R17.1, U2.12 (VL); also elsewhere on the board
+15V: U2.13 (V+), U3.7 (V+), U4.7 (V+), U5.7 (V+), U6.7 (V+), U7.8 (V+), U8.7 (V+), U9.7 (V+); also elsewhere on the board
-15V: U2.4 (V-), U3.4 (V-), U4.4 (V-), U5.4 (V-), U6.4 (V-), U7.4 (V-), U8.4 (V-), U9.4 (V-); also elsewhere on the board
/AMP: U9.2 (-), U9.6; also elsewhere on the board
/IM: U2.6, U2.15; also elsewhere on the board
/VM: U2.2, U2.10; also elsewhere on the board
/smu_ctrl/CL+: R7.2; also elsewhere on the board
/smu_ctrl/CL-: R9.2; also elsewhere on the board
/smu_ctrl/CLAMP: R17.2, R18.1; also elsewhere on the board
/smu_ctrl/FDACN: R11.2; also elsewhere on the board
/smu_ctrl/IMODE: U2.8, U2.9; also elsewhere on the board
/smu_ctrl/VMODE: U2.1, U2.16; also elsewhere on the board
GND: U2.5 (GND), U7.2 (-), U7.5 (+), U8.3 (+); also elsewhere on the board
HVG: R22.1, R23.1; also elsewhere on the board
unnamed: C18.1, D2.3 (K), U4.6, U7.3 (+)
unnamed: C18.2, D2.2 (A), R13.1, U4.2 (-)
unnamed: C19.1, D3.3 (K), U5.6, U7.6 (_)
unnamed: C19.2, D3.1 (K), R14.1, U5.2 (-)
unnamed: C20.1, R15.2, U6.6
unnamed: C20.2, R16.1, U6.2 (-)
unnamed: C21.1, R21.2, U8.6
unnamed: C21.2, R20.1
unnamed: C22.1, R23.2
unnamed: C22.2, R21.1, R22.2, U9.3 (+)
unnamed: D2.1 (K), D3.2 (A), R13.2, R14.2, R15.1, R16.2, R19.2
unnamed: R7.1, R8.1, U4.3 (+)
unnamed: R9.1, R10.1, U5.3 (+)
unnamed: R8.2, R10.2, U2.11, U2.14
unnamed: R11.1, R12.1, U6.3 (+)
unnamed: R12.2, U3.2 (-), U3.6
unnamed: R18.2, U7.1, U7.7
unnamed: R19.1, R20.2, U8.2 (-)
unnamed: U2.3, U2.7, U3.3 (+)

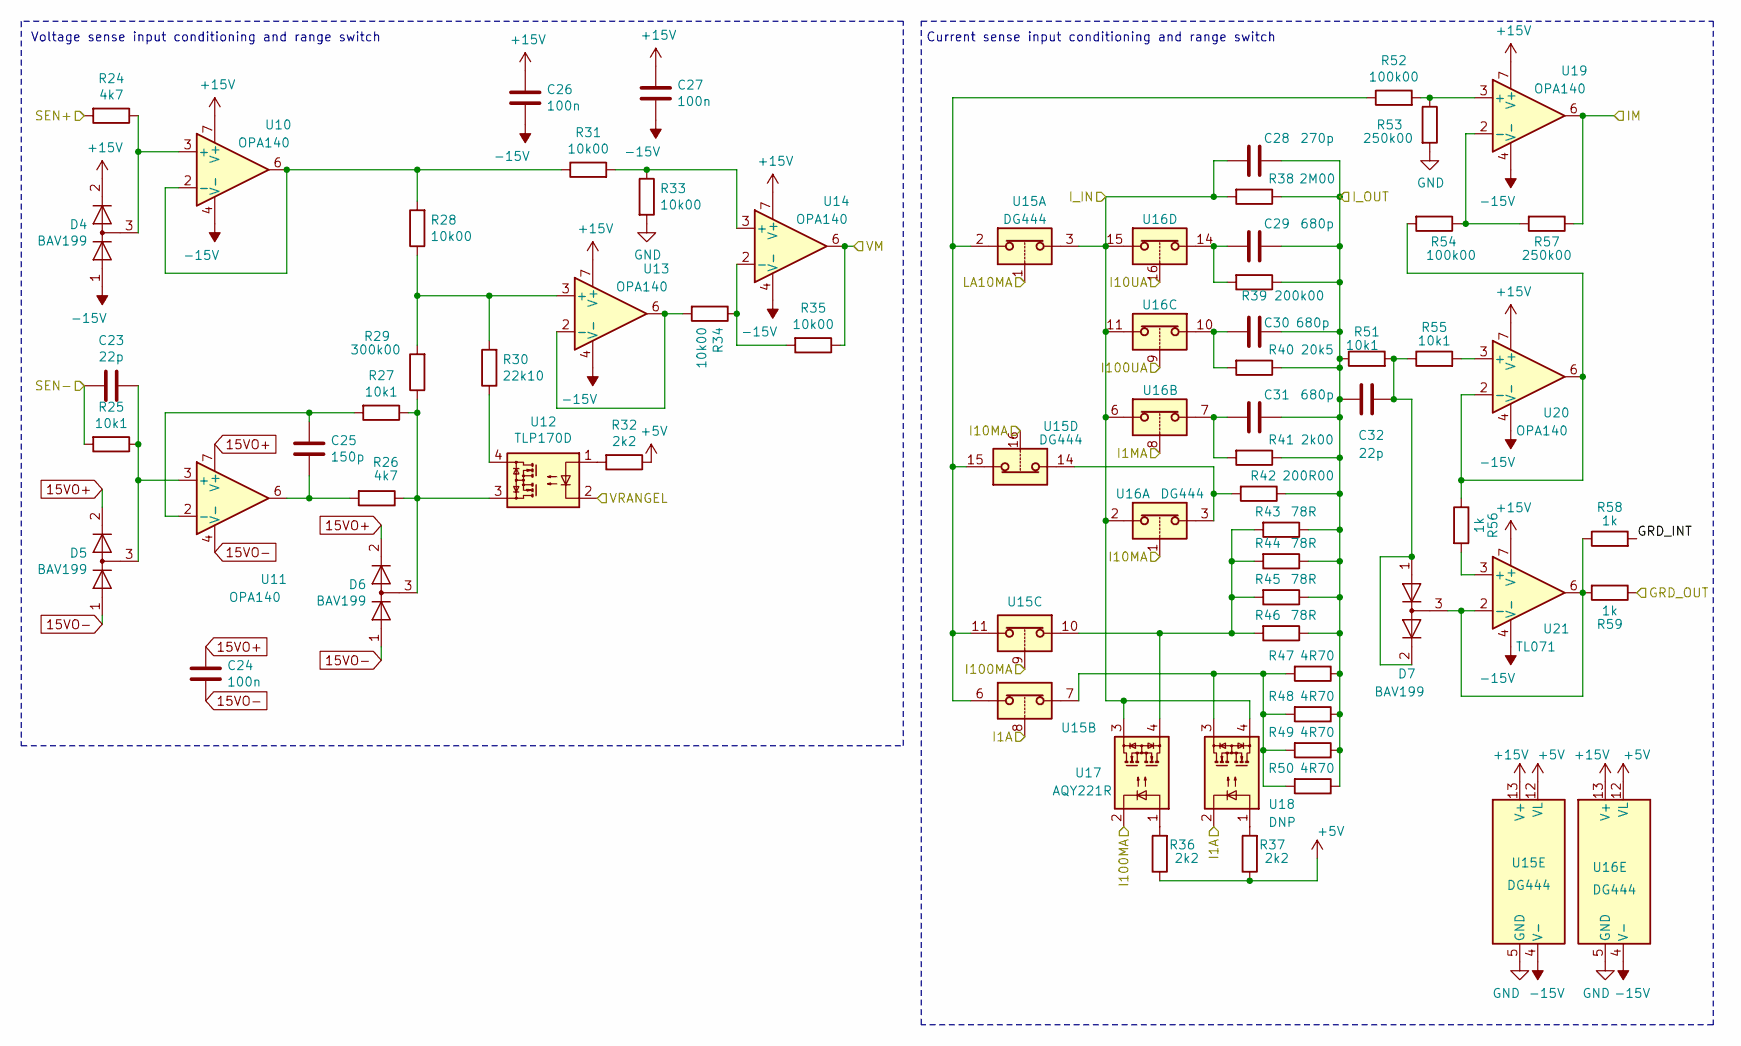
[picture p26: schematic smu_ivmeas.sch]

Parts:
C23: 22p; C_1206_3216Metric_Pad1.33x1.80mm_HandSolder
C24, C26, C27: 100n; C_0805_2012Metric_Pad1.18x1.45mm_HandSolder
C25: 150p; C_0805_2012Metric_Pad1.18x1.45mm_HandSolder
C28: 270p; C_0805_2012Metric_Pad1.18x1.45mm_HandSolder
C29, C30, C31: 680p; C_0805_2012Metric_Pad1.18x1.45mm_HandSolder
C32: 22p; C_0805_2012Metric_Pad1.18x1.45mm_HandSolder
D4, D5, D6, D7: BAV199; SOT-23
R24: 4k7; R_1206_3216Metric_Pad1.30x1.75mm_HandSolder
R25: 10k1; R_1206_3216Metric_Pad1.30x1.75mm_HandSolder
R26: 4k7; R_0805_2012Metric_Pad1.20x1.40mm_HandSolder
R27, R51, R55: 10k1; R_0805_2012Metric_Pad1.20x1.40mm_HandSolder
R28, R31, R33, R34, R35: 10k00; R_0805_2012Metric_Pad1.20x1.40mm_HandSolder
R29: 300k00; R_1206_3216Metric_Pad1.30x1.75mm_HandSolder
R30: 22k10; R_0805_2012Metric_Pad1.20x1.40mm_HandSolder
R32, R36, R37: 2k2; R_0805_2012Metric_Pad1.20x1.40mm_HandSolder
R38: 2M00; R_1206_3216Metric_Pad1.30x1.75mm_HandSolder
R39: 200k00; R_0805_2012Metric_Pad1.20x1.40mm_HandSolder
R40: 20k5; R_0805_2012Metric_Pad1.20x1.40mm_HandSolder
R41: 2k00; R_0805_2012Metric_Pad1.20x1.40mm_HandSolder
R42: 200R00; R_MiniMELF_MMA-0204
R43, R44, R45, R46: 78R; R_1206_3216Metric_Pad1.30x1.75mm_HandSolder
R47, R48, R49, R50: 4R70; R_2512_6332Metric
R52, R54: 100k00; R_0805_2012Metric_Pad1.20x1.40mm_HandSolder
R53, R57: 250k00; R_0805_2012Metric_Pad1.20x1.40mm_HandSolder
R56, R58: 1k; R_0805_2012Metric_Pad1.20x1.40mm_HandSolder
R59: 1k; R_Axial_DIN0309_L9.0mm_D3.2mm_P12.70mm_Horizontal
U10, U11, U13, U14, U19, U20: OPA140; SOIC-8_3.9x4.9mm_P1.27mm
U12: TLP170D; SO-4_4.4x3.9mm_P2.54mm
U15, U16: DG444; SOIC-16_3.9x9.9mm_P1.27mm
U17: AQY221R; SO-4_4.4x3.9mm_P2.54mm
U18: DNP; SO-4_4.4x3.9mm_P2.54mm
U21: TL071; SOIC-8_3.9x4.9mm_P1.27mm

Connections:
15VO+: C24.2, D5.2 (A), D6.2 (A), U11.7 (V+); also elsewhere on the board
15VO-: C24.1, D5.1 (K), D6.1 (K), U11.4 (V-); also elsewhere on the board
+5V: R32.1, R36.1, R37.1, U15.12 (VL), U16.12 (VL); also elsewhere on the board
+15V: C26.2, C27.2, D4.2 (A), U10.7 (V+), U13.7 (V+), U14.7 (V+), U15.13 (V+), U16.13 (V+), U19.7 (V+), U20.7 (V+), U21.7 (V+); also elsewhere on the board
-15V: C26.1, C27.1, D4.1 (K), U10.4 (V-), U13.4 (V-), U14.4 (V-), U15.4 (V-), U16.4 (V-), U19.4 (V-), U20.4 (V-), U21.4 (V-); also elsewhere on the board
/IM: R57.1, U19.6; also elsewhere on the board
/IOUT: C28.1, C29.1, C30.1, C31.1, C32.1, R38.1, R39.1, R40.1, R41.1, R42.1, R43.1, R44.1, R45.1, R46.1, R47.1, R48.1, R49.1, R50.1, R51.1; also elsewhere on the board
/VM: R35.1, U14.6; also elsewhere on the board
/smu_ctrl/I1A: U15.8, U18.2; also elsewhere on the board
/smu_ctrl/I1MA: U16.8; also elsewhere on the board
/smu_ctrl/I10MA: U15.16, U16.1; also elsewhere on the board
/smu_ctrl/I10UA: U16.16; also elsewhere on the board
/smu_ctrl/I100MA: U15.9, U17.2; also elsewhere on the board
/smu_ctrl/I100UA: U16.9; also elsewhere on the board
/smu_ctrl/VRANGEL: U12.2; also elsewhere on the board
/smu_ivmeas/GRD_INT: R58.2
/smu_ivmeas/GRD_OUT: R59.1; also elsewhere on the board
/smu_ivmeas/LA10MA: U15.1; also elsewhere on the board
/smu_ivmeas/SEN+: R24.2; also elsewhere on the board
/smu_ivmeas/SEN-: C23.2, R25.2; also elsewhere on the board
GND: C28.2, R33.2, R38.2, R53.2, U15.3, U15.5 (GND), U16.2, U16.5 (GND), U16.6, U16.11, U16.15, U17.3, U18.4; also elsewhere on the board
unnamed: C23.1, D5.3 (K), R25.1, U11.3 (+)
unnamed: C25.1, R26.2, U11.6
unnamed: C25.2, R27.2, U11.2 (-)
unnamed: C29.2, R39.2, U16.14
unnamed: C30.2, R40.2, U16.10
unnamed: C31.2, R41.2, U16.7
unnamed: C32.2, D7.1 (K), D7.2 (A), R51.2, R55.1
unnamed: D4.3 (K), R24.1, U10.3 (+)
unnamed: D6.3 (K), R26.1, R27.1, R29.1, U12.3
unnamed: D7.3 (K), R58.1, R59.2, U21.2 (-), U21.6
unnamed: R28.1, R29.2, R30.2, U13.3 (+)
unnamed: R28.2, R31.1, U10.2 (-), U10.6
unnamed: R30.1, U12.4
unnamed: R31.2, R33.1, U14.3 (+)
unnamed: R32.2, U12.1
unnamed: R34.1, R35.2, U14.2 (-)
unnamed: R34.2, U13.2 (-), U13.6
unnamed: R36.2, U17.1
unnamed: R37.2, U18.1
unnamed: R42.2, U15.14, U16.3
unnamed: R43.2, R44.2, R45.2, R46.2, U15.10, U17.4
unnamed: R47.2, R48.2, R49.2, R50.2, U15.7, U18.3
unnamed: R52.1, U15.2, U15.6, U15.11, U15.15
unnamed: R52.2, R53.1, U19.3 (+)
unnamed: R54.1, R57.2, U19.2 (-)
unnamed: R54.2, R56.1, U20.2 (-), U20.6
unnamed: R55.2, U20.3 (+)
unnamed: R56.2, U21.3 (+)

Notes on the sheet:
Voltage sense input conditioning and range switch
Current sense input conditioning and range switch

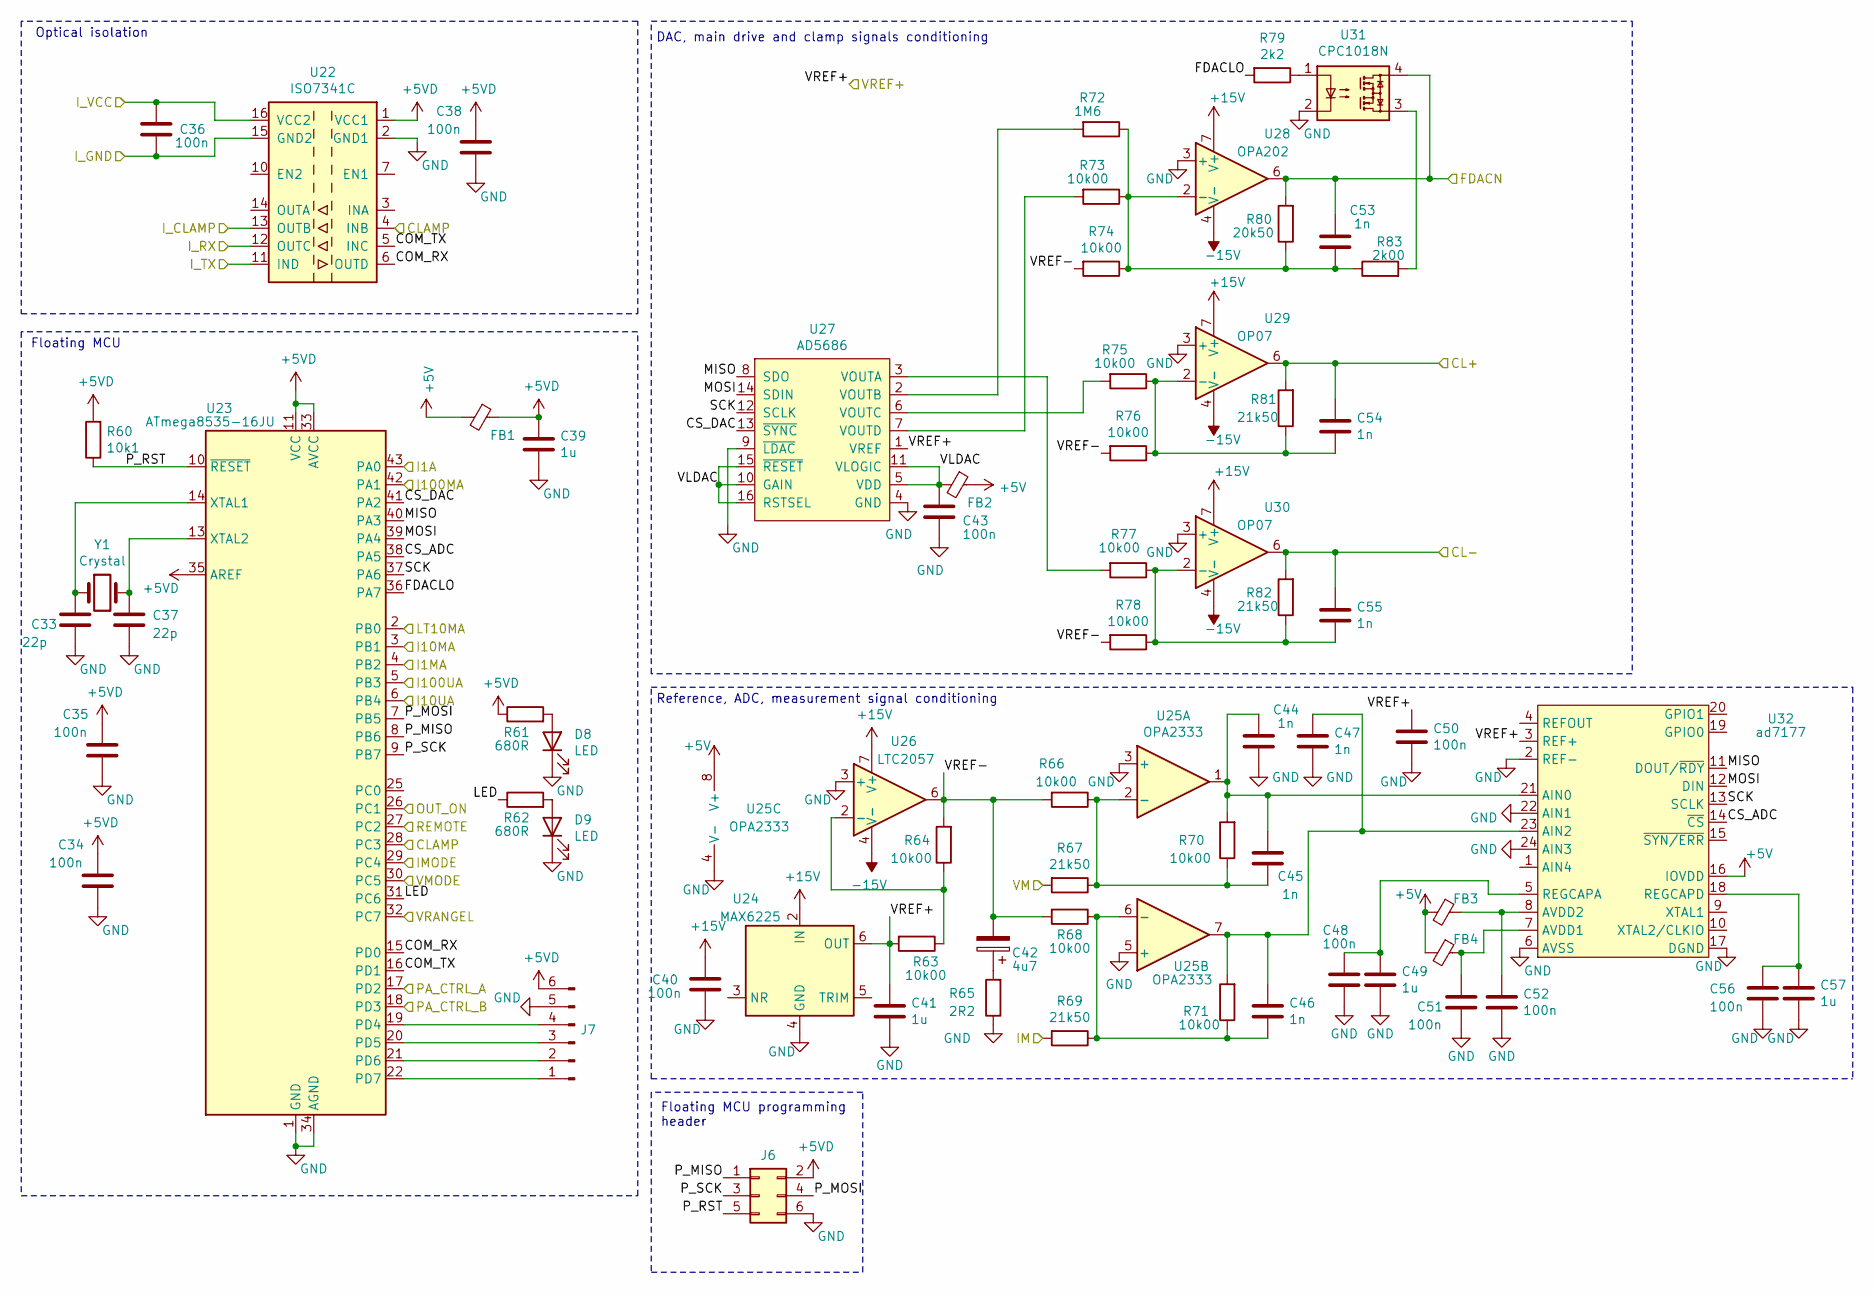
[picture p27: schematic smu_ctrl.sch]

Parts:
C33, C37: 22p; C_0805_2012Metric_Pad1.18x1.45mm_HandSolder
C34, C35, C36, C38, C40, C43, C48, C50, C51, C52, C56: 100n; C_0805_2012Metric_Pad1.18x1.45mm_HandSolder
C39, C49, C57: 1u; C_0805_2012Metric_Pad1.18x1.45mm_HandSolder
C41: 1u; C_Rect_L7.0mm_W3.5mm_P5.00mm
C42: 4u7; CP_EIA-3216-18_Kemet-A_Pad1.58x1.35mm_HandSolder
C44, C45, C46, C47, C53, C54, C55: 1n; C_0805_2012Metric_Pad1.18x1.45mm_HandSolder
D8, D9: LED; LED_0805_2012Metric_Pad1.15x1.40mm_HandSolder
FB1, FB2, FB3, FB4: Ferrite_Bead_Small; L_0805_2012Metric_Pad1.15x1.40mm_HandSolder
J6: Conn_02x03_Odd_Even; IDC-Header_2x03_P2.54mm_Vertical
J7: Conn_01x06_Male; PinHeader_1x06_P2.00mm_Vertical
R60: 10k1; R_0805_2012Metric_Pad1.20x1.40mm_HandSolder
R61, R62: 680R; R_0805_2012Metric_Pad1.20x1.40mm_HandSolder
R63, R64, R66, R68, R70, R71, R73, R74, R75, R76, R77, R78: 10k00; R_0805_2012Metric_Pad1.20x1.40mm_HandSolder
R65: 2R2; R_0805_2012Metric_Pad1.20x1.40mm_HandSolder
R67, R69, R81, R82: 21k50; R_0805_2012Metric_Pad1.20x1.40mm_HandSolder
R72: 1M6; R_0805_2012Metric_Pad1.20x1.40mm_HandSolder
R79: 2k2; R_0805_2012Metric_Pad1.20x1.40mm_HandSolder
R80: 20k50; R_0805_2012Metric_Pad1.20x1.40mm_HandSolder
R83: 2k00; R_0805_2012Metric_Pad1.20x1.40mm_HandSolder
U22: ISO7341C; SOIC-16W_7.5x10.3mm_P1.27mm
U23: ATmega8535-16JU; PLCC-44
U24: MAX6225; DIP-8_W7.62mm_Socket
U25: OPA2333; SOIC-8_3.9x4.9mm_P1.27mm
U26: LTC2057; SOIC-8_3.9x4.9mm_P1.27mm
U27: AD5686; TSSOP-16_4.4x5mm_P0.65mm
U28: OPA202; SOIC-8_3.9x4.9mm_P1.27mm
U29, U30: OP07; SOIC-8_3.9x4.9mm_P1.27mm
U31: CPC1018N; SO-4_4.4x3.9mm_P2.54mm
U32: ad7177; TSSOP-24_4.4x7.8mm_P0.65mm
Y1: Crystal; Crystal_HC49-4H_Vertical

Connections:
+5V: FB1.2, FB2.1, FB3.2, FB4.2, U25.8 (V+), U32.16 (IOVDD); also elsewhere on the board
+5VD: C34.1, C35.1, C38.1, C39.1, FB1.1, J6.2, J7.6, R60.2, R61.1, U22.1 (VCC1), U23.11 (VCC), U23.23 (VCC), U23.33 (AVCC), U23.35 (AREF), U23.44 (VCC)
+15V: C40.1, U24.2 (IN), U26.7 (V+), U28.7 (V+), U29.7 (V+), U30.7 (V+); also elsewhere on the board
-15V: U26.4 (V-), U28.4 (V-), U29.4 (V-), U30.4 (V-); also elsewhere on the board
/IM: R69.2; also elsewhere on the board
/VM: R67.2; also elsewhere on the board
/VREF+: C41.1, C50.1, R63.2, U24.6 (OUT), U27.1 (VREF), U32.3 (REF+); also elsewhere on the board
/smu_ctrl/CL+: C54.1, R81.2, U29.6; also elsewhere on the board
/smu_ctrl/CL-: C55.1, R82.2, U30.6; also elsewhere on the board
/smu_ctrl/CLAMP: U22.4 (INB), U23.28 (PC3); also elsewhere on the board
/smu_ctrl/COM_RX: U22.6 (OUTD), U23.15 (PD0)
/smu_ctrl/COM_TX: U22.5 (INC), U23.16 (PD1)
/smu_ctrl/CS_ADC: U23.38 (PA5), U32.14 (~CS)
/smu_ctrl/CS_DAC: U23.41 (PA2), U27.13 (~SYNC)
/smu_ctrl/FDACLO: R79.2, U23.36 (PA7)
/smu_ctrl/FDACN: C53.1, R80.2, U28.6, U31.4; also elsewhere on the board
/smu_ctrl/I1A: U23.43 (PA0); also elsewhere on the board
/smu_ctrl/I1MA: U23.4 (PB2); also elsewhere on the board
/smu_ctrl/I10MA: U23.3 (PB1); also elsewhere on the board
/smu_ctrl/I10UA: U23.6 (PB4); also elsewhere on the board
/smu_ctrl/I100MA: U23.42 (PA1); also elsewhere on the board
/smu_ctrl/I100UA: U23.5 (PB3); also elsewhere on the board
/smu_ctrl/IMODE: U23.29 (PC4); also elsewhere on the board
/smu_ctrl/I_CLAMP: U22.13 (OUTB); also elsewhere on the board
/smu_ctrl/I_GND: C36.2, U22.9 (GND2), U22.15 (GND2); also elsewhere on the board
/smu_ctrl/I_RX: U22.12 (OUTC); also elsewhere on the board
/smu_ctrl/I_TX: U22.11 (IND); also elsewhere on the board
/smu_ctrl/I_VCC: C36.1, U22.16 (VCC2); also elsewhere on the board
/smu_ctrl/LED: R62.1, U23.31 (PC6)
/smu_ctrl/MISO: U23.40 (PA3), U27.8 (SDO), U32.11 (DOUT/~RDY)
/smu_ctrl/MOSI: U23.39 (PA4), U27.14 (SDIN), U32.12 (DIN)
/smu_ctrl/OUT_ON: U23.26 (PC1); also elsewhere on the board
/smu_ctrl/PA_CTRL_A: U23.17 (PD2); also elsewhere on the board
/smu_ctrl/PA_CTRL_B: U23.18 (PD3); also elsewhere on the board
/smu_ctrl/P_MISO: J6.1, U23.8 (PB6)
/smu_ctrl/P_MOSI: J6.4, U23.7 (PB5)
/smu_ctrl/P_RST: J6.5, R60.1, U23.10 (~RESET)
/smu_ctrl/P_SCK: J6.3, U23.9 (PB7)
/smu_ctrl/REMOTE: U23.27 (PC2); also elsewhere on the board
/smu_ctrl/SCK: U23.37 (PA6), U27.12 (SCLK), U32.13 (SCLK)
/smu_ctrl/VLDAC: C43.1, FB2.2, U27.5 (VDD), U27.10 (GAIN), U27.11 (VLOGIC), U27.15 (~RESET), U27.16 (RSTSEL)
/smu_ctrl/VMODE: U23.30 (PC5); also elsewhere on the board
/smu_ctrl/VRANGEL: U23.32 (PC7); also elsewhere on the board
/smu_ctrl/VREF-: C42.2, R64.2, R66.2, R68.2, R74.2, R76.2, R78.2, U26.6
/smu_ivmeas/LA10MA: U23.2 (PB0); also elsewhere on the board
GND: C33.2, C34.2, C35.2, C37.2, C38.2, C39.2, C40.2, C41.2, C43.2, C44.2, C47.2, C48.2, C49.2, C50.2, C51.2, C52.2, C56.2, C57.2, D8.1 (K), D9.1 (K), J6.6, J7.5, R65.1, U22.2 (GND1), U22.8 (GND1), U23.1 (GND), U23.12 (GND), U23.24 (GND), U23.34 (AGND), U24.4 (GND), U25.3 (+), U25.4 (V-), U25.5 (+), U26.3 (+), U27.4 (GND), U27.9 (~LDAC), U28.3 (+), U29.3 (+), U30.3 (+), U31.2, U32.2 (REF-), U32.6 (AVSS), U32.17 (DGND), U32.22 (AIN1), U32.24 (AIN3); also elsewhere on the board
unnamed: C33.1, U23.14 (XTAL1), Y1.1
unnamed: C37.1, U23.13 (XTAL2), Y1.2
unnamed: C42.1, R65.2
unnamed: C44.1, C45.1, R70.2, U25.1, U32.21 (AIN0)
unnamed: C45.2, R66.1, R67.1, R70.1, U25.2 (-)
unnamed: C46.1, C47.1, R71.2, U25.7, U32.23 (AIN2)
unnamed: C46.2, R68.1, R69.1, R71.1, U25.6 (-)
unnamed: C48.1, C49.1, U32.5 (REGCAPA)
unnamed: C51.1, FB4.1, U32.7 (AVDD1)
unnamed: C52.1, FB3.1, U32.8 (AVDD2)
unnamed: C53.2, R72.1, R73.1, R74.1, R80.1, R83.1, U28.2 (-)
unnamed: C54.2, R75.1, R76.1, R81.1, U29.2 (-)
unnamed: C55.2, R77.1, R78.1, R82.1, U30.2 (-)
unnamed: C56.1, C57.1, U32.18 (REGCAPD)
unnamed: D8.2 (A), R61.2
unnamed: D9.2 (A), R62.2
unnamed: J7.1, U23.22 (PD7)
unnamed: J7.2, U23.21 (PD6)
unnamed: J7.3, U23.20 (PD5)
unnamed: J7.4, U23.19 (PD4)
unnamed: R63.1, R64.1, U26.2 (-)
unnamed: R72.2, U27.2 (VOUTB)
unnamed: R73.2, U27.7 (VOUTD)
unnamed: R75.2, U27.6 (VOUTC)
unnamed: R77.2, U27.3 (VOUTA)
unnamed: R79.1, U31.1
unnamed: R83.2, U31.3

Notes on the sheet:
Optical isolation
Floating MCU
Floating MCU programming header
Reference, ADC, measurement signal conditioning
DAC, main drive and clamp signals conditioning



Board: 2 copper layers, 130.0 x 80.0 mm, 210 parts (13 on the bottom side), 141 nets.

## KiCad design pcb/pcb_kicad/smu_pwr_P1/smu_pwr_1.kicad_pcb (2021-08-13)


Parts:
C1, C2: 1u; C_Rect_L16.5mm_W7.0mm_P15.00mm_MKT
C3, C4: 390u; CP_Radial_D18.0mm_P7.50mm
C5, C6, C7, C8: 470u; CP_Radial_D13.0mm_P5.00mm
C9, C10: 22u; CP_Radial_D6.3mm_P2.50mm
D1, D2, D3, D4, D5, D6, D7, D8, D9, D10, D11, D12: 1N4007; D_DO-41_SOD81_P10.16mm_Horizontal
D13, D14: 15V; D_DO-41_SOD81_P10.16mm_Horizontal
H1, H2, H3, H4: MountingHole; MountingHole_3.2mm_M3_ISO7380_Pad
J1: Conn_01x05_Male; Molex_KK-396_A-41791-0005_1x05_P3.96mm_Vertical
J2, J3, J5: Conn_01x03_Male; Molex_KK-396_A-41791-0003_1x03_P3.96mm_Vertical
J4: Conn_01x03_Male; Molex_KK-254_AE-6410-03A_1x03_P2.54mm_Vertical
K1: Fujitsu_FTR-F1C; Relay_DPDT_Fujitsu_FTR-F1C
R1, R2: 33R; R_Axial_DIN0309_L9.0mm_D3.2mm_P15.24mm_Horizontal
R3, R5: 22k; R_Axial_DIN0411_L9.9mm_D3.6mm_P15.24mm_Horizontal
R4, R6: 10k; R_Axial_DIN0309_L9.0mm_D3.2mm_P15.24mm_Horizontal
U1: L7815; TO-220-3_Vertical
U2: L7915; TO-220-3_Vertical

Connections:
/15VO+: C7.1, D11.1 (K), D13.1 (K), J2.1, R4.2
/15VO-: C8.2, D12.1 (K), D14.2 (A), J2.3, R6.1
/+15V: C9.1, J4.1, U1.3 (OUT)
/-15V: C10.2, J4.3, U2.3 (VO)
/GND: C5.2, C6.1, C9.2, C10.1, J4.2, J5.2, K1.4, U1.2 (GND), U2.1 (GND)
/HV+: C3.1, D1.1 (K), D2.1 (K), J3.3, K1.2
/HV-: C4.2, D3.2 (A), D4.2 (A), J3.1, K1.7
/HVG: C3.2, C4.1, C7.2, C8.1, D9.2 (A), D10.1 (K), D13.2 (A), D14.1 (K), J1.3, J2.2, R3.1, R4.1, R5.1, R6.2
unnamed: C1.1, R1.2
unnamed: C1.2, D1.2 (A), D3.1 (K), J1.1
unnamed: C2.1, R2.2
unnamed: C2.2, D2.2 (A), D4.1 (K), J1.5
unnamed: C5.1, D5.1 (K), D6.1 (K), U1.1 (IN)
unnamed: C6.2, D7.2 (A), D8.2 (A), K1.5, U2.2 (VI)
unnamed: D5.2 (A), D7.1 (K), J5.3
unnamed: D6.2 (A), D8.1 (K), J5.1
unnamed: D10.2 (A), D12.2 (A), R2.1
unnamed: D9.1 (K), D11.2 (A), R1.1
unnamed: K1.3, R3.2
unnamed: K1.6, R5.2

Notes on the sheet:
Power amp high voltage supply, voltage sense floating supply
Main analog power supply, high voltage discharge relay
Mounting holes
JSMU - power board P1


Board: 2 copper layers, 100.0 x 82.0 mm, 42 parts (0 on the bottom side), 20 nets.

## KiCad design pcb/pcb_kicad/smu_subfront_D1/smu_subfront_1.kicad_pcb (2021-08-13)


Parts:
C1, C11: 10u; C_0805_2012Metric_Pad1.18x1.45mm_HandSolder
C2: CP; C_Radial_D8.0mm_H11.5mm_P3.50mm
C3, C4, C5, C10, C14, C15: 100n; C_0805_2012Metric_Pad1.18x1.45mm_HandSolder
C6, C8: 47u; CP_EIA-6032-28_Kemet-C_Pad2.25x2.35mm_HandSolder
C7, C9: 10n; C_0805_2012Metric_Pad1.18x1.45mm_HandSolder
C12, C13: 22p; C_0805_2012Metric_Pad1.18x1.45mm_HandSolder
D1, D2, D3, D4, D6: SM4007; D_MELF
D5, D8: D_Zener; D_MiniMELF
D7: B340; D_SMB_Handsoldering
D9, D10, D11: LED; LED_0805_2012Metric_Pad1.15x1.40mm_HandSolder
H1, H2, H3, H4: MountingHole; MountingHole_3.2mm_M3_Pad
J1, J5: Conn_01x05_Male; Molex_KK-254_AE-6410-05A_1x05_P2.54mm_Vertical
J2: Conn_01x04_Male; PinHeader_1x04_P2.54mm_Vertical
J3: Conn_01x02_Male; Molex_KK-396_A-41791-0002_1x02_P3.96mm_Vertical
J4: Conn_02x08_Odd_Even; PinHeader_2x08_P2.54mm_Vertical
J6, J7: Conn_01x02_Male; PinHeader_1x02_P2.54mm_Horizontal
J8: Conn_01x05_Male; PinHeader_1x05_P2.54mm_Horizontal
L1: L; L_Bourns_SRP7028A_7.3x6.6mm
Q1, Q2: BC817; SOT-23
R1, R2, R5, R6: 2k2; R_0805_2012Metric_Pad1.20x1.40mm_HandSolder
R3, R7, R10: 10k; R_0805_2012Metric_Pad1.20x1.40mm_HandSolder
R4: 5k6; R_0805_2012Metric_Pad1.20x1.40mm_HandSolder
R8: 1M; R_0805_2012Metric_Pad1.20x1.40mm_HandSolder
R9: 1k; R_0805_2012Metric_Pad1.20x1.40mm_HandSolder
R11, R12, R13: 510R; R_0805_2012Metric_Pad1.20x1.40mm_HandSolder
TP1, TP2, TP3, TP4, TP5, TP6: TestPoint; TestPoint_Pad_2.0x2.0mm
U1: L7808; TO-263-3_TabPin2
U2: TPS5420D; SOIC-8_3.9x4.9mm_P1.27mm
U3: PIC24FJxxGA006; LQFP-64_10x10mm_P0.5mm
U4: 25LCxxx; SOIC-8_3.9x4.9mm_P1.27mm
U5: MC9S08GB60A; LQFP-64_10x10mm_P0.5mm
Y1: Crystal; Crystal_HC49-4H_Vertical

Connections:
+3V3: C3.2, C4.2, C5.2, C8.1, C10.2, C14.2, C15.2, D11.2 (A), J1.2, J4.16, J5.2, J8.2, L1.2, R3.1, R5.2, R7.1, R10.1, U3.10 (VDD), U3.19 (AVDD), U3.26 (VDD), U3.38 (VDD), U3.57 (ENVREG), U4.3 (~WP), U4.7 (~HOLD), U4.8 (VCC), U5.24 (Vdd), U5.41 (VREFH), U5.56 (VDDAD)
+24V: C1.2, C2.1, D1.1 (K), D2.1 (K), J2.3, J2.4, U1.1 (IN), U2.7 (VIN)
/ATN1: J1.5, U3.30 (PMA0/AN15/OCFB/CN12/RB15), U5.13 (PTF4)
/ATN2: J5.5, U3.35 (U1RTS/BCLK1/SCK1/INT0/RF6), U5.2 (PTG7)
/D_A0: J4.9, U3.16 (PGD1/EMUD1/PMA6/VREF+/AN0/CN2/RB0), U5.30 (PTD5/TPM2CH2)
/D_A1: J4.11, U3.27 (TCK/PMA11/AN12/RB12), U5.31 (PTD6/TPM2CH3)
/D_A2: J4.13, U3.28 (TDI/PMA10/AN13/RB13), U5.32 (PTD7/TPM2CH4)
/D_CLK: J4.7, U3.24 (TDO/PMA12/AN11/RB11), U5.29 (PTD4/TPM2CH1)
/D_DI: J4.1, U3.21 (U2CTS/C1OUT/AN8/RB8), U5.26 (PTD1/TPM1CH1)
/D_LE: J4.3, U3.22 (PMA7/C2OUT/AN9/RB9), U5.27 (PTD2/TPM1CH2)
/D_OE: J4.5, U3.23 (TMS/PMA13/CVREF/AN10/RB10), U5.28 (PTD3/TPM2CH0)
/EE_CS: R7.2, U3.47 (SOSCI/CN1/RC13), U4.1 (~CS), U5.36 (PTB3/AD1P3)
/EE_MISO: U3.46 (OC1/RD0), U4.2 (MISO), U5.35 (PTB2/AD1P2)
/EE_MOSI: U3.45 (IC4/PMCS1/INT4/RD11), U4.5 (MOSI), U5.34 (PTB1/AD1P1)
/EE_SCK: U3.44 (IC3/PMCS2/INT3/RD10), U4.6 (SCK), U5.33 (PTB0/AD1P0)
/ENC_A: J4.10, U3.15 (PGC1/EMUC1/VREF-/AN1/CN3/RB1), U5.46 (PTA0/KBI1P0)
/ENC_B: J4.12, U3.14 (C2IN-/AN2/SS1/CN4/RB2), U5.47 (PTA1/KBI1P1)
/E_CS: J4.2, U3.3 (PMD7/RE7), U5.17 (PTE2/SS1)
/E_SCK: J4.4, U3.11 (C1IN+/AN5/CN7/RB5), U5.20 (PTE5/SPSCK1)
/E_SI: J4.6, U3.12 (C1IN-/AN4/CN6/RB4), U5.19 (PTE4/MOSI1)
/E_SO: J4.8, U3.13 (C2IN+/AN3/CN5/RB3), U5.18 (PTE3/MISO1)
/FAN_ON: R2.2, U3.42 (IC1/RTCC/INT1/RD8), U5.51 (PTA5/KBI1P5)
/FAN_SPEED: R1.2, U3.43 (IC2/U1CTS/INT2/RD9), U5.52 (PTA6/KBI1P6)
/LED1: D10.2 (A), U3.2 (PMD6/RE6), U5.10 (PTC7)
/LED2: D9.2 (A), U3.1 (PMD5/RE5), U5.9 (PTC6)
/PG1: J8.5, U3.18 (PGD2/EMUD2/AN7/RB7)
/PG2: J8.3, U3.17 (PGC2/EMUC2/AN6/OCFA/RB6), U5.58 (PTG0/BKGD/MS)
/RST: J8.4, R10.2, U3.7 (MCLR), U5.1 (RESET)
/RX1: J1.3, U3.34 (U1RX/SDI1/RF2), U5.15 (PTE1/RxD1)
/RX2: J5.3, U3.31 (PMA9/U2RX/SDA2/CN17/RF4), U5.4 (PTC1/RxD2)
/SCL: U5.6 (PTC3/SCL1)
/SDA: U5.5 (PTC2/SDA1)
/TH_ADC: C9.2, R6.2, U3.29 (PMA1/U2RTS/BCLK2/AN14/RB14), U5.40 (PTB7/AD1P7)
/TX1: J1.4, U3.33 (U1TX/SDO1/RF3), U5.14 (PTE0/TxD1)
/TX2: J5.4, U3.32 (PMA8/U2TX/SCL2/CN18/RF5), U5.3 (PTC0/TxD2)
/X1: C12.2, R8.1, R9.2, U3.39 (OSC1/CLKI/RC12), Y1.1
/X2: C13.2, R8.2, U3.40 (OSC2/CLKO/RC15), U5.59 (PTG1/XTAL), Y1.2
GND: C1.1, C2.2, C3.1, C4.1, C5.1, C6.2, C8.2, C9.1, C10.1, C11.1, C12.1, C13.1, C14.1, C15.1, D3.2 (A), D4.2 (A), D5.2 (A), D7.2 (A), D8.2 (A), J1.1, J2.1, J2.2, J4.15, J5.1, J7.1, J8.1, Q1.2 (E), Q2.2 (E), R4.2, R11.1, R12.1, R13.1, U2.6 (GND), U3.9 (VSS), U3.20 (AVSS), U3.25 (VSS), U3.41 (Vss), U4.4 (GND), U5.23 (Vss), U5.42 (VREFL), U5.57 (VSSAD)
unnamed: C6.1, D6.1 (K), J6.1, U1.3 (OUT)
unnamed: C7.1, D7.1 (K), L1.1, U2.8 (PH)
unnamed: C7.2, U2.1 (BOOT)
unnamed: C11.2, U3.56 (VCAP/VDDCORE)
unnamed: D1.2 (A), D3.1 (K), J3.2
unnamed: D2.2 (A), D4.1 (K), J3.1
unnamed: D5.1 (K), Q1.3 (C), U1.2 (GND)
unnamed: D6.2 (A), J6.2, Q2.3 (C)
unnamed: D8.1 (K), J7.2, R5.1, R6.1
unnamed: D9.1 (K), R11.2
unnamed: D10.1 (K), R12.2
unnamed: D11.1 (K), R13.2
unnamed: Q1.1 (B), R1.1
unnamed: Q2.1 (B), R2.1
unnamed: R3.2, R4.1, U2.4 (VSNS)
unnamed: R9.1, U5.60 (PTG2/EXTAL)
unnamed: TP1.1, U3.60 (PMD0/RE0)
unnamed: TP2.1, U3.61 (PMD1/RE1)
unnamed: TP3.1, U3.62 (PMD2/RE2)
unnamed: TP4.1, U5.48 (PTA2/KBI1P2)
unnamed: TP5.1, U5.49 (PTA3/KBI1P3)
unnamed: TP6.1, U5.50 (PTA4/KBI1P4)

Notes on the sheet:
Main MCU block. Populate only one MCU footprint
IO connector
RTD connector, signal conditioning
Serial connectors
Fan speed control
24V supply, 3V3 supply
Mounting holes
JSMU - digital board D1



Board: 2 copper layers, 137.0 x 62.0 mm, 66 parts (5 on the bottom side), 58 nets.

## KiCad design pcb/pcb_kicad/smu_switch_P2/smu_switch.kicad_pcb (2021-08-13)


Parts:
F1: Fuse; Fuseholder_Cylinder-5x20mm_Schurter_0031_8201_Horizontal_Op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
H1, H2, H3, H4: MountingHole; MountingHole_3.2mm_M3_ISO7380_Pad
J1, J2: Conn_01x05_Male; Molex_KK-396_A-41791-0005_1x05_P3.96mm_Vertical
SW1: SW_DPST; NE18-2P

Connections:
unnamed: F1.1, J2.1
unnamed: F1.2, SW1.2
unnamed: J1.1, SW1.1
unnamed: J1.3, SW1.3
unnamed: J1.5, J2.5
unnamed: J2.3, SW1.4

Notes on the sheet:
JSMU - switch board P2


Board: 2 copper layers, 38.0 x 113.0 mm, 8 parts (0 on the bottom side), 6 nets.

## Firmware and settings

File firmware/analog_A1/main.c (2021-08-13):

#define F_CPU 7372800UL

#define USART_BAUDRATE 19200
#define BAUD_PRESCALE (((F_CPU / (USART_BAUDRATE * 16UL))) - 1)

#include <avr/io.h>
#include <util/delay.h>
#include<avr/interrupt.h>
#include <stdlib.h>
#include <string.h>
#define BIT_SET(a,b) ((a) |= (1ULL<<(b)))
#define BIT_CLEAR(a,b) ((a) &= ~(1ULL<<(b)))
#define BIT_FLIP(a,b) ((a) ^= (1ULL<<(b)))
#define BIT_CHECK(a,b) (!!((a) & (1ULL<<(b))))		// '!!' to make sure this returns 0 or 1

#define	 I1A_H		BIT_SET(PORTA,0)
#define	 I1A_L		BIT_CLEAR(PORTA,0)
#define	 I100MA_H	BIT_SET(PORTA,1)
#define	 I100MA_L	BIT_CLEAR(PORTA,1)
#define	 CSDAC_H	BIT_SET(PORTA,2)
#define	 CSDAC_L	BIT_CLEAR(PORTA,2)
#define	 MISO_V		BIT_CHECK(PINA,3)
#define	 MOSI_H		BIT_SET(PORTA,4)
#define	 MOSI_L		BIT_CLEAR(PORTA,4)
#define	 CSADC_H	BIT_SET(PORTA,5)
#define	 CSADC_L	BIT_CLEAR(PORTA,5)
#define	 SCK_H		BIT_SET(PORTA,6)
#define	 SCK_L		BIT_CLEAR(PORTA,6)
#define	 FDACLO_H	BIT_SET(PORTA,7)
#define	 FDACLO_L	BIT_CLEAR(PORTA,7)

#define	 LT10MA_H	BIT_SET(PORTB,0)
#define	 LT10MA_L	BIT_CLEAR(PORTB,0)
#define	 I10MA_H	BIT_SET(PORTB,1)
#define	 I10MA_L	BIT_CLEAR(PORTB,1)
#define	 I1MA_H		BIT_SET(PORTB,2)
#define	 I1MA_L		BIT_CLEAR(PORTB,2)
#define	 I100UA_H	BIT_SET(PORTB,3)
#define	 I100UA_L	BIT_CLEAR(PORTB,3)
#define	 I10UA_H	BIT_SET(PORTB,4)
#define	 I10UA_L	BIT_CLEAR(PORTB,4)

#define	 OUT_ON_H	BIT_SET(PORTC,1)
#define	 OUT_ON_L	BIT_CLEAR(PORTC,1)
#define	 REMOTE_H	BIT_SET(PORTC,2)
#define	 REMOTE_L	BIT_CLEAR(PORTC,2)
#define	 CLAMP_V	BIT_CHECK(PINC,3)
#define	 IMODE_H	BIT_SET(PORTC,4)
#define	 IMODE_L	BIT_CLEAR(PORTC,4)
#define	 VMODE_H	BIT_SET(PORTC,5)
#define	 VMODE_L	BIT_CLEAR(PORTC,5)
#define	 LED_H		BIT_SET(PORTC,6)
#define	 LED_L		BIT_CLEAR(PORTC,6)
#define	 VRANGEL_H	BIT_SET(PORTC,7)
#define	 VRANGEL_L	BIT_CLEAR(PORTC,7)

#define	 PA_CTRL_A_H	BIT_SET(PORTD,2)
#define	 PA_CTRL_A_L	BIT_CLEAR(PORTD,2)
#define	 PA_CTRL_B_H	BIT_SET(PORTD,3)
#define	 PA_CTRL_B_L	BIT_CLEAR(PORTD,3)


volatile unsigned char rcvd_ptr,rcvd_flag,rcvd_str[20];
char cmd_buf[20];
unsigned char cmd_valid;
uint8_t mode,dac_update,dac_enabled,clamp_state;
uint16_t x;
uint32_t y;
uint32_t adc_res[3];
uint16_t dac_val[4];
char tx_str[30];
uint16_t out;
int range_i,range_v;



// timer0 overflow
ISR(TIMER0_OVF_vect) 
	{
	TCNT0=220;
	}

ISR (TIMER1_OVF_vect)	// Timer1 ISR
	{
	TCNT1 = 65488;
	}

ISR(UART_RX_vect)
	{
	char temp;
	temp = UDR; // Fetch the received byte value into the variable "ByteReceived"
	if (temp<0x20)
		{
		if (rcvd_ptr>0)
			{
			rcvd_str[rcvd_ptr] = 0;
			rcvd_flag = 1;
			rcvd_ptr = 0;
			}
		}
	else
		{	
		rcvd_str[rcvd_ptr++] = temp;
		}
	if (rcvd_ptr==sizeof(rcvd_str)) rcvd_ptr = 0;
	}


void uart_tx (uint8_t data)
	{
	while ((USR & (1 << UDRE)) == 0) {};
	UDR = data;
	}

void uart_txs (char * data)
	{
	while (*data) uart_tx(*data++);
	}

uint8_t uart_rx_rdy (void)
	{
	if (USR & (1 << RXC))
		return 1;
	else 
		return 0;
	}

uint8_t uart_rx_read (void)
	{
	return UDR;
	}

uint8_t spi_trf (uint8_t data)
	{
	uint8_t i,retval=0;
	for (i=0;i<8;i++)
		{
		if (data&0x80)
			{
			MOSI_H;
			}
		else
			{
			MOSI_L;
			}
		_delay_us(3);
		SCK_L;
		retval = retval << 1;
		data = data << 1;
		SCK_H;
		if (MISO_V) 
			{
			retval = retval | 0x01;
			}
		}
	return retval;
	}

void adc_write_8(uint8_t addr, uint8_t data)
	{
	CSADC_L;
	spi_trf(addr&0x3F);
	spi_trf(data);
	CSADC_H;
	}

void adc_write_16(uint8_t addr, uint16_t data)
	{
	CSADC_L;
	spi_trf(addr&0x3F);
	spi_trf((data>>8)&0xFF);
	spi_trf((data>>0)&0xFF);
	CSADC_H;
	}

void adc_write_24(uint8_t addr, uint32_t data)
	{
	CSADC_L;
	spi_trf(addr&0x3F);
	spi_trf((data>>16)&0xFF);
	spi_trf((data>>8)&0xFF);
	spi_trf((data>>0)&0xFF);
	CSADC_H;
	}

uint8_t adc_read_8(uint8_t addr)
	{
	uint8_t r1;
	CSADC_L;
	spi_trf(0x40|(addr&0x3F));
	r1 = spi_trf(0);
	CSADC_H;
	return r1;
	}

uint16_t adc_read_16(uint8_t addr)
	{
	uint8_t r1,r2;
	uint16_t retval=0;
	CSADC_L;
	spi_trf(0x40|(addr&0x3F));
	r1 = spi_trf(0);
	r2 = spi_trf(0);
	CSADC_H;
	retval = (((uint16_t)(r1))<<8)|(((uint16_t)(r2))<<0);
	return retval;
	}

uint32_t adc_read_24(uint8_t addr)
	{
	uint8_t r1,r2,r3;
	uint32_t retval=0;
	CSADC_L;
	spi_trf(0x40|(addr&0x3F));
	r1 = spi_trf(0);
	r2 = spi_trf(0);
	r3 = spi_trf(0);
	CSADC_H;
	retval = (((uint32_t)(r1))<<16)|(((uint32_t)(r2))<<8)|(((uint32_t)(r3))<<0);
	return retval;
	}

uint32_t adc_read_32(uint8_t addr)
	{
	uint8_t r1,r2,r3,r4;
	uint32_t retval=0;
	CSADC_L;
	spi_trf(0x40|(addr&0x3F));
	r1 = spi_trf(0);
	r2 = spi_trf(0);
	r3 = spi_trf(0);
	r4 = spi_trf(0);
	CSADC_H;
	retval = (((uint32_t)(r1))<<24)|(((uint32_t)(r2))<<16)|(((uint32_t)(r3))<<8)|(((uint32_t)(r4))<<0);
	return retval;
	}

uint32_t adc_ss (void)
	{
	uint8_t r1,r2,r3;
	uint32_t retval=0;
	CSADC_L;
	spi_trf(0x01);
	spi_trf(0x80);
	spi_trf(0x10);
	while (MISO_V!=0);
	spi_trf(0x44);
	r1 = spi_trf(0);
	r2 = spi_trf(0);
	r3 = spi_trf(0);
	CSADC_H;
	retval = (((uint32_t)(r1))<<16)|(((uint32_t)(r2))<<8)|(((uint32_t)(r3))<<0);
	return retval;
	}

void dac_write(uint8_t addr, uint16_t data)
	{
	CSDAC_L;
	spi_trf(addr);
	spi_trf((data>>8)&0xFF);
	spi_trf((data>>0)&0xFF);
	CSDAC_H;
	}
	
void tx_var_16(uint16_t data, uint8_t eol)
	{
	char tx_out[10];
	itoa(data,tx_out,10);
	uart_txs(tx_out);
	if (eol) uart_txs("\n");		
	}
void tx_var_32(uint32_t data, uint8_t eol)
	{
	char tx_out[10];
	ltoa(data,tx_out,10);
	uart_txs(tx_out);
	if (eol) uart_txs("\n");		
	}
	
	/*
	ziadny - 0.3mA
	iba 2 - 3,3mA
	iba 1 - 31mA
	oba  - max
	* 
	* a = 2
	* b = 1
	* PA_CTRL_A_H
	*/
	
void set_pa_ctrl (uint8_t range)	
	{
	PA_CTRL_A_L;
	PA_CTRL_B_L;
	if (range==1) 
		{
		PA_CTRL_A_H;
		PA_CTRL_B_L;
		}
	if (range==2) 
		{
		PA_CTRL_A_L;
		PA_CTRL_B_H;
		}
	if (range==3) 
		{
		PA_CTRL_A_H;
		PA_CTRL_B_H;
		}
	}
	
	
void set_current_shunt (uint8_t range)
	{
	set_pa_ctrl(1);
	I1A_H;
	I100MA_H;
	LT10MA_H;
	I10MA_H;
	I1MA_H;
	I100UA_H;
	I10UA_H;
	if (range==0) {}
	if (range==1) (I10UA_L);
	if (range==2) (I100UA_L);
	if (range==3) (I1MA_L);
	if (range==4) (I10MA_L);
	if (range==5) (I100MA_L);
	if (range==6) (I1A_L);
	if (range<5) (LT10MA_L);

	if (range==4) set_pa_ctrl(2);
	if (range==5) set_pa_ctrl(3);
	}
	
	
void serial_tasks (void)
	{
	BIT_CLEAR(UCR,RXCIE);
	if (rcvd_flag == 1)
		{
		rcvd_flag = 0;
		cmd_valid = 1;
		strcpy((char *)cmd_buf,(char *)rcvd_str);
		}
	BIT_SET(UCR,RXCIE);
	if (cmd_valid == 1)
		{
		strcpy(tx_str,"?");
		cmd_valid = 0;
		if (cmd_buf[0]=='m')
			{
			if (cmd_buf[1]=='v')
				{
				mode = 0;
				VMODE_L;
				IMODE_H;
				}
			if (cmd_buf[1]=='i')
				{
				mode = 1;
				VMODE_H;
				IMODE_L;
				}
			strcpy(tx_str,"OK");
			}
		if (cmd_buf[0]=='r')
			{
			if (cmd_buf[1]=='i')
				{
				range_i = atoi(cmd_buf+2);
				set_current_shunt(range_i);
				}
			if (cmd_buf[1]=='v')
				{
				range_v = atoi(cmd_buf+2);
				//set voltage range
				}
				strcpy(tx_str,"OK");
			}
		if (cmd_buf[0]=='d')
			{
			if (cmd_buf[1]=='a')
				{
				dac_val[0] = atoi(cmd_buf+2);
				dac_update = 1;
				strcpy(tx_str,"OK");
				}
			if (cmd_buf[1]=='b')
				{
				dac_val[1] = atoi(cmd_buf+2);
				dac_update = 1;
				strcpy(tx_str,"OK");
				}
			if (cmd_buf[1]=='c')
				{
				dac_val[2] = atoi(cmd_buf+2);
				dac_update = 1;
				strcpy(tx_str,"OK");
				}
			}
		if (cmd_buf[0]=='a')
			{
			strcpy(tx_str,"OK ");
			uart_txs(tx_str);
			tx_var_32(adc_res[0],0);
			uart_txs(" ");
			tx_var_32(adc_res[1],0);
			uart_txs(" ");
			tx_var_16(clamp_state,0);
			strcpy(tx_str," ");
			}
		if (cmd_buf[0]=='g')
			{
			tx_var_16(range_i,1);
			tx_var_16(range_v,1);
			tx_var_16(mode,1);
			tx_var_32(adc_res[0],1);
			tx_var_32(adc_res[1],1);
			tx_var_16(dac_val[0],1);
			tx_var_16(dac_val[1],1);
			tx_var_16(dac_val[2],1);
			strcpy(tx_str,"OK");
			}
		if (cmd_buf[0]=='r')
			{
			if (cmd_buf[1]=='o')
				{
				if (cmd_buf[2]=='1') OUT_ON_H;
				else OUT_ON_L;
				}
			if (cmd_buf[1]=='r')
				{
				if (cmd_buf[2]=='1') REMOTE_H;
				else REMOTE_L;
				}
			strcpy(tx_str,"OK");
			}
		if (cmd_buf[0]=='s')
			{
			if (cmd_buf[1]=='a')
				{
				if (cmd_buf[2]=='1') VRANGEL_H;
				else VRANGEL_L;
				}
			if (cmd_buf[1]=='b')
				{
				if (cmd_buf[2]=='1') FDACLO_H;
				else FDACLO_L;
				}
			strcpy(tx_str,"OK");
			}
		uart_txs(tx_str);
		uart_txs("\n");
		}
	}
void adc_tasks	(void)
	{
	uint8_t adc_status;
	adc_status = adc_read_8(0x00);
	if ((adc_status&0x80)==0) adc_res[adc_status&0x01] = adc_read_24(0x04);
	}

void dac_tasks (void)	
	{
	if (dac_update==1)
		{
		dac_write(0x38,dac_val[0]);	//FDACN - CHANNEL D
		dac_write(0x34,dac_val[1]);	//CL+ - CHANNEL C
		dac_write(0x31,dac_val[2]); //CL- - CHANNEL A
		dac_update = 0;
		}
	}

void io_tasks (void)
	{
	clamp_state = CLAMP_V;
	}

int main (void)
{
//	uint8_t i;
	DDRA = 0xF7; 
	DDRB = 0xFF; 
	DDRC = 0xF7; 
	DDRD = 0xFC; 
   	UCR = (1 << RXEN) | (1 << TXEN);   	// Turn on the transmission and reception circuitry
	UCR	 |= (1 << RXCIE);
   	UBRR = BAUD_PRESCALE; 				// Load lower 8-bits of the baud rate value into the low byte of the UBRR register
	TCNT1 = 63974;
	TCCR1A = 0x00;
	TCCR1B = (1<<CS10) | (1<<CS11);
	TCNT0=0x00;
	TCCR0 = (1<<CS02) | (1<<CS00);
	TIMSK=(1<<TOIE0) | (1<<TOIE1);
	sei();
	VMODE_H;
	IMODE_H;	
	CSADC_H;
	CSDAC_H;
	SCK_H;
	_delay_ms(200);
	dac_write(0x70,0x0000);
	dac_write(0x4F,0x0000);
	_delay_us(50);
	dac_write(0x60,0x0001);
	_delay_us(50);
	adc_write_16(0x10,0x8000 | (0x00<<5) | (0x15<<0));
	adc_write_16(0x11,0x8000 | (0x02<<5) | (0x15<<0));
//	adc_write_16(0x12,0x8000 | (0x15<<5) | (0x16<<0));
//	adc_write_16(0x13,0x8000 | (0x13<<5) | (0x14<<0));
	adc_write_16(0x20,0x1300);
	adc_write_16(0x28,0x0514);
	dac_val[0] = 32767;
	dac_val[1] = 32767;
	dac_val[2] = 32767;

	while (1)
		{
		serial_tasks();
		adc_tasks();
		dac_tasks();
		io_tasks();
		}

	while(1) 
		{
		//dac_write(0x3F,out);
		out = out + 0x1000;
		uart_txs("S");
		x = adc_read_8(0x00);
		itoa(x,tx_str,16);
		uart_txs(tx_str);
		uart_txs(" ");		
		if ((x&0x80)==0)
			{
			y = adc_read_24(0x04);
			ltoa(y,tx_str,16);
			uart_txs(tx_str);
			}
		uart_txs("\r\n");
   		BIT_SET(PORTC,6);
		_delay_ms(5);
   		BIT_CLEAR(PORTC,6);
		_delay_ms(100);
		}
}

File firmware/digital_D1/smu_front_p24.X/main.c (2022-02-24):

#include <xc.h>
#include <stdio.h>
#include <string.h>
#include <stdlib.h>
#include "hw.h"
#include "func.h"
#include "scpi/scpi.h"

//I'm not proud of this amount of global variables, also I'm not fan of useless interfaces for sake of interfacing
//it works for now, will be reworked once it gets too much
volatile uint16_t d_pixelmap[DISPLAY_LEN],d_blink_cnt,blink_mask,led_state_int;
volatile uint8_t d_blink,d_blink_mask_cnt,d_blink_mask_cnt2,display_compliance;
volatile uint8_t keymap[3],rx1_rcvd_ptr,rx1_rcvd_flag,rx2_rcvd_ptr,rx2_rcvd_flag;
volatile char rx1_rcvd_str[UART_RX_BUF_LEN], rx2_rcvd_str[UART_RX_BUF_LEN],disp_msg[DISPLAY_LEN+12];
volatile int16_t enc_var;
extern const uint16_t ASCII[96];
extern const char cal_val_desc[CAL_CONST_NUM][30];

uint8_t out_state=0,out_update=0,out_mode=0,range_curr=0,range_volt=1,edit_ptr=5,sup_force=0,sup_meas=1,sense_remote=0;
uint8_t disp_state,menu_ptr,avg_enabled,sup_enabled,sup_sample_now,rb_adc_arr_len=1,remote_mode=0,cal_locked=1;
uint8_t rmt_out_mode,rmt_src_volt_autorange,rmt_src_curr_autorange;
int16_t temper_hs;
int32_t set_volt,set_curr,clamp_volt,clamp_curr,meas_volt, meas_cur,rb_adc_val_1, rb_adc_val_2;
cal_type cal_const;
key_var keys,keys_new,keys_old;
led_var led_state;
float rmt_set_volt,rmt_set_curr,rmt_set_cvolt,rmt_set_ccurr,rmt_range_volt,rmt_range_curr,rmt_range_cvolt,rmt_range_ccurr;

int16_t menu_items_val[MENU_ITEMS] = {0,0,0,0};
const char menu_items_text[MENU_ITEMS][DISPLAY_LEN] = {"AVERAGE COUNT  ","SENSE REMOTE   ","NULL FORCE     ","NULL MEASURE   "};
const int16_t menu_items_limit_max[MENU_ITEMS] = {16,1,1,1};
const int16_t menu_items_limit_min[MENU_ITEMS] = {1,0,0,0};

scpi_t scpi_context;
static char scpi_input_buffer[SCPI_INPUT_BUFFER_LENGTH];
char smbuffer[SMALL_BUFFER_LEN];
scpi_error_t scpi_error_queue_data[SCPI_ERROR_QUEUE_SIZE];

/*******************************************************************************************************************************/
// SCPI callbacks
// thouse would feel home in separate .c file, but since many of the variables are
// in the large global section, here you go. There is path in exposing the desired variables
// into another file via extern (ouch) or properly via appropriate functions, but for sake
// of simplicity I kept it this way.
static scpi_result_t EXT_QCalList(scpi_t * context)
	{
	char out_str[50];
	uint8_t i;
	int32_t cal_val;
	for (i=0;i<CAL_CONST_NUM;i++)
		{
		cal_val = get_cal_const_num(i,&cal_const);
		sprintf(out_str," %d %ld    %s\n",i,cal_val,cal_val_desc[i]);
		uart1_txs(out_str);
		}
	return SCPI_RES_OK;
	}

static scpi_result_t EXT_QCalDump(scpi_t * context)
	{
	uint8_t i;
	int32_t cal_val;
	for (i=0;i<CAL_CONST_NUM;i++)
		{
		cal_val = get_cal_const_num(i,&cal_const);
		SCPI_ResultInt32(context,cal_val);
		}
	
	return SCPI_RES_OK;
	}

static scpi_result_t SCPI_QRepsGreet (scpi_t * context)
	{
	SCPI_ResultMnemonic(context, "MOIN\n");
	return SCPI_RES_OK;
	}

static scpi_result_t EXT_QSensVoltProt(scpi_t * context)
	{
	SCPI_ResultDouble(context, rmt_set_cvolt);	
	return SCPI_RES_OK;
	}

static scpi_result_t EXT_QSensCurrProt(scpi_t * context)
	{
	SCPI_ResultDouble(context, rmt_set_ccurr);	
	return SCPI_RES_OK;
	}

static scpi_result_t EXT_QSensVoltRange(scpi_t * context)
	{
	SCPI_ResultDouble(context, rmt_range_cvolt);	
	return SCPI_RES_OK;
	}

static scpi_result_t EXT_QSensCurrRange(scpi_t * context)
	{
	SCPI_ResultDouble(context, rmt_range_ccurr);	
	return SCPI_RES_OK;
	}

static scpi_result_t EXT_QSourceVoltLevel(scpi_t * context)
	{
	SCPI_ResultDouble(context, rmt_set_volt);	
	return SCPI_RES_OK;
	}

static scpi_result_t EXT_QSourceCurrLevel(scpi_t * context)
	{
	SCPI_ResultDouble(context, rmt_set_curr);	
	return SCPI_RES_OK;
	}

static scpi_result_t EXT_QSourceVoltRange(scpi_t * context)
	{
    SCPI_ResultDouble(context, range_volt);	
	return SCPI_RES_OK;
	}

static scpi_result_t EXT_QSourceCurrRange(scpi_t * context)
	{
    SCPI_ResultDouble(context, range_curr);	
	return SCPI_RES_OK;
	}

static scpi_result_t EXT_QSourceFunction(scpi_t * context)
	{
    SCPI_ResultDouble(context, out_mode);
	return SCPI_RES_OK;
	}

static scpi_result_t EXT_QMeasVolt(scpi_t * context)
	{
    SCPI_ResultFloat(context, conv_setvolt_fval(meas_volt,range_volt)/10.0);	
	return SCPI_RES_OK;
	}
static scpi_result_t EXT_QMeasCurr(scpi_t * context)
	{
    SCPI_ResultFloat(context, conv_setcurr_fval(meas_cur,range_curr)/10.0);	
	return SCPI_RES_OK;
	}
	
scpi_choice_def_t source_mode[] = {
	{"CURRent", 0},
    {"VOLT", 1},
    SCPI_CHOICE_LIST_END /* termination of option list */
};

static scpi_result_t EXT_SourceFunction(scpi_t * context) 
	{
    int32_t param;
    const char * name;
    if (!SCPI_ParamChoice(context, source_mode, &param, TRUE)) {
        return SCPI_RES_ERR;
    }
    SCPI_ChoiceToName(source_mode, param, &name);
	rmt_out_mode = param;
    return SCPI_RES_OK;
	}

static scpi_result_t EXT_SourceVoltRange(scpi_t * context)
	{
	scpi_number_t param1;
    if (!SCPI_ParamNumber(context, scpi_special_numbers_def, &param1, FALSE)) {
    }
	rmt_range_volt = param1.content.value;
//	conv_fval_setvolt(conv_setvolt_fval(set_volt,range_volt),param1.content.value,&set_volt,&range_volt,src_volt_autorange,0);
	return SCPI_RES_OK;
	}

static scpi_result_t EXT_SourceCurrRange(scpi_t * context)
	{
	scpi_number_t param1;
    if (!SCPI_ParamNumber(context, scpi_special_numbers_def, &param1, FALSE)) {
    }
	rmt_range_curr = param1.content.value;
	//conv_fval_setcurr(conv_setcurr_fval(set_curr,range_curr),param1.content.value,&set_curr,&range_curr,src_curr_autorange,0);
	return SCPI_RES_OK;
	}
static scpi_result_t EXT_SourceVoltLevel(scpi_t * context)
	{
	scpi_number_t param1;
    if (!SCPI_ParamNumber(context, scpi_special_numbers_def, &param1, FALSE)) {
    }
	//conv_fval_setvolt(param1.content.value,param1.content.value,&set_volt,&range_volt,src_volt_autorange,1);
	rmt_set_volt = param1.content.value;
	conv_fval_setvolt(rmt_set_volt,rmt_range_volt,&set_volt,&range_volt,rmt_src_volt_autorange);
	if (out_state==1) out_update=1;
	return SCPI_RES_OK;
	}

static scpi_result_t EXT_SourceCurrLevel(scpi_t * context)
	{
	scpi_number_t param1;
    if (!SCPI_ParamNumber(context, scpi_special_numbers_def, &param1, FALSE)) {
    }
	//conv_fval_setcurr(param1.content.value,param1.content.value,&set_curr,&range_curr,src_curr_autorange,1);
	rmt_set_curr = param1.content.value;
	conv_fval_setcurr(rmt_set_curr,rmt_range_curr,&set_curr,&range_curr,rmt_src_curr_autorange);
	if (out_state==1) out_update=1;
	return SCPI_RES_OK;
	}

static scpi_result_t EXT_SensVoltProt(scpi_t * context)
	{
	scpi_number_t param1;
    if (!SCPI_ParamNumber(context, scpi_special_numbers_def, &param1, FALSE)) {
    }
	rmt_set_cvolt = param1.content.value;
	conv_fval_setvolt(rmt_set_cvolt,rmt_range_cvolt,&clamp_volt,&range_volt,rmt_src_volt_autorange);
	if (out_state==1) out_update=1;
	return SCPI_RES_OK;
	}
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

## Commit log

2021-08-13 updated readme, added majority of files
    [other_material.ods, push_rod_1.stl, push_rod_2.stl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]
2021-08-13 updated BOM
    [smu_A1.ods, smu_A2.ods, smu_D1.ods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]
2021-08-14 schematics touch-up
2021-08-14 corrected error in PSU schematics
    [smu_pwr_1.sch]
2022-02-24 SPCI control added
    [scpi.g]
